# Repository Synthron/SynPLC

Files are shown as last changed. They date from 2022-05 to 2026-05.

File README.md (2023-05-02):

# SynPLC

Open Source modular PLC with Microcontrollers

**WORK IN PROGRESS**

# To-Dos

## Repo

- [x] Rewrite documentation in english
- [x] add reviewed PCBs
- [ ] fill out tech specs of modules once programmed
- [ ] Cleanup Repo
  - [ ] better folder structure
  - [X] delete obsolete files

## Hardware

- [x] Order new PCBs with STM32s
- [x] Assemble new PCBs
- [ ] Test new hardware
  - [X] DO
  - [X] DI
  - [ ] AO
  - [ ] AI
  - [ ] XT
- [ ] New Modules
  - [ ] CPU V2
    - [X] Layout
    - [X] Review
    - [ ] Ordered
  - [ ] Relais Module
  - [ ] PWM Module

## Software

- [ ] Write Software for new PCBs
  - [ ] CPU
  - [ ] DO
  - [ ] DI
  - [ ] AO
  - [ ] AI
  - [ ] XT
- [ ] Porting of SR485 protocol to new hardware
  - [ ] Make it use Interrupts
  - [ ] Make it more efficient (processing)
  - [ ] implement failsafes when no answer
- [ ] Define and program CAN protocol
- [ ] Write generalized Code for CPU
- [ ] ~~define structured Text~~ (postponed)
- [ ] ~~import structured text and parse into running code~~ (postponed)

## Possible Fixes

- [x] ~~MAX485 with 5V supply voltage on all IO modules ?~~
  - changed to 3V3 on the CPU
- [x] DIs and DO (alt. switches) re-soldering (dead channels)
- [x] better connector for CPU
- [ ] parametrize RS485 lib a bit more (tbd)

## issues

- [x] weird additional bytes sent by slave after ACK and CS???
  - resolved

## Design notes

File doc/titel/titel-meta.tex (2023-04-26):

\makeatletter                       
\def\printauthor{         
    {\large \@author}}              
\makeatother
\author{
    Marco Müller \\ 
    \vspace*{12pt}
    gitlab.synthron.de \\
    \texttt{synthron@synthron.de}
    }

\renewcommand\epigraphflush{flushright}
\renewcommand\epigraphsize{\normalsize}
\setlength\epigraphwidth{0.7\textwidth}

\definecolor{Green}{gray}{0.55}

\newcommand\anglei{-45}
\newcommand\angleii{-45}
\newcommand\angleiii{-225}
\newcommand\angleiv{135}

\newcommand\titlepagedecoration{%
\begin{tikzpicture}[remember picture,overlay,shorten >= -10pt]

\coordinate (aux1) at ([yshift=-15pt]current page.north east);
\coordinate (aux2) at ([yshift=-410pt]current page.north east);
\coordinate (aux3) at ([xshift=-4.5cm]current page.north east);
\coordinate (aux4) at ([yshift=-150pt]current page.north east);

\begin{scope}[titlepagecolor!40,line width=12pt,rounded corners=12pt]
\draw
  (aux1) -- coordinate (a)
  ++(225:5) --
  ++(-45:5.1) coordinate (b);
\draw[shorten <= -10pt]
  (aux3) --
  (a) --
  (aux1);
\draw[opacity=0.6,titlepagecolor,shorten <= -10pt]
  (b) --
  ++(225:2.2) --
  ++(-45:2.2);
\end{scope}
\draw[titlepagecolor,line width=8pt,rounded corners=8pt,shorten <= -10pt]
  (aux4) --
  ++(225:0.8) --
  ++(-45:0.8);
\begin{scope}[titlepagecolor!70,line width=6pt,rounded corners=8pt]
\draw[shorten <= -10pt]
  (aux2) --
  ++(225:3) coordinate[pos=0.45] (c) --
  ++(-45:3.1);
\draw
  (aux2) --
  (c) --
  ++(135:2.5) --
  ++(45:2.5) --
  ++(-45:2.5) coordinate[pos=0.3] (d);   
\draw 
  (d) -- +(45:1);
\end{scope}
\end{tikzpicture}%
}
\newcommand\chapterdecoration{%
\begin{tikzpicture}[remember picture,overlay,shorten >= -10pt]
\coordinate (aux1) at ([yshift=-15pt]current page.north west);
\coordinate (aux2) at ([yshift=-310pt]current page.north west);
\coordinate (aux3) at ([xshift=4.5cm]current page.north west);
\coordinate (aux4) at ([yshift=-150pt]current page.north west);
\coordinate (aux5) at ([yshift=-535pt]current page.north west);
\coordinate (aux6) at ([yshift=-660pt]current page.north west);
\coordinate (aux7) at ([yshift=-630pt]current page.north west);
\coordinate (aux8) at ([xshift=-16.5cm]current page.south east);
\renewcommand\anglei{-135}
\renewcommand\angleii{135}
\renewcommand\angleiii{-45}
\renewcommand\angleiv{45}

\begin{scope}[titlepagecolor1!70,line width=6pt,rounded corners=8pt]
\draw[shorten <= -10pt]
  (aux2) --
  ++(\angleiii:3) coordinate[pos=0.4] (d) --
  ++(\anglei:3.1);

\draw
  (d) --
  ++(\angleiii:.1) --
 ++(\angleiii:1.7) --
  ++(\anglei:1.5) --
++(\angleiii:2.5) --
++(\anglei:2.5) --
++(\angleii:2) --
++(\angleiii:1.3) --
++(\anglei:1.3) 
 
coordinate[pos=0.3] (c); 
\begin{scope}[titlepagecolor1!40,line width=12pt,rounded corners=12pt]
\draw
  (aux7) -- coordinate (a)
  ++(\angleiii:5) --
  ++(\anglei:5.1) coordinate (b);
\draw[shorten <= -10pt]
  
  (b) -- 
++(\angleiv:2.5) --
++(\angleiii:5) 
  (aux8);
\draw[opacity=0.6,titlepagecolor1,shorten <= -10pt]
  (aux5) --
  ++(\angleiii:2.2) --
  ++(\anglei:2.2);
\draw[titlepagecolor1,line width=8pt,rounded corners=8pt,shorten <= -10pt]
  (aux6) --
  ++(\angleiii:0.8) --
  ++(\anglei:0.8);
\end{scope}
  
\end{scope}
\end{tikzpicture}%
}

% Old Code for reference
%
%
%
%\newcommand\titlepagedecoration{
%\begin{tikzpicture}[remember picture,overlay,shorten >= -10pt]
%
%\coordinate (aux1) at ([yshift=-15pt]current page.north east);
%\coordinate (aux2) at ([yshift=-410pt]current page.north east);
%\coordinate (aux3) at ([xshift=-4.5cm]current page.north east);
%\coordinate (aux4) at ([yshift=-150pt]current page.north east);
%
%\begin{scope}[titlepagecolor!40,line width=12pt,rounded corners=12pt]
%\draw
%  (aux1) -- coordinate (a)
%  ++(225:5) --
%  ++(-45:5.1) coordinate (b);
%\draw[shorten <= -10pt]
%  (aux3) --
%  (a) --
%  (aux1);
%\draw[opacity=0.6,titlepagecolor,shorten <= -10pt]
%  (b) --
%  ++(225:2.2) --
%  ++(-45:2.2);
%\end{scope}
%\draw[titlepagecolor,line width=8pt,rounded corners=8pt,shorten <= -10pt]
%  (aux4) --
%  ++(225:0.8) --
%  ++(-45:0.8);
%\begin{scope}[titlepagecolor!70,line width=6pt,rounded corners=8pt]
%\draw[shorten <= -10pt]
%  (aux2) --
%  ++(225:3) coordinate[pos=0.45] (c) --
%  ++(-45:3.1);
%\draw
%  (aux2) --
%  (c) --
%  ++(135:2.5) --
%  ++(45:2.5) --
%  ++(-45:2.5) coordinate[pos=0.3] (d);   
%\draw 
%  (d) -- +(45:1);
%\end{scope}
%\end{tikzpicture}
%}

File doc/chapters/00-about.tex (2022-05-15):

\chapter{About}

This document will describe the workings of the SynPLC.

The SynPLC is meant to be an OpenSource PLC system for home automation purposes. It can supply digital and analog IO as well as different modules for a variety of different applications, e.g. Phase-Fired Control of AC voltages. 

\section{The Origins}

This project was created of the idea that in theory one could build a LOGO!-type PLC system from Arduinos. After some research and a few failed attempts it evolved into the current state, using STM32 Microcontrollers. 

\section{License}
All resources and documents for the SynPLC project are distributed under the Creative Commons CC-BY-SA 4.0 license.

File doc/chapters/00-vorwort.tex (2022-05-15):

\chapter{Vorwort}
Die SynPLC entstand durch die Idee, einen 24V-kompatiblen Arduino zu entwickeln. Als festgestellt wurde, dass man damit eine LOGO nachbilden könnte, hat mich die Idee gefasst, eine eigene SPS zu entwickeln. 
Also wurden auf Gutdünken einige Konzepte gemacht und folgendes kam dabei raus.

Module V1.0: 
\begin{itemize}
    \item CPU-Modul
    \item DO-Modul
    \item DI-Modul
    \item AO-Modul
\end{itemize}

Folgende Module befinden sich noch in Planung:
\begin{itemize}
    \item AI-Modul
    \item Interface/PWM-Modul
    \item Phasenanschnittmodul
\end{itemize}

Für den Anfang werden die Programme dafür noch in C auf die CPU geflasht, später soll per Strukturiertem Text ein Programm per SD-Karte ladbar sein.

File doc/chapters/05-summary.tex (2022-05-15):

\chapter{Summary}

The SynPLC project is a PLC system using STM32 microcontrollers and off-the-shelf hardware. For the current version the following modules are available:

\begin{itemize}
    \item CPU module
    \item Digital Output module
    \item Digital Input module
    \item Analog Output module
    \item Analog Input module
    \item Triac PFC module
\end{itemize}

The following modules are planned, but not yet under development:

\begin{itemize}
    \item PWM module
    \item Relais module
    \item Thermocouple module
\end{itemize}

For further information and technical specs, please look into the section  "Modules".

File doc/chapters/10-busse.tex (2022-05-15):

\chapter{Bus-Systeme}
Die CPU unterstützt nativ zwei Bus-Physiken:
\begin{itemize}
    \item RS485
    \item CAN
\end{itemize}

Für die IO-Module V1 wird nur RS485 unterstützt. Dazu wird auf der CPU die Steckbrücke für den Backplane entsprechend gesetzt.

%\section{RS485}
%Der RS485-Bus ist für die IO-Module der V1 vorgesehen. Dieser ist einfach auch auf kleineren und günstigeren Controllern zu nutzen und bietet genug Sicherheit über längere Strecken durch seinen differentiellen Aufbau.

%Ursprünglich war angedacht, hier das ModBus RTU Protokoll zu nutzen, allerdings wurde dagegen entschieden und ein eigenes Protokoll entwickelt, was direkter ist und einige Funktionen mehr unterstützt. Auch sind die Funktionen auf die IO-Module zurechtgeschnitten.

%\subsection{Adressen}
%Es wird ein 8-bit Adressverfahren genutzt. Dies passt in die seriellen Buffer der Controller. Außerdem ist nicht vorgesehen, mehr als 32 Geräte eines Typs gleichzeitig zu benutzen. Damit die CPU von sich aus weiß, welches Modul auf welcher Adresse ist, sind die Adressen kodiert. 

%\begin{table}[h]
%    \centering
%\begin{tabular}{|c|c|}
%    \hline
%    Modul       &   Adressbereich   \\ \hline \hline
%    CPU         &   111X XXXX       \\ \hline
%    Inferface   &   001X XXXX       \\ \hline
%    Digital Out &   010X XXXX       \\ \hline
%%    Digital In  &   011X XXXX       \\ \hline
%    Analog Out  &   100X XXXX       \\ \hline
%    Analog In   &   101X XXXX       \\ \hline
%    PWM         &   110X XXXX       \\ \hline
%\end{tabular}
%\caption{Adressen RS485}
%\label{tab:Adressen RS485}
%\end{table}

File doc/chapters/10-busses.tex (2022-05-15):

\chapter{Busses}

Every module has at least one common bus connector connecting via ribbon cable to the other modules. Alongside the 5V and GND voltage supply there also is the communication bus lines. On the modules there are two different busses possible: RS485 and CAN. 

In order to maintain a stable communication, consider the use of twisted-pair ribbon cables.

Both are working on a custom protocol, which is easy to implement on other controllers too. 

\section{RS485}

\subsection{Baudrate and Transmission speed}
The RS485 bus is transceiving at 250kBaud. At a maximum of 10 Bytes per frame, this results in a minimum rate of around 3000 frames per second.

\subsection{Frame Structure}
The frame structure of the protocol is as follows:
\vspace{0.5cm}

\begin{tabular}{cl}
    \textbf{Byte Number}     & \textbf{Data}                      \\
    1               & Startbyte (0x5A)          \\
    2               & Slave Adress              \\
    3               & Instruction and Register  \\
    4               & Data (Not used when Instruction == Scan or Read) \\
    5               & Data (only used at 12- or 16bit data blocks) \\
    6               & Checksum \\
    \\
    7               & Answer from Slave (ACK or NACK with Error code) \\
    8               & Answer from Slave (data, LSB at 12- or 16bit data blocks) \\
    9               & Answer from Slave (data, MSB at 12- or 16bit data blocks) \\
    10              & Answer from Slave (Checksum)
\end{tabular}
\vspace{0.5cm}

As you can see, most of the frame consists of the CPU talking to the slaves. Startbyte and Checksums are in place to make sure that an error free communication is possible. 

The Checksum itself is easily calculated. This is done by XOR-ing all sent bytes with the constant value 0xC5. In summary, the equation is as follows:

\begin{equation}
    Checksum = 0xC5 \oplus Byte\_1 \oplus Byte\_2 \oplus Byte\_3 (\oplus Byte\_4 \oplus Byte\_5)
\end{equation}

Equally, the slaves are calculating their checksum with the same method, XOR-ing all their bytes with 0xC5. 

If all the bytes are XOR-ed with each other and with the checksum itself and 0xC5 is still left, then the communication was error free and the data is uncompromized.

\subsection{Slave Addresses}
The slave addresses are an 8bit number which consist of a 3-bit module identifier and a 5-bit address settable via dip-switches on the respective module.

The module identifiers are definied as follows:

\begin{table}[H]
    \centering
        \begin{tabular}{|c|c|}
            \hline
            Identifier & Modul \\ \hline \hline
            000 & Digital Input \\ \hline
            001 & Digital Output \\ \hline
            010 & Analog Input \\ \hline
            011 & Analog Output \\ \hline
            100 & PWM Modul \\ \hline
            101 & Thyristor Modul \\ \hline
            110 & Relais Modul \\ \hline
            111 & \textit{reserved}    \\ \hline
        \end{tabular}
\end{table}

\subsection{Instructions}

In Byte 3 of the communication protocol are the instruction and the corresponding register specified. For more information on the registers, please refer to the corresponing module section in this document.

The instructions are at the 4 MSBs of the byte. They are as follows:

\begin{table}[H]
    \centering
        \begin{tabular}{|c|c|}
            \hline
            Instruction-Code & Instruction \\ \hline \hline
            0000 xxxx   & Bus Scanning (is slave available?) - no data byte \\ \hline
            0001 (reg)  & Read 8bit-Register\\ \hline
            0010 (reg)  & Write 8bit-Register \\ \hline
            0101 (reg)  & Read 16bit-Register \\ \hline
            0110 (reg)  & Write 16bit-Register \\ \hline
        \end{tabular}
\end{table}

\subsection{ACK, NACK and Error Codes}
In order to know weather the communication was successful, there is a byte used specifically for ACK/NACK and Error codes. This byte is divided into 2 nibbles, where the first nibble is the ACK/NACK and the second nibble is the error code. If everything is fine, the ACK nibble will be 0xC0 (1100). If there is an error present, it will display the NACK status with 0x03 (0011).

The following nibble will show which exactly went wrong:

\begin{table}[H]
    \centering
        \begin{tabular}{|c|c|}
            \hline
            Error Code & Meaning \\ \hline \hline
            0000 & No Error \\ \hline
            0001 & Target Register invalid \\ \hline
            0010 & Instruction invalid \\ \hline
            1100 & Processing Error - read Error Register \\ \hline
            1101 & Checksum Error - Send again \\ \hline
            1111 & System Error - read Error Register \\ \hline
        \end{tabular}
\end{table}

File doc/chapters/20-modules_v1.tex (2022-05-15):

\chapter{Modules V1}
All V1 modules are now discontinued. The successors are the V2 modules.

\vspace{2cm}

\textbf{Further information:}

V1 was meant to be a Proof of Concept system using easy-to-program ATmega328P with Arduino framework. 

The Hardware was not as refined as wanted and a lot of compromises were made resulting in high production costs and hard-to-source parts. 

\chapter{Modules V2}
These are the current module revisions. If not stated otherwise, every module is powered by a STM32F103 microcontroller. 

Every module is capable of both CAN and RS485, but not simultaneously. To select one of the two bus systems, set the Jumpers on the boards accodingly.

\vspace{1cm}

V2 was designed with the mindset of more generic circuitry without losing accuracy or stability. Even tho not every module was improved (talking about you, DO8...) major steps were made on the analog modules. In addition, the triac module (XP) is in testing now.

Also all V1 modules got discontinued and decommissioned.\pagebreak

\section{CPU}
The CPU is the heart of the PLC system and necessary for normal operation. It connects to all IO-modules and processes all the data.

The CPU has the following interfaces:

\begin{itemize}
    \item RS485 and CAN Businterface
    \item USB-Interface for serial monitor
    \item ESP01-Modul as Webinterface (read-only as of now)
    \item SD-card for structured text (WIP) and log files
    \item DC/DC-Converter as power supply for the whole system
\end{itemize}

The DC/DC-Converter uses an ESD-safe 24V DC-input to generate 5V DC at 10W output power. This voltage is available at the bus connector and providing power to all modules in the system.

It has no seperate ID since it is a one-of-a-kind module. In later revisions, there will be measures for redundancy available, but not for now.

\section{DO8}
The DO8 (Digital Output 8-channel) is providing 8 channels of 24V compatible outputs with a current rating of 0.5A each. The channels are galvanically isolated from the system voltage via optoisolators. 

The 24V Output voltage has to be supplied on the connector. 

To prevent major faults caused by short circuits, the output channels are measured back and compared to their set value. If a channel differs from its value, the module sets an error bit and shuts off the faulty channel.

On the front are 8 LEDs, indicating the status of the output channels. 

%hier noch die Register beschreiben

\section{DI}
The DI8 (Digital Input 8-channel) is providing 8 channels of 24V compatiple inputs, divided into two sets of 4 Inputs where both sets are galvanically isolated from each other. The maximum input current is limited to 2mA. The channels are galvanically isolated from the system voltage via optoisolators.

For normal operation, the system ground fromt the inputs need to be connected. 

The channels are ESD safe and can tolerate up to 33V DC. Reverse-Polarity and overcurrent protections are in place. 

A digital Low-Level is defined as 0..5 VDC.

A digital HIGH-Level is defined as 10..33 VDC.

% Hier die Register beschreiben

\section{AO}
The AO4 (Analog Output 4-channel) is providing 4 channels of analog output, each capable of supplying either 0..10V CV or 0..20mA CC at a resolution of 12bits. The switch between CV and CC is managed by a relay.

The output resolution is set at 16bits, giving a 0.15mV or 0.30$\mu$A resolution. 

The channels are electrically isolated from the system, so at least 15V with common analog grond have to be provided.

On the front are 4 LEDs indicating if the channel is actively being used. 

% Hier die Register beschreiben

\section{AI}
The AI4 (Analog Input 4-channel) is providing 4 channels of analog inputs, capable of meauring 0..10V or 0..20mA each. 

The input resolution is set at 12bits. At a maximum input volatage of 10V or input current of 20mA, this is giving a resolution of 2.4mV or 4.8mA.

The channels are electrically isolated from the system.

\section{XT}
The XT4 (Interface Triac 4-channel) is providing 4 triacs on two seperate voltage domains. The channels can be used to either switch AC voltage to a supply or even using them in a PFC (phase-fired controller) mode. 

For PFC mode each voltage domain has a Zero-Crossing-Detection (ZCD) and can control the triacs with PWM. The ZCD also calculates the frequency of the AC voltage automatically and compensates for frequency drift. 

Each channel is rated for up to 230V and 1A. Keep in mind that the triacs can become quite hot. 

All channels are electrically isolated from the system. The two voltage domains are also isolated from each other.

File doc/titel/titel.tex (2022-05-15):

\begin{titlepage}

\vspace*{2cm}
\noindent
\titlefont \Titel\par
\epigraph{\Caption}
{\SignateAuthor\\ \Stand}
\vspace*{2cm}
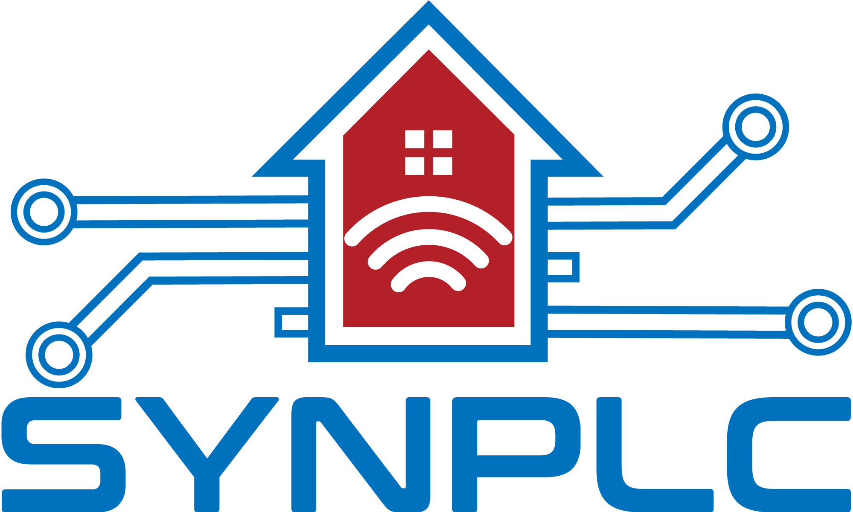
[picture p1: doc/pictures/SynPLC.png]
\centering{}
\null\vfill
\vspace*{1cm}
\noindent
\hfill
\begin{minipage}{0.4\linewidth}
    \begin{flushright}
        \printauthor
    \end{flushright}
\end{minipage}
%
\begin{minipage}{0.02\linewidth}
    \rule{1pt}{80pt}
\end{minipage}
\titlepagedecoration
\chapterdecoration
\end{titlepage}

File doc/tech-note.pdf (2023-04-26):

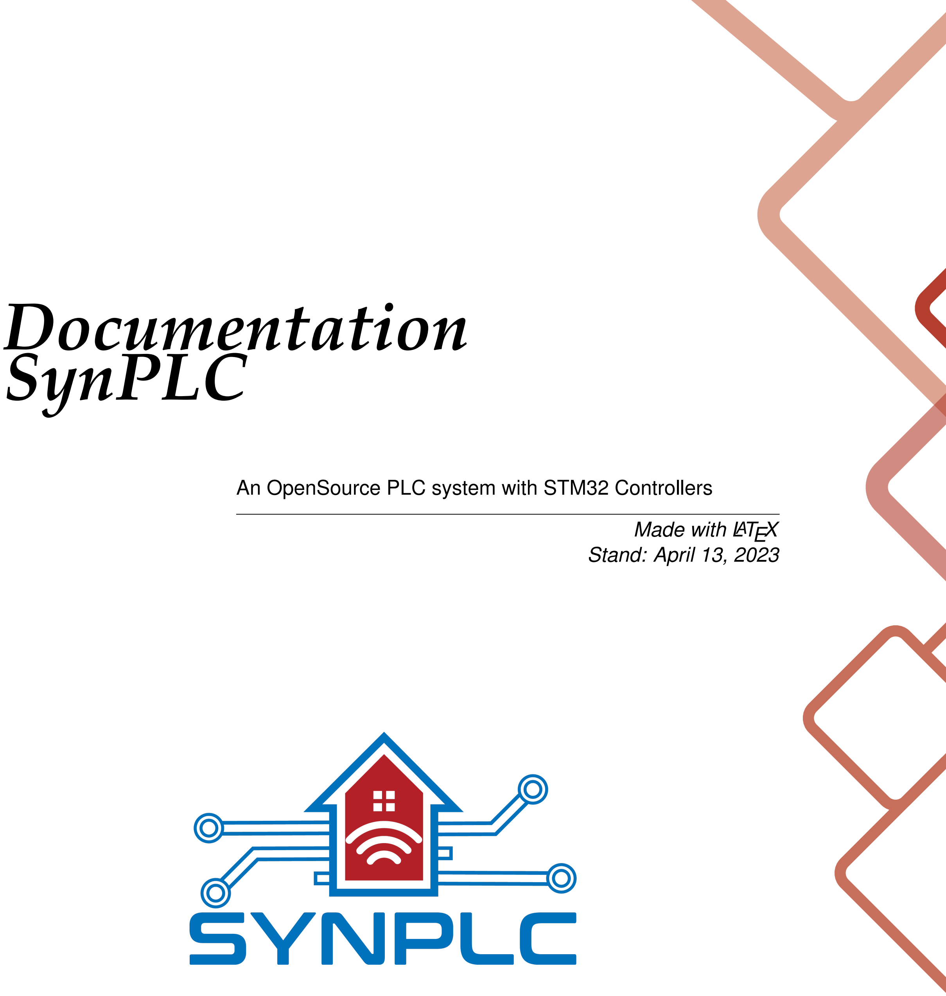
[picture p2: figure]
Documentation SynPLC; Made with LATEX Stand: April 13, 2023

An OpenSource PLC system with STM32 Controllers

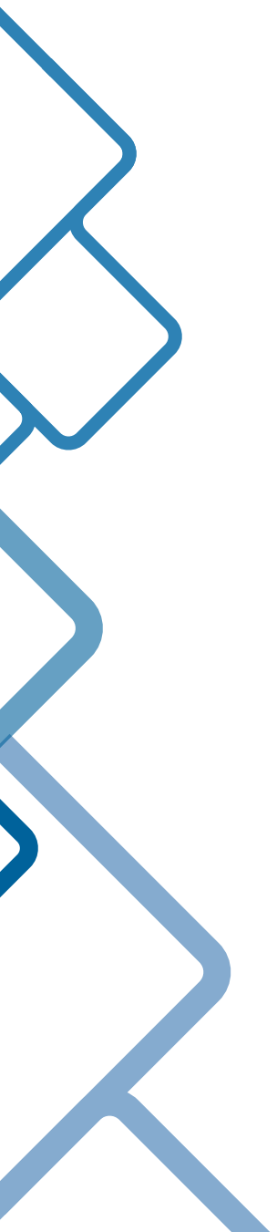
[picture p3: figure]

Marco Muller ¨

gitlab.synthron.de
synthron@synthron.de

I. Table of Contents

# Contents

I. List of Figures | II
II. List of Tables | III
1. About | 1
2. Summary | 2
3. Busses | 3
4. Modules V1 | 6
5. Modules V2 | 7

I

II. List of Tables

# I. List of Figures

II

III. List of Figures

# II. List of Tables

III

April 13, 2023 | SynPLC V2.0 | Marco Muller ¨

# 1. About

This document will describe the workings of the SynPLC.

The SynPLC is meant to be an OpenSource PLC system for home automation purposes. It can supply digital and analog IO as well as different modules for a variety of different applications, e.g. Phase-Fired Control of AC voltages.

## 1.1. The Origins

This project was created of the idea that in theory one could build a LOGO!-type PLC system from Arduinos. After some research and a few failed attempts it evolved into the current state, using STM32 Microcontrollers.

## 1.2. License

All resources and documents for the SynPLC project are distributed under the Creative Commons CC-BY-SA 4.0 license.

# 2. Summary

The SynPLC project is a PLC system using STM32 microcontrollers and off-the-shelf hardware. For the current version the following modules are available:

- CPU module
- Digital Output module
- Digital Input module
- Analog Output module
- Analog Input module
- Triac PFC module

The following modules are planned, but not yet under development:

- PWM module
- Relais module
- Thermocouple module

For further information and technical specs, please look into the section ”Modules”.

# 3. Busses

Every module has at least one common bus connector connecting via ribbon cable to the other modules. Alongside the 5V and GND voltage supply there also is the communication bus lines. On the modules there are two different busses possible: RS485 and CAN.

In order to maintain a stable communication, consider the use of twisted-pair ribbon cables.

Both are working on a custom protocol, which is easy to implement on other controllers too.

## 3.1. RS485

### 3.1.1. Baudrate and Transmission speed

The RS485 bus is transceiving at 250kBaud. At a maximum of 10 Bytes per frame, this results in a minimum rate of around 3000 frames per second.

### 3.1.2. Frame Structure

The frame structure of the protocol is as follows:

Byte Number Data
1 | Startbyte (0x5A)
2 | Slave Adress
3 | Instruction and Register
4 | Data (Not used when Instruction == Scan or Read)
5 | Data (only used at 12- or 16bit data blocks)
6 | Checksum
7 | Answer from Slave (ACK or NACK with Error code)
8 | Answer from Slave (data, LSB at 12- or 16bit data blocks)
9 | Answer from Slave (data, MSB at 12- or 16bit data blocks)
10 | Answer from Slave (Checksum)

As you can see, most of the frame consists of the CPU talking to the slaves. Startbyte and Checksums are in place to make sure that an error free communication is possible.

The Checksum itself is easily calculated. This is done by XOR-ing all sent bytes with the constant value 0xC5. In summary, the equation is as follows:

Checksum = 0xC5 ⊕ Byte 1 ⊕ Byte 2 ⊕ Byte 3(⊕Byte 4 ⊕ Byte 5) (3.1)

Equally, the slaves are calculating their checksum with the same method, XOR-ing all their bytes with 0xC5.

If all the bytes are XOR-ed with each other and with the checksum itself and 0xC5 is still left, then the communication was error free and the data is uncompromized.

### 3.1.3. Slave Addresses

The slave addresses are an 8bit number which consist of a 3-bit module identifier and a 5-bit address settable via dip-switches on the respective module.

The module identifiers are definied as follows:

Identifier | Modul
000 | Digital Input
001 | Digital Output
010 | Analog Input
011 | Analog Output
100 | PWM Modul
101 | Thyristor Modul
110 | Relais Modul
111 | reserved

### 3.1.4. Instructions

In Byte 3 of the communication protocol are the instruction and the corresponding register specified. For more information on the registers, please refer to the corresponing module section in this document.

The instructions are at the 4 MSBs of the byte. They are as follows:

Instruction-Code | Instruction
0000 xxxx | Bus Scanning (is slave available?) - no data byte
0001 (reg) | Read 8bit-Register
0010 (reg) | Write 8bit-Register
0101 (reg) | Read 16bit-Register
0110 (reg) | Write 16bit-Register

### 3.1.5. ACK, NACK and Error Codes

In order to know weather the communication was successful, there is a byte used specifically for ACK/NACK and Error codes. This byte is divided into 2 nibbles, where the first nibble is the ACK/NACK and the second nibble is the error code. If everything is fine, the ACK nibble will be 0xC0 (1100). If there is an error present, it will display the NACK status with 0x03 (0011).

The following nibble will show which exactly went wrong:

Error Code | Meaning
0000 | No Error
0001 | Target Register invalid
0010 | Instruction invalid
1100 | Processing Error - read Error Register
1101 | Checksum Error - Send again
1111 | System Error - read Error Register

# 4. Modules V1

All V1 modules are now discontinued. The successors are the V2 modules.

Further information:

V1 was meant to be a Proof of Concept system using easy-to-program ATmega328P with Arduino framework.

The Hardware was not as refined as wanted and a lot of compromises were made resulting in high production costs and hard-to-source parts.

# 5. Modules V2

These are the current module revisions. If not stated otherwise, every module is powered by a STM32F103 microcontroller.

Every module is capable of both CAN and RS485, but not simultaneously. To select one of the two bus systems, set the Jumpers on the boards accodingly.

V2 was designed with the mindset of more generic circuitry without losing accuracy or stability. Even tho not every module was improved (talking about you, DO8...) major steps were made on the analog modules. In addition, the triac module (XP) is in testing now.

Also all V1 modules got discontinued and decommissioned.

## 5.1. CPU

The CPU is the heart of the PLC system and necessary for normal operation. It connects to all IO-modules and processes all the data.

The CPU has the following interfaces:

- RS485 and CAN Businterface
- USB-Interface for serial monitor
- ESP01-Modul as Webinterface (read-only as of now)
- SD-card for structured text (WIP) and log files
- DC/DC-Converter as power supply for the whole system

The DC/DC-Converter uses an ESD-safe 24V DC-input to generate 5V DC at 10W output power. This voltage is available at the bus connector and providing power to all modules in the system.

It has no seperate ID since it is a one-of-a-kind module. In later revisions, there will be measures for redundancy available, but not for now.

## 5.2. DO8

The DO8 (Digital Output 8-channel) is providing 8 channels of 24V compatible outputs with a current rating of 0.5A each. The channels are galvanically isolated from the system voltage via optoisolators.

The 24V Output voltage has to be supplied on the connector.

To prevent major faults caused by short circuits, the output channels are measured back and compared to their set value. If a channel differs from its value, the module sets an error bit and shuts off the faulty channel.

On the front are 8 LEDs, indicating the status of the output channels.

## 5.3. DI

The DI8 (Digital Input 8-channel) is providing 8 channels of 24V compatiple inputs, divided into two sets of 4 Inputs where both sets are galvanically isolated from each other. The maximum input current is limited to 2mA. The channels are galvanically isolated from the system voltage via optoisolators.

For normal operation, the system ground fromt the inputs need to be connected.

The channels are ESD safe and can tolerate up to 33V DC. Reverse-Polarity and overcurrent protections are in place.

A digital Low-Level is defined as 0..5 VDC.

A digital HIGH-Level is defined as 10..33 VDC.

## 5.4. AO

The AO4 (Analog Output 4-channel) is providing 4 channels of analog output, each capable of supplying either 0..10V CV or 0..20mA CC at a resolution of 12bits. The switch between CV and CC is managed by a relay.

The output resolution is set at 16bits, giving a 0.15mV or 0.30μA resolution.

The channels are electrically isolated from the system, so at least 15V with common analog grond have to be provided.

On the front are 4 LEDs indicating if the channel is actively being used.

## 5.5. AI

The AI4 (Analog Input 4-channel) is providing 4 channels of analog inputs, capable of meauring 0..10V or 0..20mA each.

The input resolution is set at 12bits. At a maximum input volatage of 10V or input current of 20mA, this is giving a resolution of 2.4mV or 4.8mA.

The channels are electrically isolated from the system.

## 5.6. XT

The XT4 (Interface Triac 4-channel) is providing 4 triacs on two seperate voltage domains. The channels can be used to either switch AC voltage to a supply or even using them in a PFC (phase-fired controller) mode.

For PFC mode each voltage domain has a Zero-Crossing-Detection (ZCD) and can control the triacs with PWM. The ZCD also calculates the frequency of the AC voltage automatically and compensates for frequency drift.

Each channel is rated for up to 230V and 1A. Keep in mind that the triacs can become quite hot.

All channels are electrically isolated from the system. The two voltage domains are also isolated from each other.

# Appendix

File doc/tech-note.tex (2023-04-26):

\documentclass[11pt, a4paper, listof=numbered, captions=tableheading, headinclude, table, xcdraw]{scrreprt}

\usepackage[utf8]{inputenc}
\usepackage{tikz}
\usepackage{epigraph}
\usepackage{amsmath}
\usepackage{textgreek}
\usepackage[LGRgreek]{mathastext}
\usepackage{array}
\usepackage{color}
\usepackage{graphicx}
\usepackage{float}
\usepackage{helvet}
\usepackage{scrhack}
%\usepackage{circuitikz}
\renewcommand{\familydefault}{\sfdefault}

\setlength{\emergencystretch}{\hsize}
%\tolerance=9999
 
\newcounter{divide}

% für referenziertes Inhaltsverzeichnis
\usepackage[hidelinks, hypertexnames=false]{hyperref}

\usepackage{chngcntr}
\counterwithin*{chapter}{divide}

\renewcommand\epigraphflush{flushright}
\renewcommand\epigraphsize{\normalsize}
\setlength\epigraphwidth{0.7\textwidth}

\definecolor{titlepagecolor1}{cmyk}{1,.39,.0,.27}
\definecolor{titlepagecolor}{cmyk}{0,.82,.78,.30}

\DeclareFixedFont{\titlefont}{T1}{ppl}{b}{it}{0.5in}

\setlength{\parindent}{0pt}
\setlength{\parskip}{\baselineskip}

% Seitenränder festlegen
\usepackage[top=1.5cm,bottom=1.5cm, includeheadfoot]{geometry}

% ---------------------------------------
% Titeldefinition
\newcommand{\Titel}{Documentation\\SynPLC}
\newcommand{\Caption}{An OpenSource PLC system with STM32 Controllers}
\newcommand{\SignateAuthor}{\textit{Made with \LaTeX}}
\newcommand{\Stand}{\textit{Stand: \today}}
% Sonstiges in titel.ltx und titel-meta.ltx
% ---------------------------------------

% Kopf- und Fußzeile
\usepackage[automark]{scrlayer-scrpage}

% --------------------------------------------------------------------
% Titelblatt
% --------------------------------------------------------------------

\input{titel/titel-meta.tex}
\begin{document}
\input{titel/titel.tex}

% --------------------------------------------------------------------
% Verzeichnisse
% --------------------------------------------------------------------

\pagenumbering{Roman}
\renewcommand{\thechapter}{\Roman{chapter}}

\setcounter{tocdepth}{2} %Ausblenden von Subsections etc..
\cohead[I. Table of Contents]{I. Table of Contents}
\pagestyle{scrheadings}
\tableofcontents 	\newpage
\cohead[II. List of Tables]{II. List of Tables}
\pagestyle{scrheadings}
\listoffigures 		\newpage
\cohead[III. List of Figures]{III. List of Figures}
\pagestyle{scrheadings}
\listoftables 		\newpage
\pagenumbering{arabic}

\stepcounter{divide}

\renewcommand{\thechapter}{\arabic{chapter}}

% Kopfzeilen erst nach den Verzeichnissen

\lohead[\today]{\today}
\cohead[SynPLC V2.0]{SynPLC V2.0}
\rohead[Marco Müller]{Marco Müller}
\pagestyle{scrheadings}
 
% --------------------------------------------------------------------
% Ab hier der Inhalt
% --------------------------------------------------------------------

\input{chapters/00-about.tex} 				\newpage 	% Vorwort
\input{chapters/05-summary.tex}				\newpage
\input{chapters/10-busses.tex}				\newpage	% Bus Erklärung
\input{chapters/20-modules_v1.tex} 			\newpage	% Module V1

% --------------------------------------------------------------------
% abschließende Verzeichnisse
% --------------------------------------------------------------------

\pagestyle{empty}
\vspace*{\fill}
\begin{center}
\hrulefill\\
\vspace{4mm}
	\begin{HUGE}
		\textbf{Appendix}
	\end{HUGE}\\
\hrulefill
\end{center}
\vspace*{\fill}
\newpage
\pagestyle{plain}

\appendix

% --------------------------------------------------------------------
\end{document}

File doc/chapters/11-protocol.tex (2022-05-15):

\chapter{Protokoll RS485}

\begin{tabular}{lll}
Frame & & \\
&	byte 1:& 	Startbyte (0x5A) \\
&	byte 2:&	Slave adress \\
&	byte 3:& 	Instruction and register \\
&	byte 4:& 	data (not send when instruction == Scan or read) \\
&	byte 5:& 	data (only send when writing 16bit (MSB) register) \\
&	byte 6:& 	Checksum \\
&&	\\
&	byte 7:& 	Answer from slave (ACK or (NACK $\vert$ Errorcode)) \\
&	byte 8:& 	Answer from slave (data, 8bit read or LSB when 16bit read) \\
&	byte 9:& 	Answer from slave (data, MSB when 16bit read) \\
&	byte 10:& 	Answer from slave (Checksum) \\
\end{tabular}

Hier wird das Protokoll der RS485-Schnittstelle beschrieben.

\section{Genereller Aufbau}

\subsection{Baudrate}

Der RS485-Bus wird mit einer Baudrate von 250.000 Baud betrieben.

\section{Protokoll}
\subsection{Ablauf}
Je gesamtem Frame (eine erfolgreiche Datenübertragung) werden 3-5 Byte übertragen. Dieses Frame setzt sich wie folgt zusammen:
\begin{itemize}
    \item von CPU:
    \begin{enumerate}
        \item Slave-Adresse (1 Byte)
        \item Befehl und Register (1 Byte)
        \item Daten (1 oder 2 Byte)
    \end{enumerate}
    \item von Slave
    \begin{enumerate}
        \item ACK und Fehlercode (1 Byte)
    \end{enumerate}
\end{itemize}

Je nach Slave können mehrere Frames für die vollständige Datenübertragung vonnöten sein. 

\subsection{Slave-Adresse}
Die Slave-Adresse besteht aus 2 Teilen:
\begin{itemize}
    \item Modul-Identifier (3 bit)
    \item Adresse ( 5 bit)
\end{itemize}

Der Modul-Identifier ist in Software festgelegt und bezeichnet die Art des Moduls:

\begin{table}[H]
    \centering
        \begin{tabular}{|c|c|}
            \hline
            Identifier & Modul \\ \hline \hline
            000 & Digital Input \\ \hline
            001 & Digital Output \\ \hline
            010 & Analog Input \\ \hline
            011 & Analog Output \\ \hline
            100 & PWM Modul \\ \hline
            101 & Thyristor Modul \\ \hline
            110 & Relais Modul \\ \hline
            111 & \textit{reserviert}    \\ \hline
        \end{tabular}
\end{table}

Die 5bit-Adresse wird über die Codierschalter am Slave vorgenommen.

\subsection{Befehl und Register}

Die Befehle und Register werden in einem Byte zusammengeführt. Beide Teile sind je 4 bit lang. Die Befehle setzen sich dabei wie folgt zusammen:

\begin{table}[H]
    \centering
        \begin{tabular}{|c|c|}
            \hline
            Befehl-Code & Befehl \\ \hline \hline
            0000 xxxx   & Bus Scanning (ist der Slave anwesend?) - kein Datenbyte \\ \hline
            0001 (reg)  & Lese 8bit-Register\\ \hline
            0010 (reg)  & Schreibe 8bit-Register \\ \hline
            0101 (reg)  & Lese 16bit-Register \\ \hline
            0110 (reg)  & schreibe 16bit-Register \\ \hline
        \end{tabular}
\end{table}

Die Register sind dabei modulabhängig. Folgend sind die Register aufgelistet:

\subsubsection{Digital Output}
\begin{table}[H]
    \centering
        \begin{tabular}{|c|c|}
            \hline
            Registeradresse & Funktion \\ \hline \hline
            0001 & Output-Register \\ \hline
            0010 & Input-Register \\ \hline
            1111 & Fehlerregister \\ \hline
        \end{tabular}
\end{table}

\subsubsection{Digital Input}
\begin{table}[H]
    \centering
        \begin{tabular}{|c|c|}
            \hline
            Registeradresse & Funktion \\ \hline \hline
            0010 & Input-Register \\ \hline
            1111 & Fehlerregister \\ \hline
        \end{tabular}
\end{table}

\subsubsection{Analog Output}
\begin{table}[H]
    \centering
        \begin{tabular}{|c|c|}
            \hline
            Registeradresse & Funktion \\ \hline \hline
            0001 & Channel-Enable-Register \\ \hline
            0010 & Spannung Channel 1 (16 bit) \\ \hline
            0011 & Strom Channel 1 (16 bit)\\ \hline
            0100 & Spannung Channel 2 (16 bit)\\ \hline
            0101 & Strom Channel 2 (16 bit)\\ \hline
            0110 & Spannung Channel 3 (16 bit)\\ \hline
            0111 & Strom Channel 3 (16 bit)\\ \hline
            1001 & Spannung Channel 4 (16 bit)\\ \hline
            1010 & Strom Channel 4 (16 bit)\\ \hline
            1100 & Channel-Status-Register \\ \hline
            1101 & Channel-Fehler-Register \\ \hline
            1111 & Fehlerregister \\ \hline
        \end{tabular}
\end{table}

\subsection{ACK und Fehlercode}
Damit sichergestellt werden kann, dass die Daten alle richtig empfangen wurden, werden ACK (Acknowledge) und Fehlercodes gesendet. Diese werden in einem Byte zusammen geschickt und bestehen aus je 4bit.

Ein positives Acknowledge wird mit dem Hex-Code 5 (0101) codiert, ein negatives Acknowledge (NACK) wird mit A (1010) codiert. die Fehlercodes setzen sich dabei wie folgt zusammen:

\begin{table}[H]
    \centering
        \begin{tabular}{|c|c|}
            \hline
            Fehlercode & Bedeutung \\ \hline \hline
            0000 & Kein Fehler \\ \hline
            0001 & Ziel-Register nicht bekannt \\ \hline
            0010 & Befehl nicht bekannt \\ \hline
            1100 & Prozessfehler - Fehlerspeicher auslesen \\ \hline
            1101 & Prüfsummenfehler - Sende erneut \\ \hline
            1111 & Systemfehler - Fehlerspeicher auslesen \\ \hline
        \end{tabular}
\end{table}

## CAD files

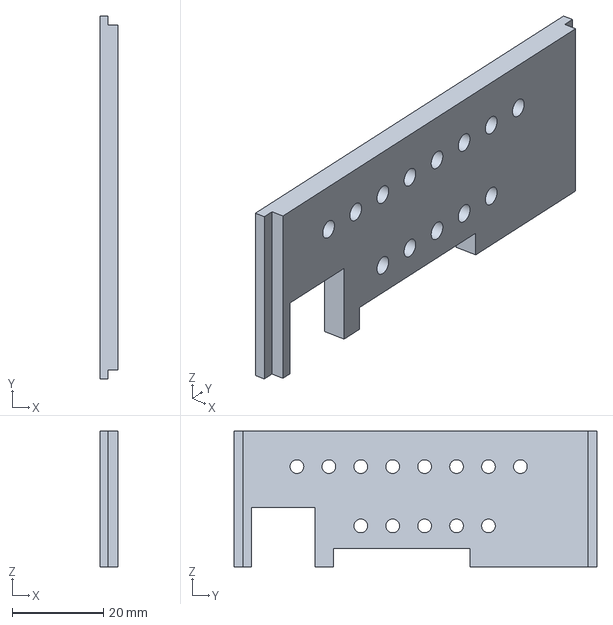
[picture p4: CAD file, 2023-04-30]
hardware/case/CPU_Case_PiggyBack-FrontCover.3mf
4.00 x 79.6 x 29.8 mm

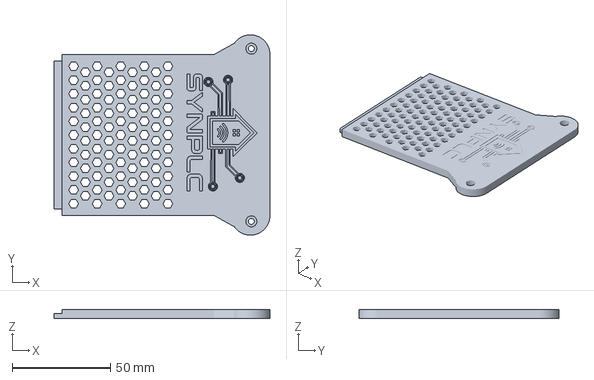
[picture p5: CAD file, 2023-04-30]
hardware/case/CPU_Case_PiggyBack-cover_logo.3mf
110.0 x 102.0 x 4.75 mm

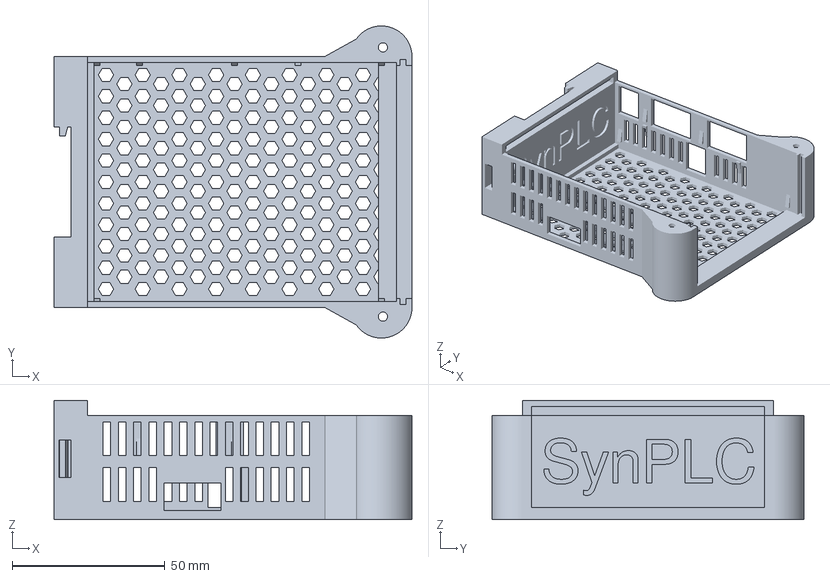
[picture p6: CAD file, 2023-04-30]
hardware/case/CPU_Case_PiggyBack-Case_CPU_PiggyBack.3mf
117.0 x 102.0 x 39.0 mm

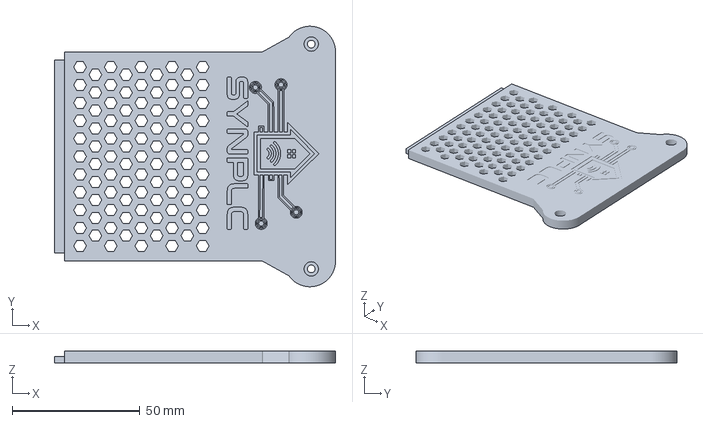
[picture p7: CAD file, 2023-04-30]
hardware/case/CPU_Case_PiggyBack-cover_logo_nfc.3mf
110.0 x 102.0 x 4.75 mm

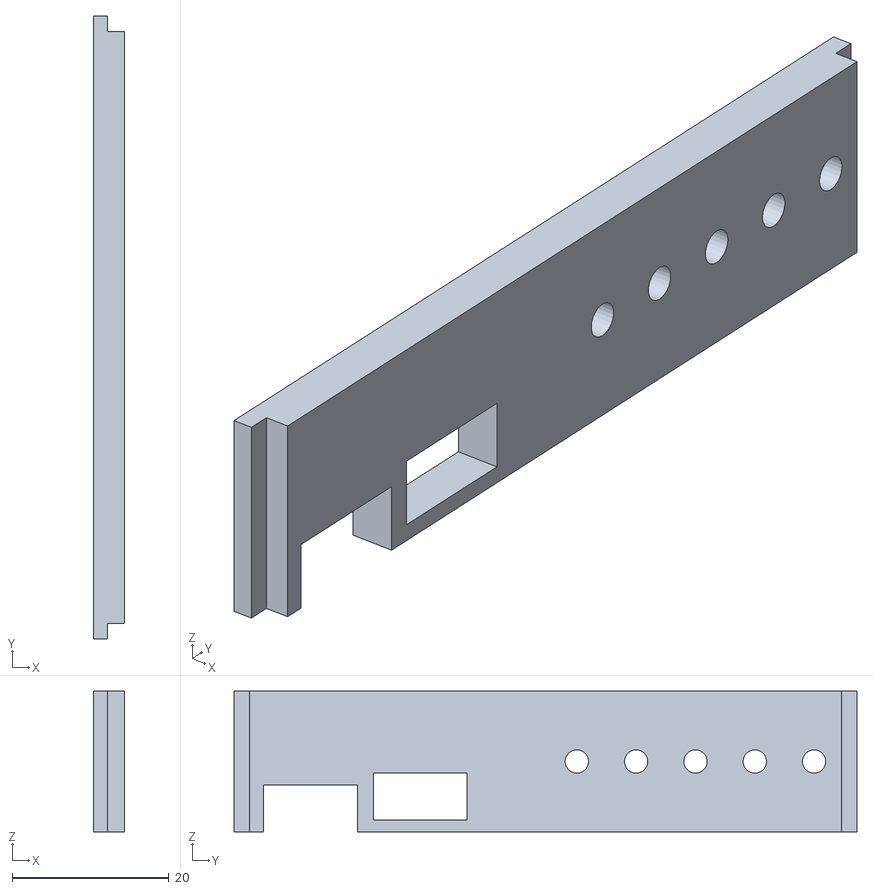
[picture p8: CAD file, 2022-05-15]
hardware/case/Gehaeuse-front_cpu.stl
4.00 x 79.6 x 18.0

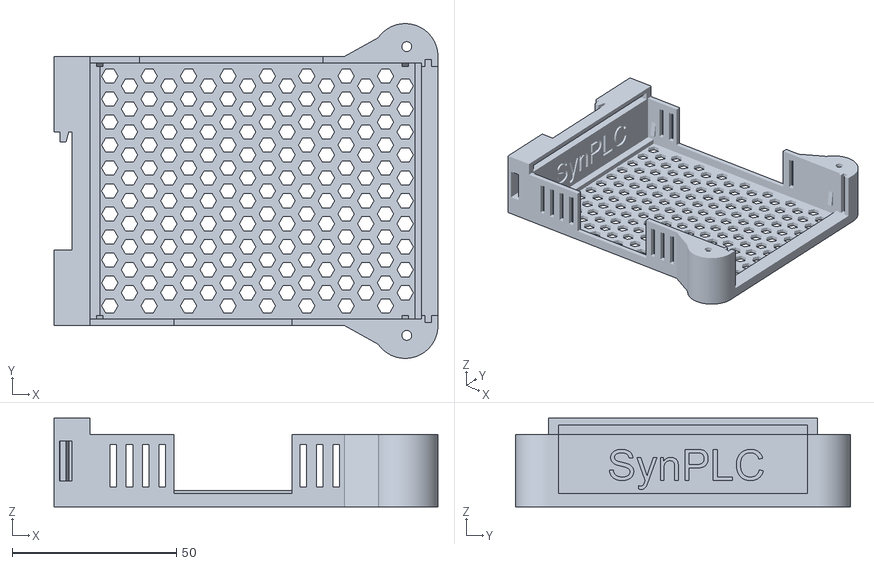
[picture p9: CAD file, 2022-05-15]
hardware/case/Gehaeuse-new_base_5_slits_digital.stl
117.0 x 102.0 x 27.0

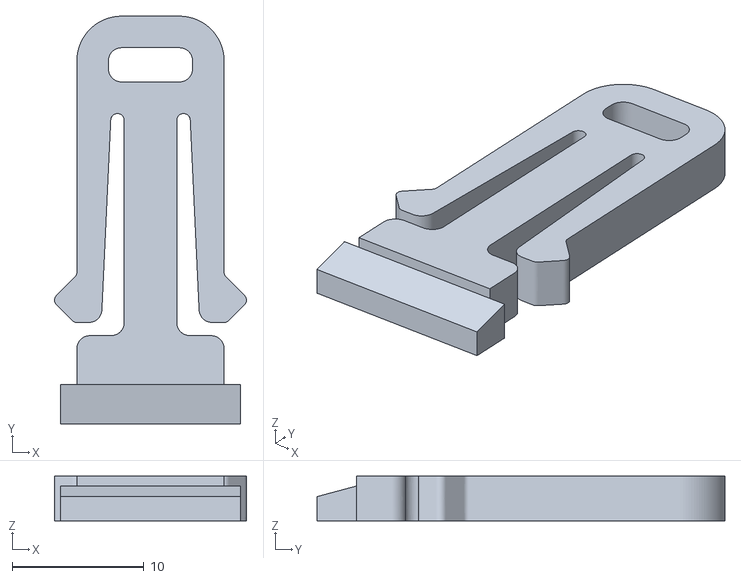
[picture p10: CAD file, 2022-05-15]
hardware/case/clip.stl
14.6 x 31.0 x 3.40

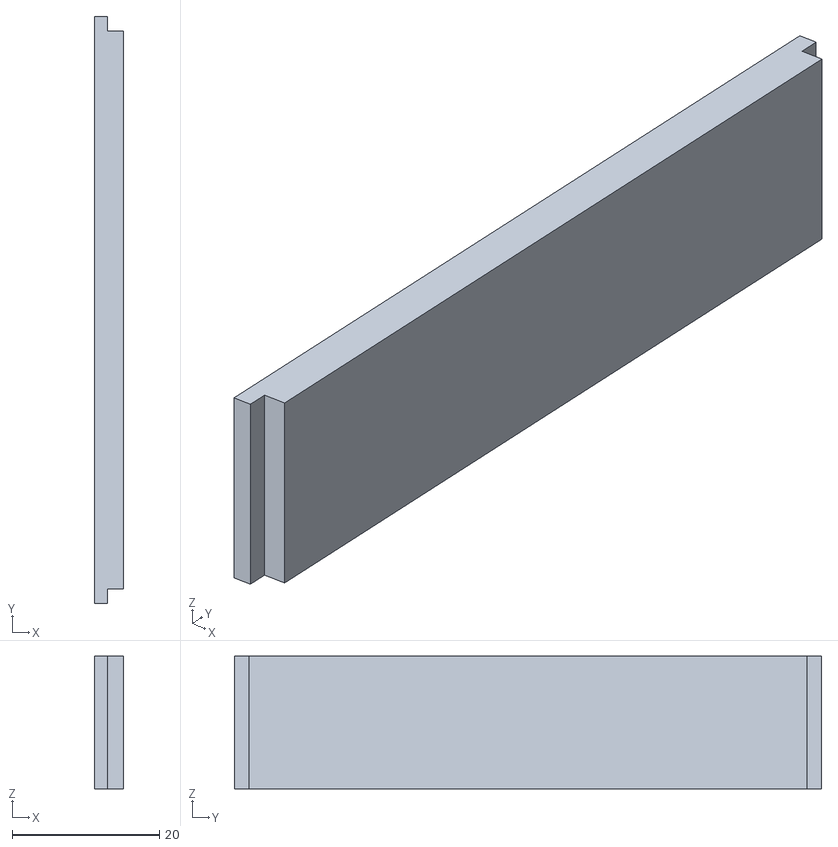
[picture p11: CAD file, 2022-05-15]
hardware/case/Gehaeuse-front.stl
4.00 x 79.6 x 18.0

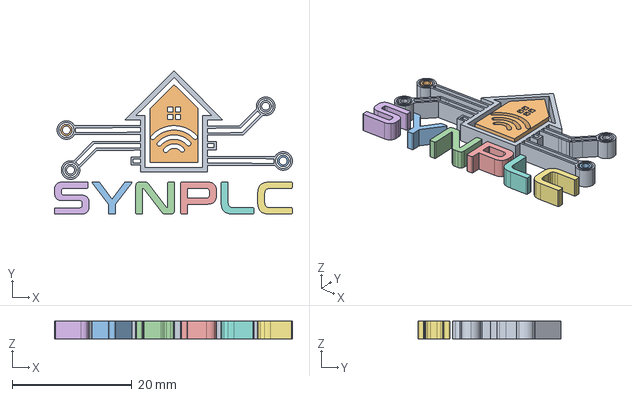
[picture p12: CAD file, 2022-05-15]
hardware/case/logo.step
39.7 x 23.9 x 3.00 mm

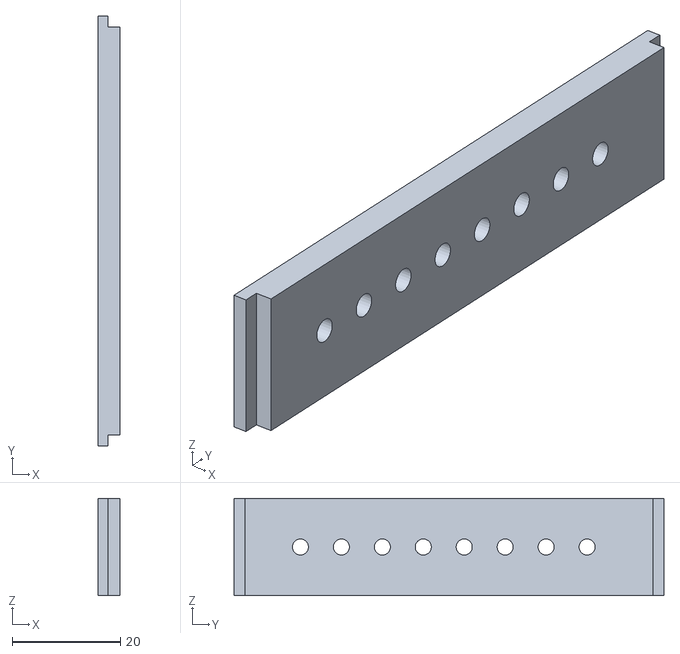
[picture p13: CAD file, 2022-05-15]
hardware/case/Gehaeuse-front_led_8.stl
4.00 x 79.6 x 18.0

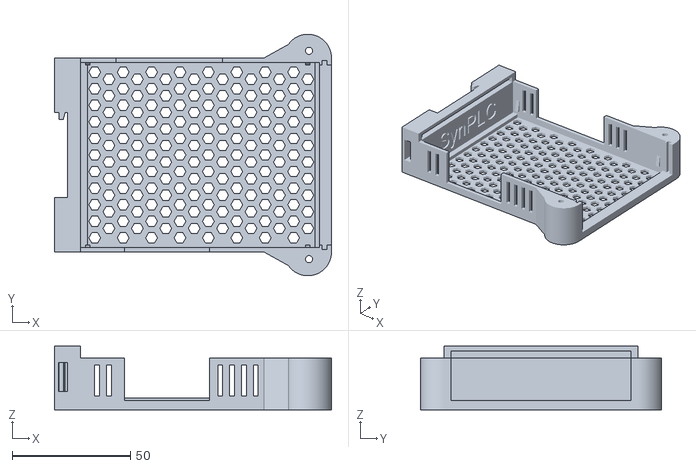
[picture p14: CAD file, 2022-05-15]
hardware/case/Gehaeuse-new_base_4_slits.stl
117.0 x 102.0 x 27.0

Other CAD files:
hardware/case/Gehaeuse-front_led_4.stl
hardware/case/Gehaeuse-cover_logo.stl
hardware/case/Gehaeuse-new_base_5_slits_alternative.stl
hardware/case/logo.stl

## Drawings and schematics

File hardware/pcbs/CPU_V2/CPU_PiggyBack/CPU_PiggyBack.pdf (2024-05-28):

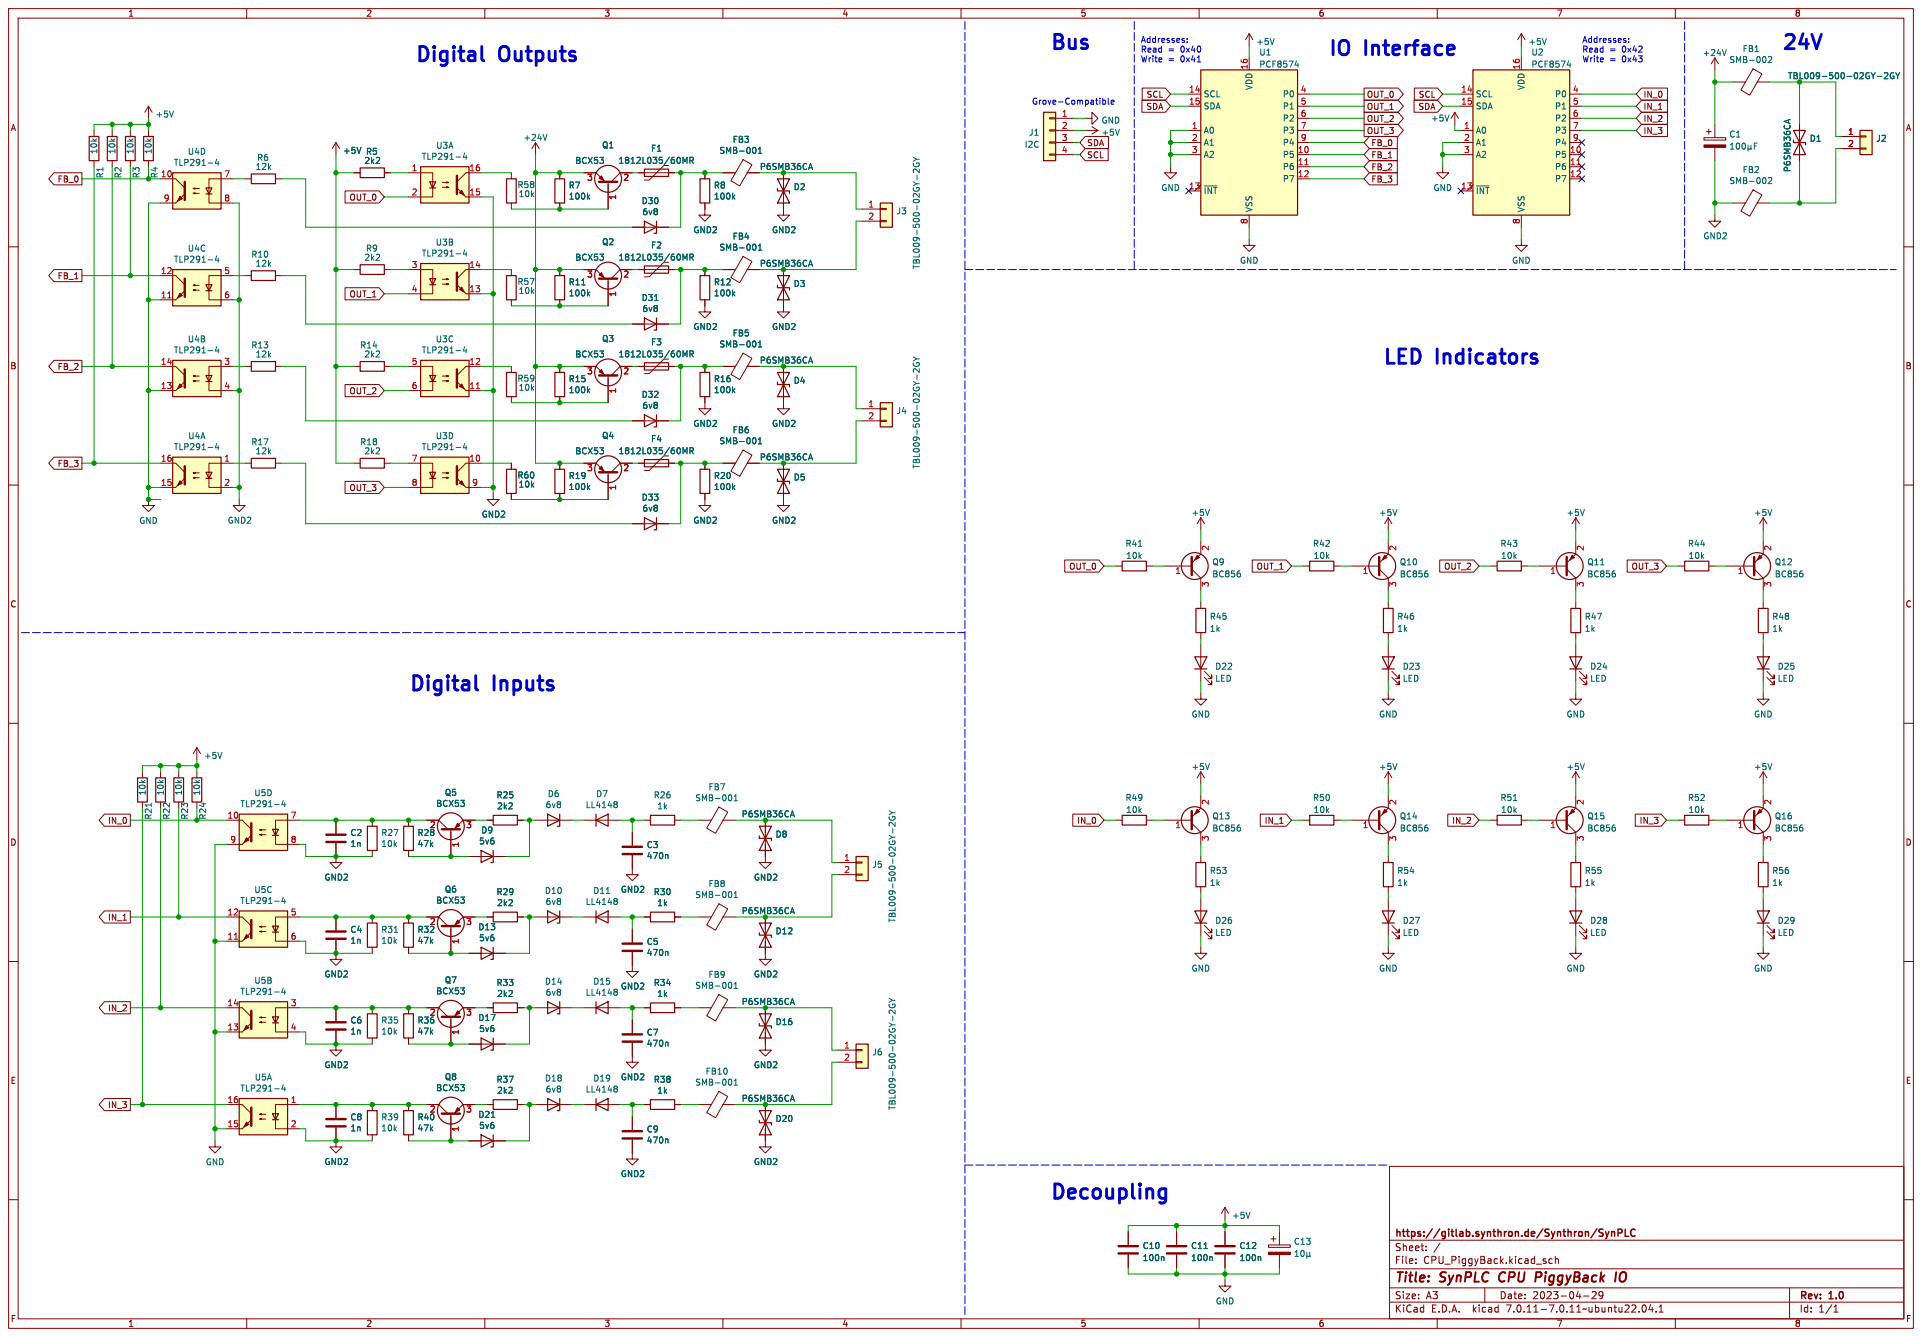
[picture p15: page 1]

File: CPU_PiggyBack.kicad_sch Sheet: / https://gitlab.synthron.de/Synthron/SynPLC

Id: 1/1 Title: SynPLC CPU PiggyBack IO

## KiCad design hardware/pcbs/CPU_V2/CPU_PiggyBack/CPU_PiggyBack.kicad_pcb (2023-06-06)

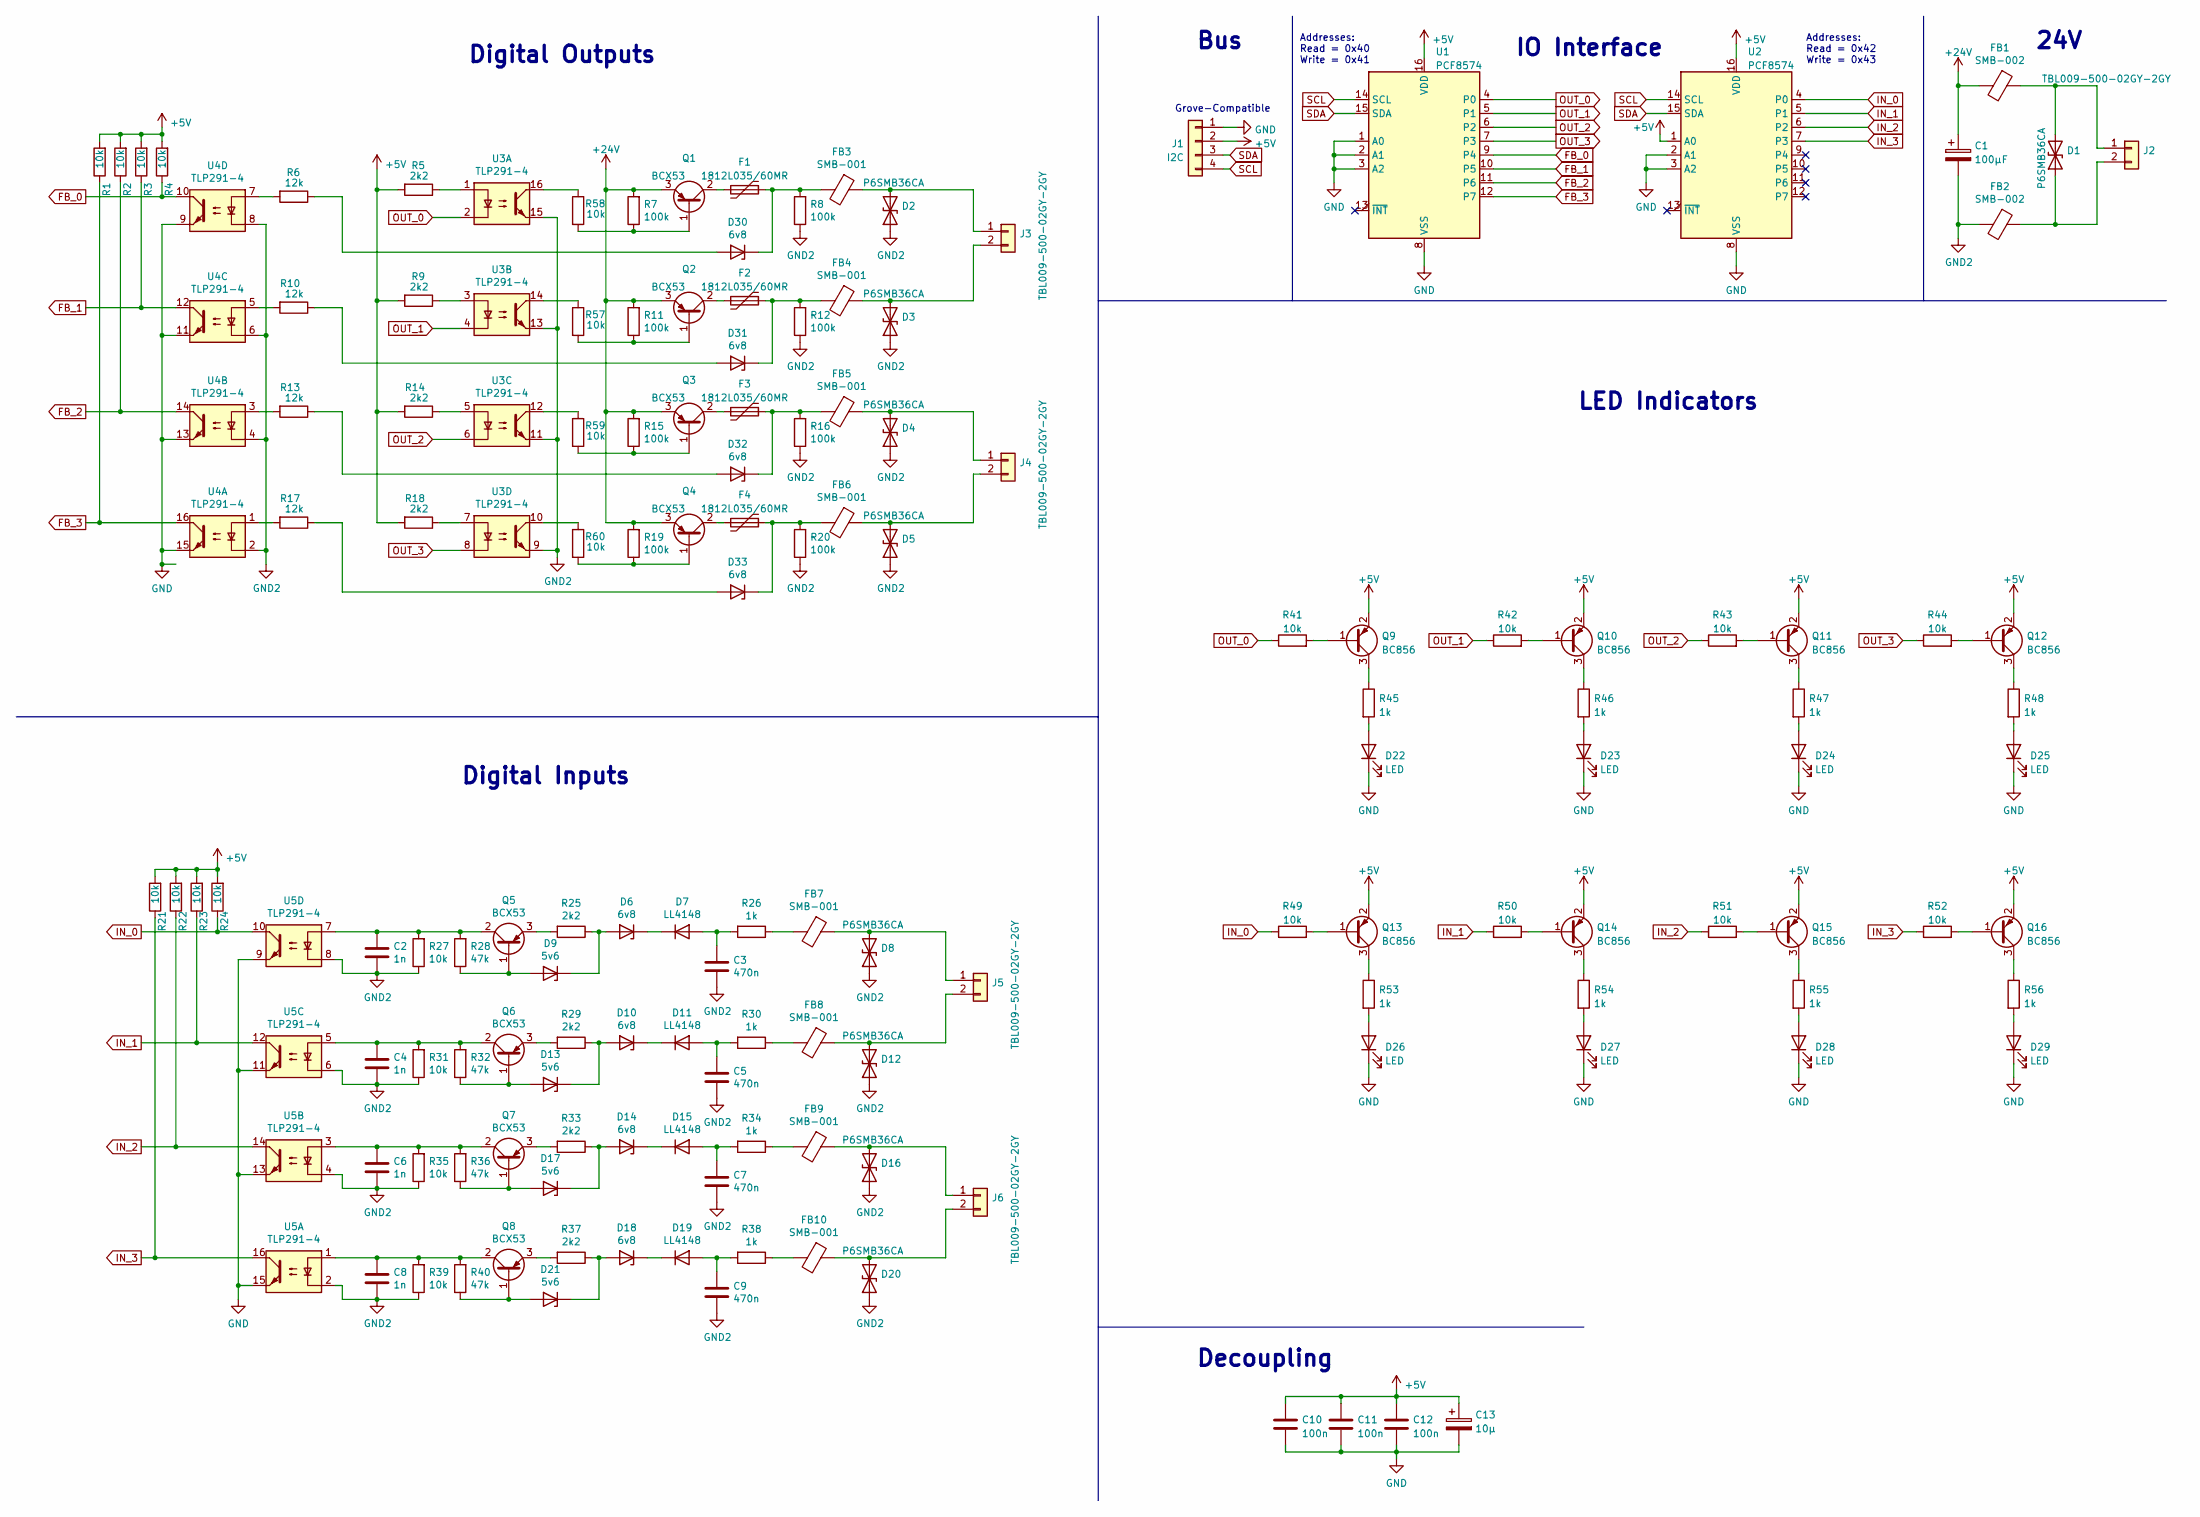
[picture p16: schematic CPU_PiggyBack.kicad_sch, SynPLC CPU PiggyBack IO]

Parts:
C1: 100µF; CP_Elec_5x5.8
C2, C4, C6, C8: 1n; C_0805_2012Metric
C3, C5, C7, C9: 470n; C_0805_2012Metric
C10, C11, C12: 100n; C_0805_2012Metric
C13: 10µ; CP_Elec_5x5.8
D1, D2, D3, D4, D5, D8, D12, D16, D20: P6SMB36CA; D_SMA
D6, D10, D14, D18, D30, D31, D32, D33: 6v8; D_MiniMELF
D7, D11, D15, D19: LL4148; D_MiniMELF
D9, D13, D17, D21: 5v6; D_MiniMELF
D22, D23, D24, D25, D26, D27, D28, D29: LED; LED_D3.0mm
F1, F2, F3, F4: 1812L035/60MR; R_1812_4532Metric
FB1, FB2: SMB-002
FB3, FB4, FB5, FB6, FB7, FB8, FB9, FB10: SMB-001
J1: I2C; PinSocket_1x04_P2.54mm_Vertical
J2, J3, J4, J5, J6: TBL009-500-02GY-2GY; TBL00950002GY2GY
Q1, Q2, Q3, Q4, Q5, Q6, Q7, Q8: BCX53; SOT-89-3
Q9, Q10, Q11, Q12, Q13, Q14, Q15, Q16: BC856; SOT-23
R1, R2, R3, R4, R21, R22, R23, R24, R27, R31, R35, R39, R41, R42, R43, R44, R49, R50, R51, R52, R57, R58, R59, R60: 10k; R_0805_2012Metric
R5, R9, R14, R18, R25, R29, R33, R37: 2k2; R_0805_2012Metric
R6, R10, R13, R17: 12k; R_0805_2012Metric
R7, R8, R11, R12, R15, R16, R19, R20: 100k; R_0805_2012Metric
R26, R30, R34, R38, R45, R46, R47, R48, R53, R54, R55, R56: 1k; R_0805_2012Metric
R28, R32, R36, R40: 47k; R_0805_2012Metric
U1, U2: PCF8574; SOIC-16W_7.5x10.3mm_P1.27mm
U3, U4, U5: TLP291-4; SOIC-16_4.55x10.3mm_P1.27mm

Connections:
+5V: C10.1, C11.1, C12.1, C13.1, J1.2, Q9.2 (E), Q10.2 (E), Q11.2 (E), Q12.2 (E), Q13.2 (E), Q14.2 (E), Q15.2 (E), Q16.2 (E), R1.2, R2.2, R3.2, R4.2, R5.2, R9.2, R14.2, R18.2, R21.2, R22.2, R23.2, R24.2, U1.16 (VDD), U2.1 (A0), U2.16 (VDD)
+24V: C1.1, FB1.2, Q1.3 (E), Q2.3 (E), Q3.3 (E), Q4.3 (E), R7.2, R11.2, R15.2, R19.2
FB_0: R4.1, U1.9 (P4), U4.10
FB_1: R3.1, U1.10 (P5), U4.12
FB_2: R2.1, U1.11 (P6), U4.14
FB_3: R1.1, U1.12 (P7), U4.16
GND: C10.2, C11.2, C12.2, C13.2, D22.1 (K), D23.1 (K), D24.1 (K), D25.1 (K), D26.1 (K), D27.1 (K), D28.1 (K), D29.1 (K), J1.1, U1.1 (A0), U1.2 (A1), U1.3 (A2), U1.8 (VSS), U2.2 (A1), U2.3 (A2), U2.8 (VSS), U4.9, U4.11, U4.13, U4.15, U5.9, U5.11, U5.13, U5.15
GND2: C1.2, C2.1, C3.1, C4.1, C5.1, C6.1, C7.1, C8.1, C9.1, D2.1 (A1), D3.1 (A1), D4.1 (A1), D5.1 (A1), D8.1 (A1), D12.1 (A1), D16.1 (A1), D20.1 (A1), FB2.2, R8.1, R12.1, R16.1, R20.1, R27.1, R31.1, R35.1, R39.1, U3.9, U3.11, U3.13, U3.15, U4.2, U4.4, U4.6, U4.8, U5.2, U5.4, U5.6, U5.8
IN_0: R24.1, R49.1, U2.4 (P0), U5.10
IN_1: R23.1, R50.1, U2.5 (P1), U5.12
IN_2: R22.1, R51.1, U2.6 (P2), U5.14
IN_3: R21.1, R52.1, U2.7 (P3), U5.16
unnamed: C2.2, Q5.2 (C), R27.2, R28.2, U5.7
unnamed: C3.2, D7.2 (A), R26.2
unnamed: C4.2, Q6.2 (C), R31.2, R32.2, U5.5
unnamed: C5.2, D11.2 (A), R30.2
unnamed: C6.2, Q7.2 (C), R35.2, R36.2, U5.3
unnamed: C7.2, D15.2 (A), R34.2
unnamed: C8.2, Q8.2 (C), R39.2, R40.2, U5.1
unnamed: C9.2, D19.2 (A), R38.2
unnamed: D1.1 (A1), FB2.1, J2.2
unnamed: D1.2 (A2), FB1.1, J2.1
unnamed: D2.2 (A2), FB3.1, J3.1
unnamed: D3.2 (A2), FB4.1, J3.2
unnamed: D4.2 (A2), FB5.1, J4.1
unnamed: D5.2 (A2), FB6.1, J4.2
unnamed: D6.1 (K), D7.1 (K)
unnamed: D6.2 (A), D9.1 (K), R25.1
unnamed: D8.2 (A2), FB7.1, J5.1
unnamed: D9.2 (A), Q5.1 (B), R28.1
unnamed: D10.1 (K), D11.1 (K)
unnamed: D10.2 (A), D13.1 (K), R29.1
unnamed: D12.2 (A2), FB8.1, J5.2
unnamed: D13.2 (A), Q6.1 (B), R32.1
unnamed: D14.1 (K), D15.1 (K)
unnamed: D14.2 (A), D17.1 (K), R33.1
unnamed: D16.2 (A2), FB9.1, J6.1
unnamed: D17.2 (A), Q7.1 (B), R36.1
unnamed: D18.1 (K), D19.1 (K)
unnamed: D18.2 (A), D21.1 (K), R37.1
unnamed: D20.2 (A2), FB10.1, J6.2
unnamed: D21.2 (A), Q8.1 (B), R40.1
unnamed: D22.2 (A), R45.2
unnamed: D23.2 (A), R46.2
unnamed: D24.2 (A), R47.2
unnamed: D25.2 (A), R48.2
unnamed: D26.2 (A), R53.2
unnamed: D27.2 (A), R54.2
unnamed: D28.2 (A), R55.2
unnamed: D29.2 (A), R56.2
unnamed: D30.1 (K), F1.1, FB3.2, R8.2
unnamed: D30.2 (A), R6.1
unnamed: D31.1 (K), F2.1, FB4.2, R12.2
unnamed: D31.2 (A), R10.1
unnamed: D32.1 (K), F3.1, FB5.2, R16.2
unnamed: D32.2 (A), R13.1
unnamed: D33.1 (K), F4.1, FB6.2, R20.2
unnamed: D33.2 (A), R17.1
unnamed: F1.2, Q1.2 (C)
unnamed: F2.2, Q2.2 (C)
unnamed: F3.2, Q3.2 (C)
unnamed: F4.2, Q4.2 (C)
unnamed: FB7.2, R26.1
unnamed: FB8.2, R30.1
unnamed: FB9.2, R34.1
unnamed: FB10.2, R38.1
unnamed: Q1.1 (B), R7.1, R58.2
unnamed: Q2.1 (B), R11.1, R57.2
unnamed: Q3.1 (B), R15.1, R59.2
unnamed: Q4.1 (B), R19.1, R60.2
unnamed: Q5.3 (E), R25.2
unnamed: Q6.3 (E), R29.2
unnamed: Q7.3 (E), R33.2
unnamed: Q8.3 (E), R37.2
unnamed: Q9.1 (B), R41.2
unnamed: Q9.3 (C), R45.1
unnamed: Q10.1 (B), R42.2
unnamed: Q10.3 (C), R46.1
unnamed: Q11.1 (B), R43.2
unnamed: Q11.3 (C), R47.1
unnamed: Q12.1 (B), R44.2
unnamed: Q12.3 (C), R48.1
unnamed: Q13.1 (B), R49.2
unnamed: Q13.3 (C), R53.1
unnamed: Q14.1 (B), R50.2
unnamed: Q14.3 (C), R54.1
unnamed: Q15.1 (B), R51.2
unnamed: Q15.3 (C), R55.1
unnamed: Q16.1 (B), R52.2
unnamed: Q16.3 (C), R56.1
unnamed: R5.1, U3.1
unnamed: R6.2, U4.7
unnamed: R9.1, U3.3
unnamed: R10.2, U4.5
unnamed: R13.2, U4.3
unnamed: R14.1, U3.5
unnamed: R17.2, U4.1
unnamed: R18.1, U3.7
unnamed: R57.1, U3.14
unnamed: R58.1, U3.16
unnamed: R59.1, U3.12
unnamed: R60.1, U3.10
OUT_0: R41.1, U1.4 (P0), U3.2
OUT_1: R42.1, U1.5 (P1), U3.4
OUT_2: R43.1, U1.6 (P2), U3.6
OUT_3: R44.1, U1.7 (P3), U3.8
SCL: J1.4, U1.14 (SCL), U2.14 (SCL)
SDA: J1.3, U1.15 (SDA), U2.15 (SDA)

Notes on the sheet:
IO Interface
Decoupling
Digital Outputs
Addresses: Read = 0x42 Write = 0x43
Grove-Compatible
24V
Addresses: Read = 0x40 Write = 0x41
Bus
LED Indicators
Digital Inputs

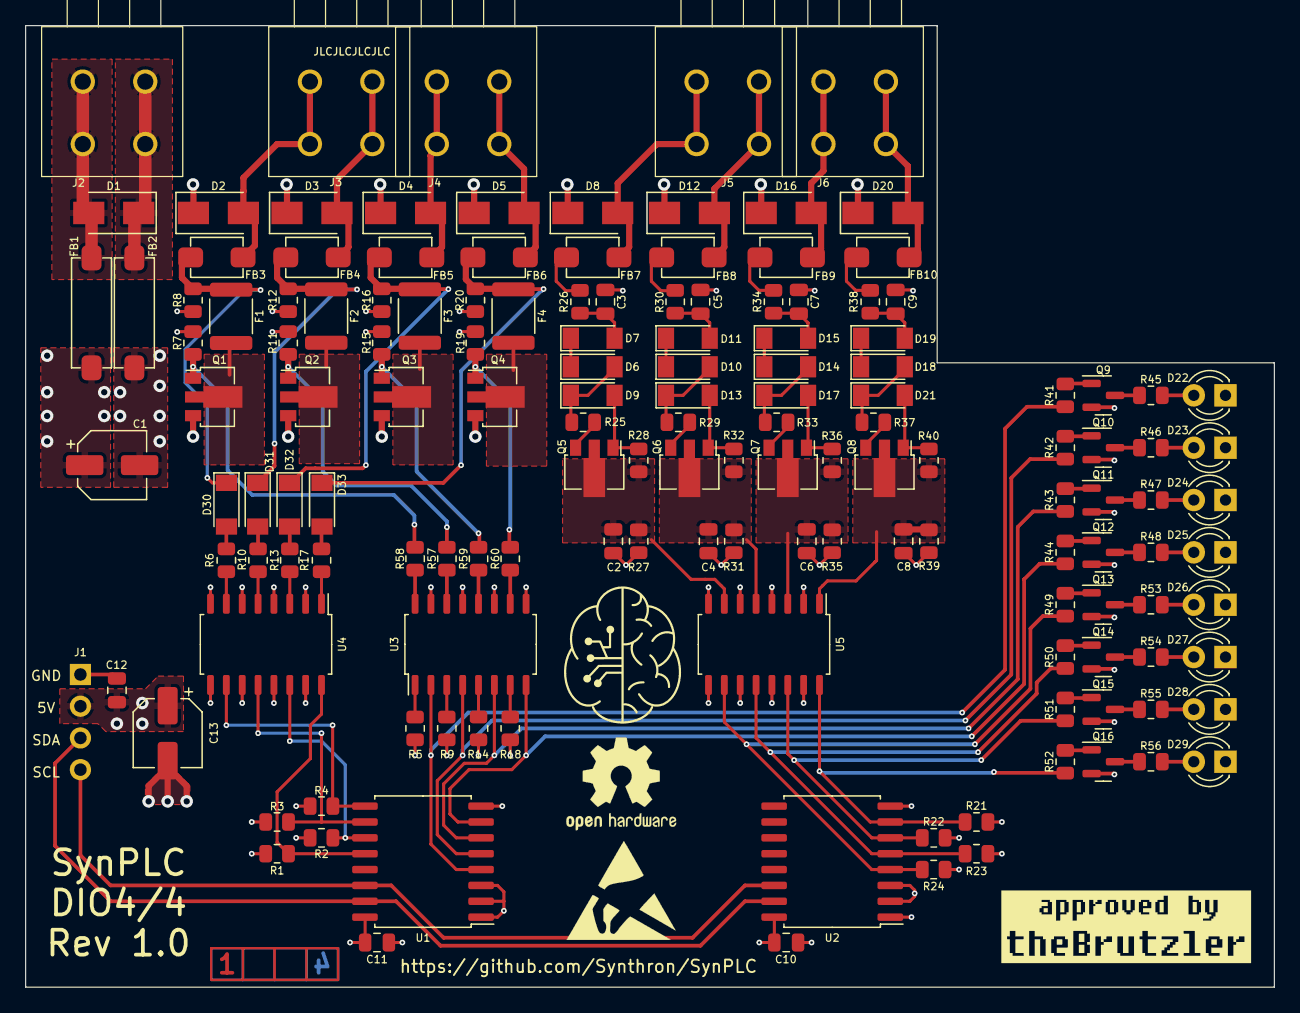
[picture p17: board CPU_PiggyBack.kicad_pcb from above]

Board: 4 copper layers, 100.0 x 77.0 mm, 147 parts (1 on the bottom side), 108 nets.

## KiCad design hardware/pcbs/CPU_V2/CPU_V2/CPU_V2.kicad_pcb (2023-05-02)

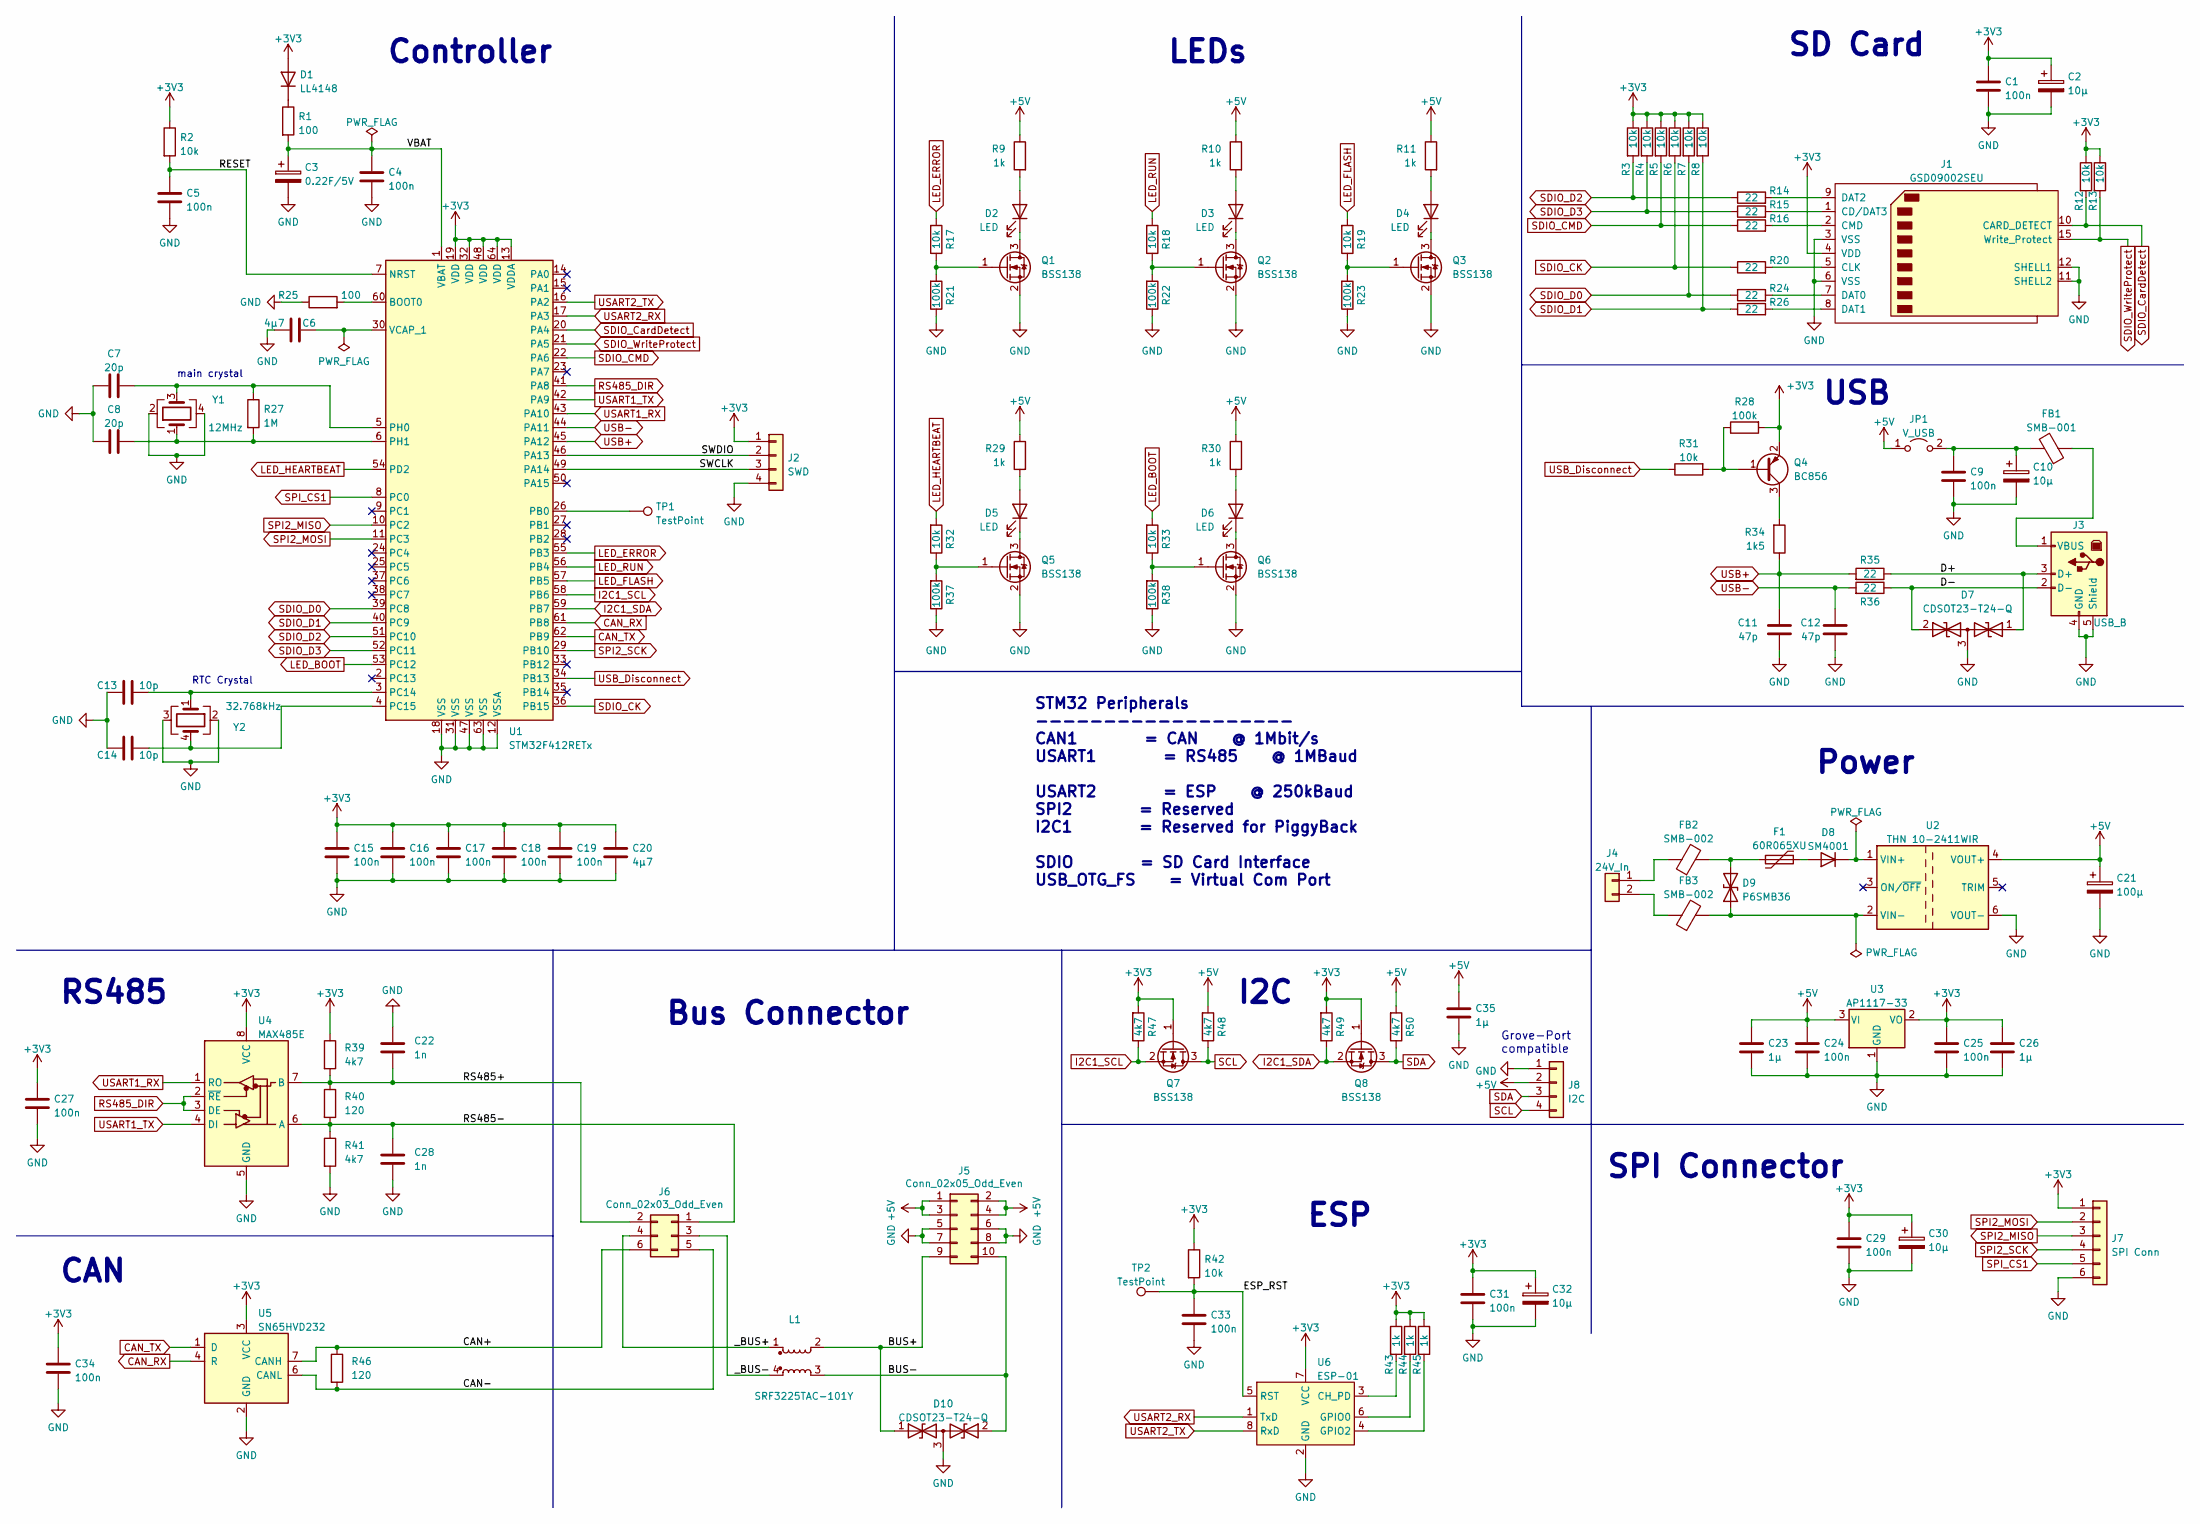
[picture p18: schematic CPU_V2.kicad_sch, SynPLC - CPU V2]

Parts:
C1, C4, C5, C9, C15, C16, C17, C18, C19, C24, C25, C27, C29, C31, C33, C34: 100n; C_0805_2012Metric
C2, C10, C30, C32: 10µ; CP_Elec_5x5.8
C3: 0.22F/5V; CP_Elec_10x10.5
C6, C20: 4µ7; C_0805_2012Metric
C7, C8: 20p; C_0805_2012Metric
C11, C12: 47p; C_0805_2012Metric
C13, C14: 10p; C_0805_2012Metric
C21: 100µ; CP_Elec_5x5.8
C22, C28: 1n; C_0805_2012Metric
C23, C26, C35: 1µ; C_0805_2012Metric
D1: LL4148; D_MiniMELF
D2, D3, D4, D5, D6: LED; LED_D3.0mm
D7, D10: CDSOT23-T24-Q; SOT-23
D8: SM4001; D_MELF
D9: P6SMB36; D_SMA
F1: 60R065XU; Fuse_Littelfuse_395Series
FB1: SMB-001
FB2, FB3: SMB-002
J1: GSD09002SEU
J2: SWD; JST_XH_B4B-XH-A_1x04_P2.50mm_Vertical
J3: USB_B; USB_B_Lumberg_2411_02_Horizontal
J4: 24V_In; TBL00950002GY2GY
J5: Conn_02x05_Odd_Even; PinHeader_2x05_P2.54mm_Horizontal
J6: Conn_02x03_Odd_Even; PinHeader_2x03_P2.54mm_Vertical
J7: SPI Conn; PinHeader_1x06_P2.54mm_Vertical
J8: I2C; PinHeader_1x04_P2.54mm_Vertical
JP1: V_USB; SolderJumper-2_P1.3mm_Open_RoundedPad1.0x1.5mm
L1: SRF3225TAC-101Y; SRF3225TAC
Q1, Q2, Q3, Q5, Q6, Q7, Q8: BSS138; SOT-23
Q4: BC856; SOT-23
R1, R25: 100; R_0805_2012Metric
R2, R3, R4, R5, R6, R7, R8, R12, R13, R17, R18, R19, R31, R32, R33, R42: 10k; R_0805_2012Metric
R9, R10, R11, R29, R30, R43, R44, R45: 1k; R_0805_2012Metric
R14, R15, R16, R20, R24, R26, R35, R36: 22; R_0805_2012Metric
R21, R22, R23, R28, R37, R38: 100k; R_0805_2012Metric
R27: 1M; R_0805_2012Metric
R34: 1k5; R_0805_2012Metric
R39, R41, R47, R48, R49, R50: 4k7; R_0805_2012Metric
R40, R46: 120; R_0805_2012Metric
TP1, TP2: TestPoint; TestPoint_Pad_1.5x1.5mm
U1: STM32F412RETx; LQFP-64_10x10mm_P0.5mm
U2: THN 10-2411WIR; THN 10WIR
U3: AP1117-33; SOT-223-3_TabPin2
U4: MAX485E; SOIC-8_3.9x4.9mm_P1.27mm
U5: SN65HVD232; SOIC-8_3.9x4.9mm_P1.27mm
U6: ESP-01
Y1: 12MHz; Crystal_SMD_5032-4Pin_5.0x3.2mm
Y2: 32.768kHz; Crystal_SMD_SeikoEpson_MC306-4Pin_8.0x3.2mm

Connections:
+3V3: C1.1, C2.1, C15.1, C16.1, C17.1, C18.1, C19.1, C20.1, C25.1, C26.1, C27.1, C29.1, C30.1, C31.1, C32.1, C34.1, D1.2 (A), J1.4 (VDD), J2.1, J7.1, Q4.2 (E), Q7.1 (G), Q8.1 (G), R2.1, R3.1, R4.1, R5.1, R6.1, R7.1, R8.1, R12.1, R13.1, R28.2, R39.1, R42.1, R43.1, R44.1, R45.1, R47.2, R49.2, U1.13 (VDDA), U1.19 (VDD), U1.32 (VDD), U1.48 (VDD), U1.64 (VDD), U3.2 (VO), U4.8 (VCC), U5.3 (VCC), U6.7 (VCC)
+5V: C21.1, C23.1, C24.1, C35.1, J5.1, J5.2, J5.3, J5.4, J8.2, JP1.1 (A), R9.1, R10.1, R11.1, R29.1, R30.1, R48.2, R50.2, U2.4 (VOUT+), U3.3 (VI)
/BUS+: D10.1 (A1), J5.9, L1.2
/BUS-: D10.2 (A2), J5.10, L1.3
/CAN+: J6.6, R46.1, U5.7 (CANH)
/CAN-: J6.5, R46.2, U5.6 (CANL)
/D+: D7.1 (A1), J3.3 (D+), R35.1
/D-: D7.2 (A2), J3.2 (D-), R36.1
/ESP_RST: C33.1, R42.2, TP2.1, U6.5 (RST)
/RESET: C5.1, R2.2, U1.7 (NRST)
/RS485+: C22.2, J6.2, R39.2, R40.1, U4.7 (B)
/RS485-: C28.1, J6.1, R40.2, R41.1, U4.6 (A)
/SWCLK: J2.3, U1.49 (PA14)
/SWDIO: J2.2, U1.46 (PA13)
/VBAT: C3.1, C4.1, R1.2, U1.1 (VBAT)
/_BUS+: J6.4, L1.1
/_BUS-: J6.3, L1.4
CAN_RX: U1.61 (PB8), U5.4 (R)
CAN_TX: U1.62 (PB9), U5.1 (D)
GND: C1.2, C2.2, C3.2, C4.2, C5.2, C6.2, C7.1, C8.1, C9.2, C10.2, C11.2, C12.2, C13.1, C14.1, C15.2, C16.2, C17.2, C18.2, C19.2, C20.2, C21.2, C22.1, C23.2, C24.2, C25.2, C26.2, C27.2, C28.2, C29.2, C30.2, C31.2, C32.2, C33.2, C34.2, C35.2, D7.3 (common), D10.3 (common), J1.3 (VSS), J1.6 (VSS), J1.11 (SHELL2), J1.12 (SHELL1), J2.4, J3.4 (GND), J3.5 (Shield), J5.5, J5.6, J5.7, J5.8, J7.6, J8.1, Q1.2 (S), Q2.2 (S), Q3.2 (S), Q5.2 (S), Q6.2 (S), R21.1, R22.1, R23.1, R25.1, R37.1, R38.1, R41.2, U1.12 (VSSA), U1.18 (VSS), U1.31 (VSS), U1.47 (VSS), U1.63 (VSS), U2.6 (VOUT-), U3.1 (GND), U4.5 (GND), U5.2 (GND), U6.2 (GND), Y1.2, Y1.4, Y2.2, Y2.3
I2C1_SCL: Q7.2 (S), R47.1, U1.58 (PB6)
I2C1_SDA: Q8.2 (S), R49.1, U1.59 (PB7)
LED_BOOT: R33.2, U1.53 (PC12)
LED_ERROR: R17.2, U1.55 (PB3)
LED_FLASH: R19.2, U1.57 (PB5)
LED_HEARTBEAT: R32.2, U1.54 (PD2)
LED_RUN: R18.2, U1.56 (PB4)
unnamed: C6.1, U1.30 (VCAP_1)
unnamed: C7.2, R27.1, U1.5 (PH0), Y1.3
unnamed: C8.2, R27.2, U1.6 (PH1), Y1.1
unnamed: C9.1, C10.1, FB1.2, JP1.2 (B)
unnamed: C13.2, U1.3 (PC14), Y2.1
unnamed: C14.2, U1.4 (PC15), Y2.4
unnamed: D1.1 (K), R1.1
unnamed: D2.1 (K), Q1.3 (D)
unnamed: D2.2 (A), R9.2
unnamed: D3.1 (K), Q2.3 (D)
unnamed: D3.2 (A), R10.2
unnamed: D4.1 (K), Q3.3 (D)
unnamed: D4.2 (A), R11.2
unnamed: D5.1 (K), Q5.3 (D)
unnamed: D5.2 (A), R29.2
unnamed: D6.1 (K), Q6.3 (D)
unnamed: D6.2 (A), R30.2
unnamed: D8.1 (K), U2.1 (VIN+)
unnamed: D8.2 (A), F1.1
unnamed: D9.1 (A1), FB3.2, U2.2 (VIN-)
unnamed: D9.2 (A2), F1.2, FB2.2
unnamed: FB1.1, J3.1 (VBUS)
unnamed: FB2.1, J4.1
unnamed: FB3.1, J4.2
unnamed: J1.1 (CD/DAT3), R15.2
unnamed: J1.2 (CMD), R16.2
unnamed: J1.5 (CLK), R20.2
unnamed: J1.7 (DAT0), R24.2
unnamed: J1.8 (DAT1), R26.2
unnamed: J1.9 (DAT2), R14.2
unnamed: Q1.1 (G), R17.1, R21.2
unnamed: Q2.1 (G), R18.1, R22.2
unnamed: Q3.1 (G), R19.1, R23.2
unnamed: Q4.1 (B), R28.1, R31.2
unnamed: Q4.3 (C), R34.2
unnamed: Q5.1 (G), R32.1, R37.2
unnamed: Q6.1 (G), R33.1, R38.2
unnamed: R25.2, U1.60 (BOOT0)
unnamed: R43.2, U6.3 (CH_PD)
unnamed: R44.2, U6.6 (GPIO0)
unnamed: R45.2, U6.4 (GPIO2)
unnamed: TP1.1, U1.26 (PB0)
RS485_DIR: U1.41 (PA8), U4.2 (~RE), U4.3 (DE)
SCL: J8.4, Q7.3 (D), R48.1
SDA: J8.3, Q8.3 (D), R50.1
SDIO_CK: R6.2, R20.1, U1.36 (PB15)
SDIO_CMD: R5.2, R16.1, U1.22 (PA6)
SDIO_CardDetect: J1.10 (CARD_DETECT), R12.2, U1.20 (PA4)
SDIO_D0: R7.2, R24.1, U1.39 (PC8)
SDIO_D1: R8.2, R26.1, U1.40 (PC9)
SDIO_D2: R3.2, R14.1, U1.51 (PC10)
SDIO_D3: R4.2, R15.1, U1.52 (PC11)
SDIO_WriteProtect: J1.15 (Write_Protect), R13.2, U1.21 (PA5)
SPI2_MISO: J7.3, U1.10 (PC2)
SPI2_MOSI: J7.2, U1.11 (PC3)
SPI2_SCK: J7.4, U1.29 (PB10)
SPI_CS1: J7.5, U1.8 (PC0)
USART1_RX: U1.43 (PA10), U4.1 (RO)
USART1_TX: U1.42 (PA9), U4.4 (DI)
USART2_RX: U1.17 (PA3), U6.1 (TxD)
USART2_TX: U1.16 (PA2), U6.8 (RxD)
USB+: C11.1, R34.1, R35.2, U1.45 (PA12)
USB-: C12.1, R36.2, U1.44 (PA11)
USB_Disconnect: R31.1, U1.34 (PB13)

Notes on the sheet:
I2C
CAN
USB
LEDs
SD Card
main crystal
Power
ESP
STM32 Peripherals ------------------- CAN1 = CAN @ 1Mbit/s USART1 = RS485 @ 1MBaud USART2 = ESP @ 250kBaud SPI2 = Reserved I2C1 = Reserved for PiggyBack SDIO = SD Card Interface USB_OTG_FS = Virtual Com Port
Controller
SPI Connector
Bus Connector
RTC Crystal
Grove-Port compatible
RS485

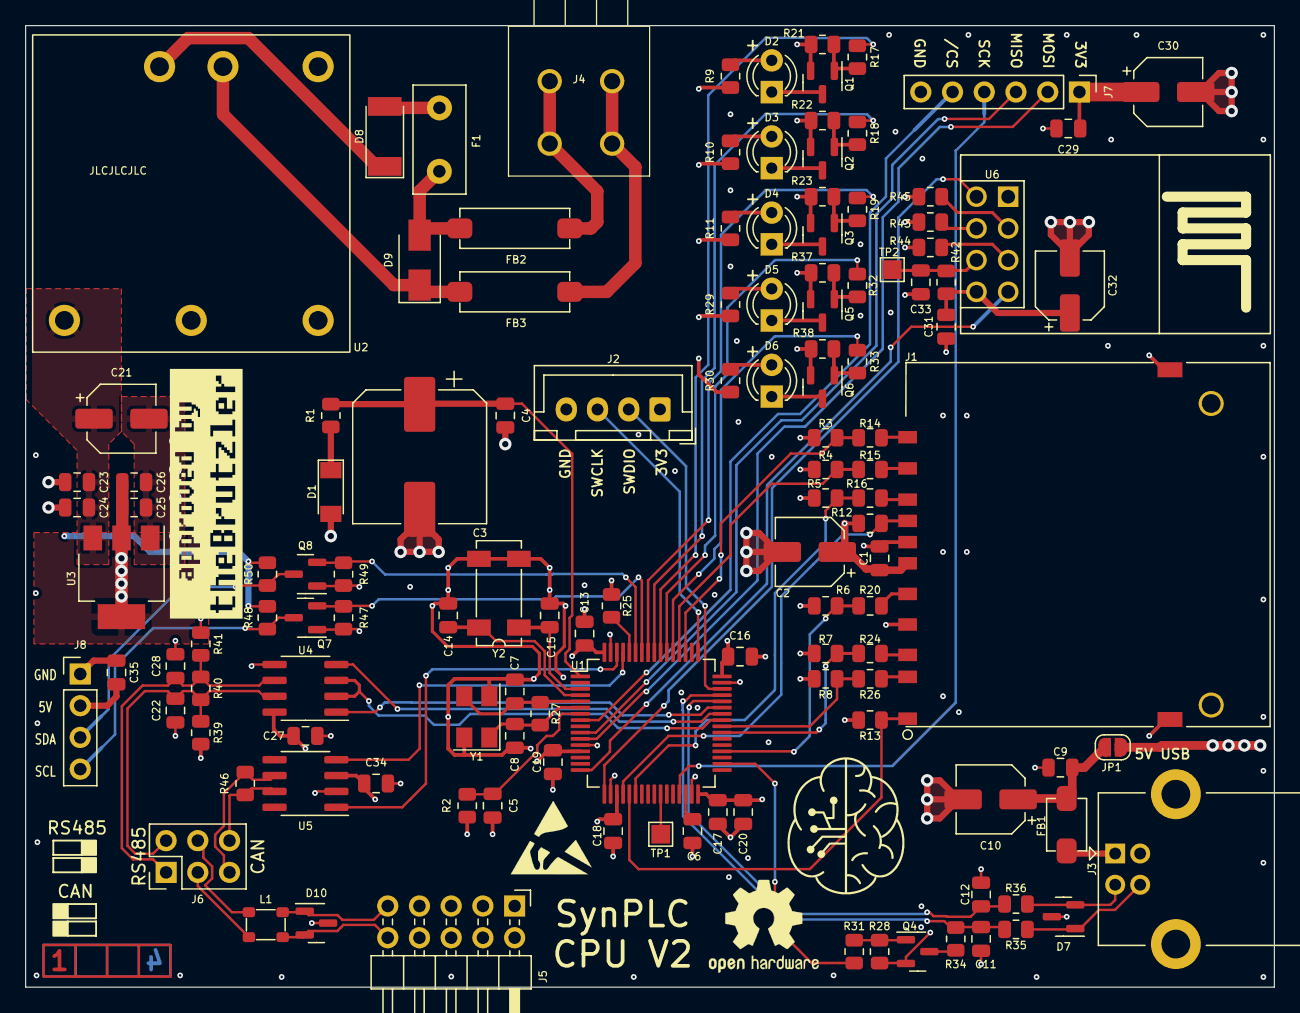
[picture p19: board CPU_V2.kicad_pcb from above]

Board: 4 copper layers, 100.0 x 77.0 mm, 127 parts (0 on the bottom side), 91 nets.

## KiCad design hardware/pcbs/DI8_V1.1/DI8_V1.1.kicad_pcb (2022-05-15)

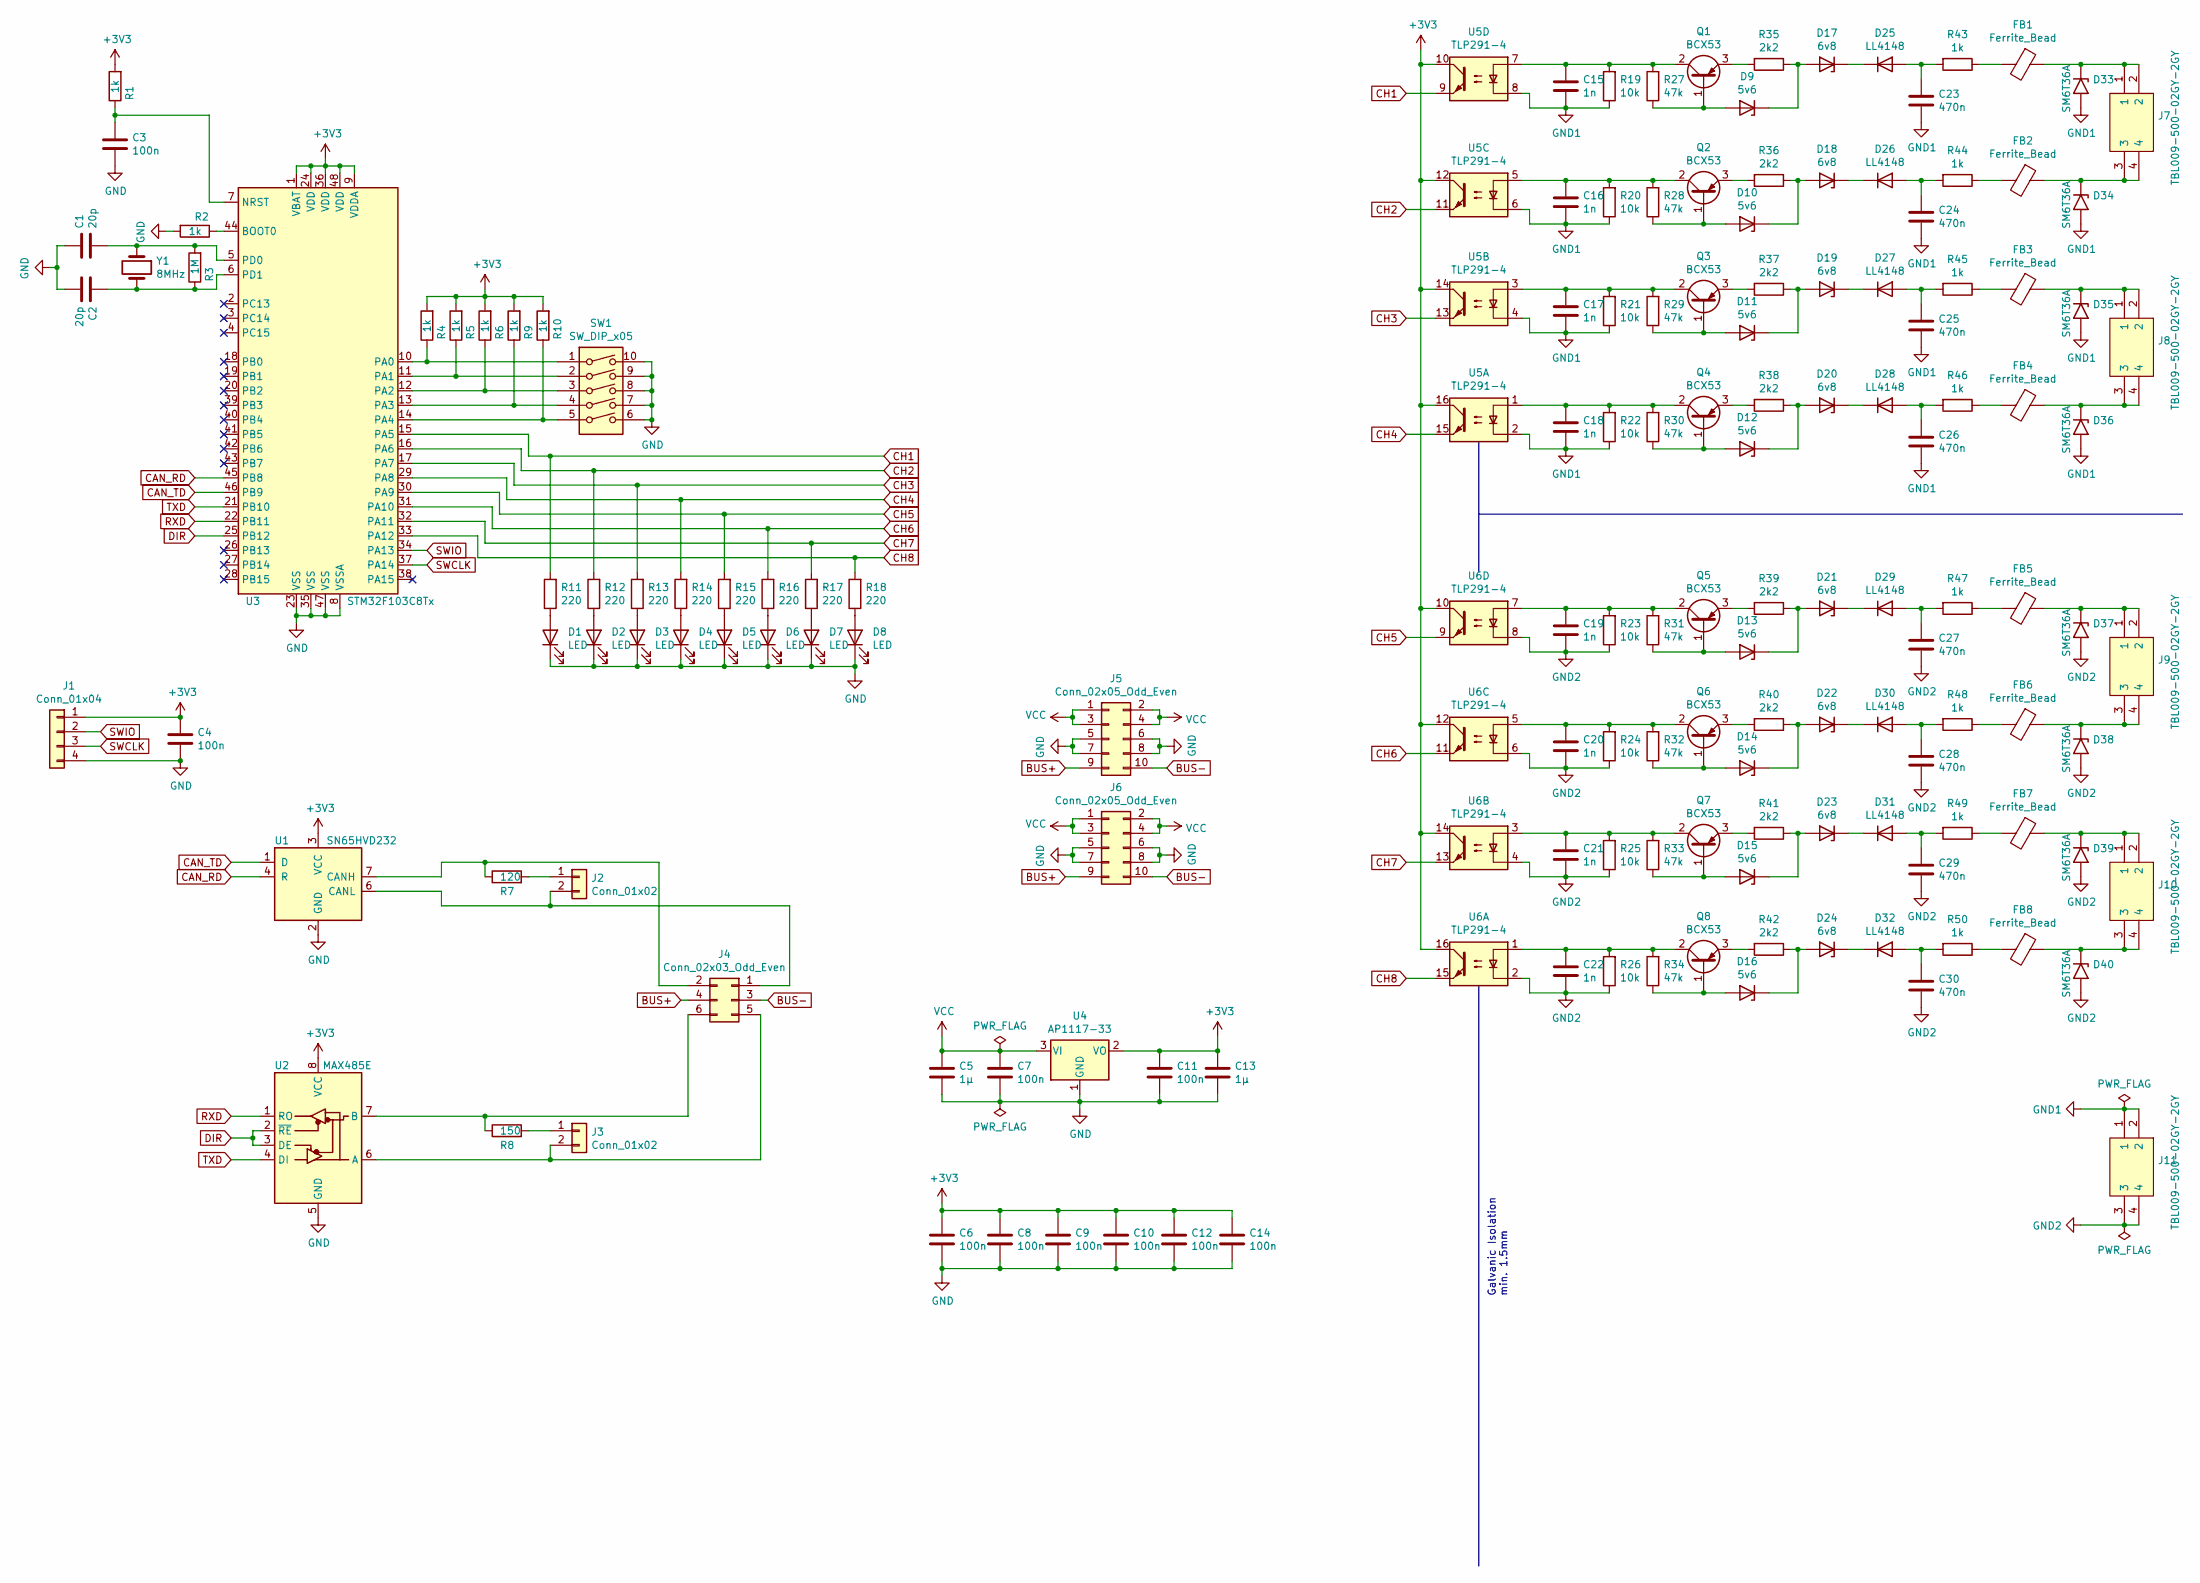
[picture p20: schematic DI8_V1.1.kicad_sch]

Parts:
C1, C2: 20p; C_0805_2012Metric_Pad1.18x1.45mm_HandSolder
C3, C4, C6, C7, C8, C9, C10, C11, C12, C14: 100n; C_0805_2012Metric_Pad1.18x1.45mm_HandSolder
C5, C13: 1µ; C_0805_2012Metric_Pad1.18x1.45mm_HandSolder
C15, C16, C17, C18, C19, C20, C21, C22: 1n; C_0805_2012Metric_Pad1.18x1.45mm_HandSolder
C23, C24, C25, C26, C27, C28, C29, C30: 470n; C_0805_2012Metric_Pad1.18x1.45mm_HandSolder
D1, D2, D3, D4, D5, D6, D7, D8: LED; LED_D3.0mm
D9, D10, D11, D12, D13, D14, D15, D16: 5v6; D_MiniMELF
D17, D18, D19, D20, D21, D22, D23, D24: 6v8; D_MiniMELF
D25, D26, D27, D28, D29, D30, D31, D32: LL4148; D_MiniMELF
D33, D34, D35, D36, D37, D38, D39, D40: SM6T36A; D_SMB
FB1, FB2, FB3, FB4, FB5, FB6, FB7, FB8: Ferrite_Bead; SMB-001
J1: Conn_01x04; PinHeader_1x04_P2.54mm_Vertical
J2, J3: Conn_01x02; PinHeader_1x02_P2.54mm_Vertical
J4: Conn_02x03_Odd_Even; PinHeader_2x03_P2.54mm_Vertical
J5, J6: Conn_02x05_Odd_Even; PinHeader_2x05_P2.54mm_Horizontal
J7, J8, J9, J10, J11: TBL009-500-02GY-2GY; TBL00950002GY2GY; Manufacturer_Part_Number TBL009-500-02GY-2GY; Mouser Part Number 490-TBL00950002GY2GY
Q1, Q2, Q3, Q4, Q5, Q6, Q7, Q8: BCX53; SOT-89-3
R1, R2, R4, R5, R6, R9, R10, R43, R44, R45, R46, R47, R48, R49, R50: 1k; R_0805_2012Metric_Pad1.20x1.40mm_HandSolder
R3: 1M; R_0805_2012Metric_Pad1.20x1.40mm_HandSolder
R7: 120; R_0805_2012Metric_Pad1.20x1.40mm_HandSolder
R8: 150; R_0805_2012Metric_Pad1.20x1.40mm_HandSolder
R11, R12, R13, R14, R15, R16, R17, R18: 220; R_0805_2012Metric_Pad1.20x1.40mm_HandSolder
R19, R20, R21, R22, R23, R24, R25, R26: 10k; R_0805_2012Metric_Pad1.20x1.40mm_HandSolder
R27, R28, R29, R30, R31, R32, R33, R34: 47k; R_0805_2012Metric_Pad1.20x1.40mm_HandSolder
R35, R36, R37, R38, R39, R40, R41, R42: 2k2; R_0805_2012Metric_Pad1.20x1.40mm_HandSolder
SW1: SW_DIP_x05; SW_DIP_SPSTx05_Slide_6.7x14.26mm_W7.62mm_P2.54mm_LowProfile
U1: SN65HVD232; SOIC-8_3.9x4.9mm_P1.27mm
U2: MAX485E; SOIC-8_3.9x4.9mm_P1.27mm
U3: STM32F103C8Tx; LQFP-48_7x7mm_P0.5mm
U4: AP1117-33; SOT-223-3_TabPin2
U5, U6: TLP291-4; SOIC-16_4.55x10.3mm_P1.27mm
Y1: 8MHz; Crystal_SMD_HC49-SD

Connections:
+3V3: C4.2, C6.2, C8.2, C9.2, C10.2, C11.2, C12.2, C13.2, C14.2, J1.1, R1.2, R4.2, R5.2, R6.2, R9.2, R10.2, U1.3 (VCC), U2.8 (VCC), U3.1 (VBAT), U3.9 (VDDA), U3.24 (VDD), U3.36 (VDD), U3.48 (VDD), U4.2 (VO), U5.10, U5.12, U5.14, U5.16, U6.10, U6.12, U6.14, U6.16
BUS+: J4.4, J5.9, J6.9
BUS-: J4.3, J5.10, J6.10
CAN_RD: U1.4 (R), U3.45 (PB8)
CAN_TD: U1.1 (D), U3.46 (PB9)
CH1: R11.2, U3.15 (PA5), U5.9
CH2: R12.2, U3.16 (PA6), U5.11
CH3: R13.2, U3.17 (PA7), U5.13
CH4: R14.2, U3.29 (PA8), U5.15
CH5: R15.2, U3.30 (PA9), U6.9
CH6: R16.2, U3.31 (PA10), U6.11
CH7: R17.2, U3.32 (PA11), U6.13
CH8: R18.2, U3.33 (PA12), U6.15
DIR: U2.2 (~RE), U2.3 (DE), U3.25 (PB12)
GND: C1.2, C2.1, C3.1, C4.1, C5.1, C6.1, C7.1, C8.1, C9.1, C10.1, C11.1, C12.1, C13.1, C14.1, D1.1 (K), D2.1 (K), D3.1 (K), D4.1 (K), D5.1 (K), D6.1 (K), D7.1 (K), D8.1 (K), J1.4, J5.5, J5.6, J5.7, J5.8, J6.5, J6.6, J6.7, J6.8, R2.2, SW1.6, SW1.7, SW1.8, SW1.9, SW1.10, U1.2 (GND), U2.5 (GND), U3.8 (VSSA), U3.23 (VSS), U3.35 (VSS), U3.47 (VSS), U4.1 (GND)
GND1: C15.1, C16.1, C17.1, C18.1, C23.1, C24.1, C25.1, C26.1, D33.2 (A2), D34.2 (A2), D35.2 (A2), D36.2 (A2), J11.1, J11.2, R19.1, R20.1, R21.1, R22.1, U5.2, U5.4, U5.6, U5.8
GND2: C19.1, C20.1, C21.1, C22.1, C27.1, C28.1, C29.1, C30.1, D37.2 (A2), D38.2 (A2), D39.2 (A2), D40.2 (A2), J11.3, J11.4, R23.1, R24.1, R25.1, R26.1, U6.2, U6.4, U6.6, U6.8
unnamed: C1.1, R3.2, U3.5 (PD0), Y1.1
unnamed: C2.2, R3.1, U3.6 (PD1), Y1.2
unnamed: C3.2, R1.1, U3.7 (NRST)
unnamed: C15.2, Q1.2 (C), R19.2, R27.2, U5.7
unnamed: C16.2, Q2.2 (C), R20.2, R28.2, U5.5
unnamed: C17.2, Q3.2 (C), R21.2, R29.2, U5.3
unnamed: C18.2, Q4.2 (C), R22.2, R30.2, U5.1
unnamed: C19.2, Q5.2 (C), R23.2, R31.2, U6.7
unnamed: C20.2, Q6.2 (C), R24.2, R32.2, U6.5
unnamed: C21.2, Q7.2 (C), R25.2, R33.2, U6.3
unnamed: C22.2, Q8.2 (C), R26.2, R34.2, U6.1
unnamed: C23.2, D25.2 (A), R43.2
unnamed: C24.2, D26.2 (A), R44.2
unnamed: C25.2, D27.2 (A), R45.2
unnamed: C26.2, D28.2 (A), R46.2
unnamed: C27.2, D29.2 (A), R47.2
unnamed: C28.2, D30.2 (A), R48.2
unnamed: C29.2, D31.2 (A), R49.2
unnamed: C30.2, D32.2 (A), R50.2
unnamed: D1.2 (A), R11.1
unnamed: D2.2 (A), R12.1
unnamed: D3.2 (A), R13.1
unnamed: D4.2 (A), R14.1
unnamed: D5.2 (A), R15.1
unnamed: D6.2 (A), R16.1
unnamed: D7.2 (A), R17.1
unnamed: D8.2 (A), R18.1
unnamed: D9.2 (A), Q1.1 (B), R27.1
unnamed: D10.1 (K), D18.2 (A), R36.1
unnamed: D10.2 (A), Q2.1 (B), R28.1
unnamed: D11.1 (K), D19.2 (A), R37.1
unnamed: D11.2 (A), Q3.1 (B), R29.1
unnamed: D12.1 (K), D20.2 (A), R38.1
unnamed: D12.2 (A), Q4.1 (B), R30.1
unnamed: D13.1 (K), D21.2 (A), R39.1
unnamed: D13.2 (A), Q5.1 (B), R31.1
unnamed: D14.1 (K), D22.2 (A), R40.1
unnamed: D14.2 (A), Q6.1 (B), R32.1
unnamed: D15.1 (K), D23.2 (A), R41.1
unnamed: D15.2 (A), Q7.1 (B), R33.1
unnamed: D16.1 (K), D24.2 (A), R42.1
unnamed: D16.2 (A), Q8.1 (B), R34.1
unnamed: D17.1 (K), D25.1 (K)
unnamed: D9.1 (K), D17.2 (A), R35.1
unnamed: D18.1 (K), D26.1 (K)
unnamed: D19.1 (K), D27.1 (K)
unnamed: D20.1 (K), D28.1 (K)
unnamed: D21.1 (K), D29.1 (K)
unnamed: D22.1 (K), D30.1 (K)
unnamed: D23.1 (K), D31.1 (K)
unnamed: D24.1 (K), D32.1 (K)
unnamed: D33.1 (A1), FB1.1, J7.1, J7.2
unnamed: D34.1 (A1), FB2.1, J7.3, J7.4
unnamed: D35.1 (A1), FB3.1, J8.1, J8.2
unnamed: D36.1 (A1), FB4.1, J8.3, J8.4
unnamed: D37.1 (A1), FB5.1, J9.1, J9.2
unnamed: D38.1 (A1), FB6.1, J9.3, J9.4
unnamed: D39.1 (A1), FB7.1, J10.1, J10.2
unnamed: D40.1 (A1), FB8.1, J10.3, J10.4
unnamed: FB1.2, R43.1
unnamed: FB2.2, R44.1
unnamed: FB3.2, R45.1
unnamed: FB4.2, R46.1
unnamed: FB5.2, R47.1
unnamed: FB6.2, R48.1
unnamed: FB7.2, R49.1
unnamed: FB8.2, R50.1
unnamed: J2.1, R7.2
unnamed: J2.2, J4.1, U1.6 (CANL)
unnamed: J3.1, R8.2
unnamed: J3.2, J4.5, U2.6 (A)
unnamed: J4.2, R7.1, U1.7 (CANH)
unnamed: J4.6, R8.1, U2.7 (B)
unnamed: Q1.3 (E), R35.2
unnamed: Q2.3 (E), R36.2
unnamed: Q3.3 (E), R37.2
unnamed: Q4.3 (E), R38.2
unnamed: Q5.3 (E), R39.2
unnamed: Q6.3 (E), R40.2
unnamed: Q7.3 (E), R41.2
unnamed: Q8.3 (E), R42.2
unnamed: R2.1, U3.44 (BOOT0)
unnamed: R4.1, SW1.1, U3.10 (PA0)
unnamed: R5.1, SW1.2, U3.11 (PA1)
unnamed: R6.1, SW1.3, U3.12 (PA2)
unnamed: R9.1, SW1.4, U3.13 (PA3)
unnamed: R10.1, SW1.5, U3.14 (PA4)
RXD: U2.1 (RO), U3.22 (PB11)
SWCLK: J1.3, U3.37 (PA14)
SWIO: J1.2, U3.34 (PA13)
TXD: U2.4 (DI), U3.21 (PB10)
VCC: C5.2, C7.2, J5.1, J5.2, J5.3, J5.4, J6.1, J6.2, J6.3, J6.4, U4.3 (VI)

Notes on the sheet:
Galvanic Isolation min. 1.5mm

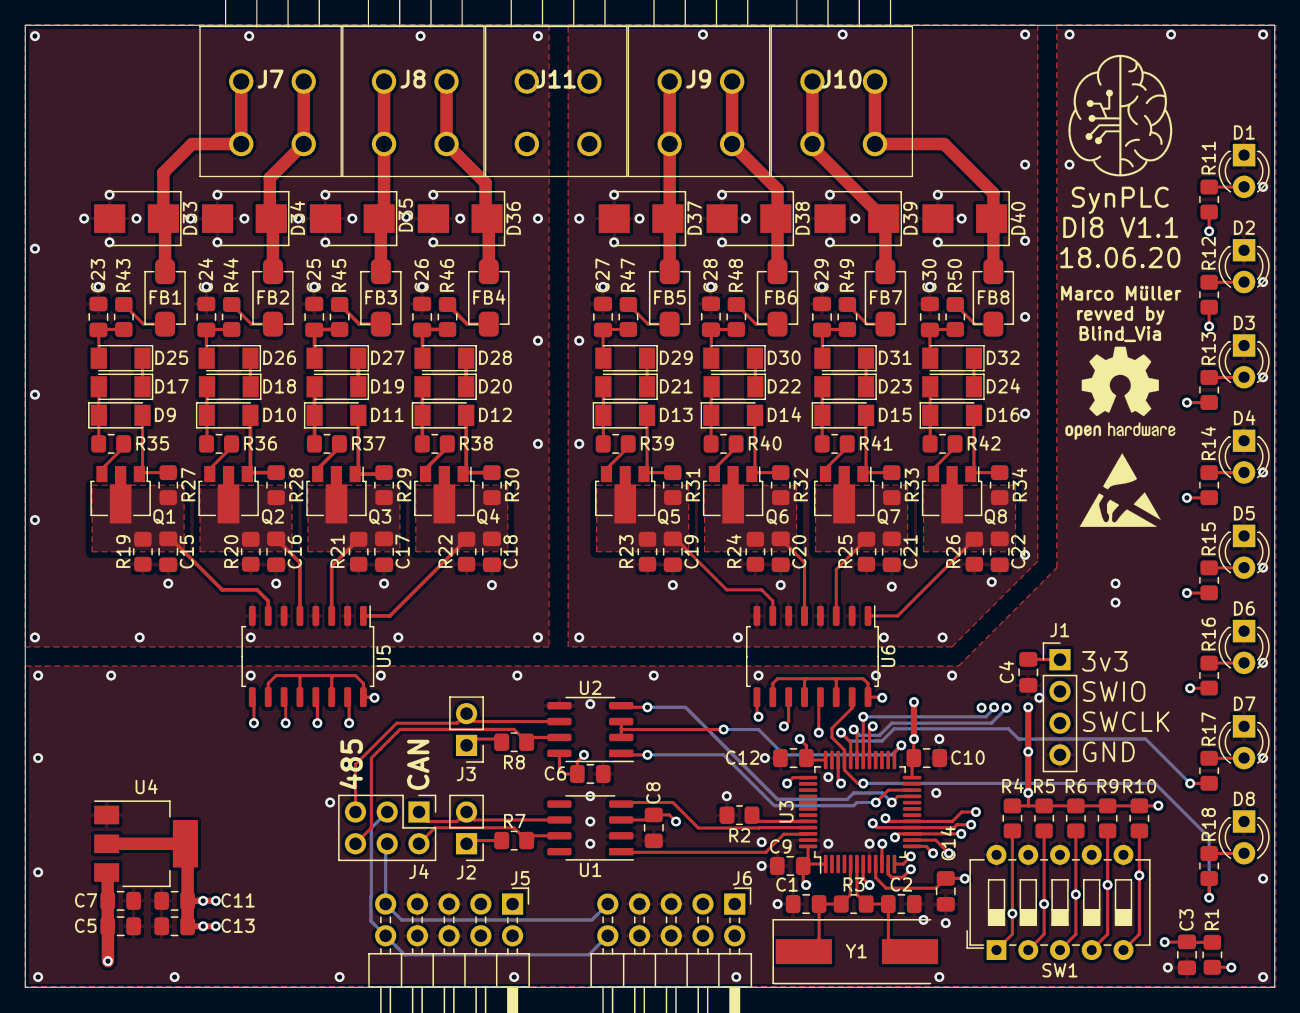
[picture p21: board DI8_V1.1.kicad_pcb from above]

Board: 4 copper layers, 100.0 x 77.0 mm, 155 parts (0 on the bottom side), 109 nets.

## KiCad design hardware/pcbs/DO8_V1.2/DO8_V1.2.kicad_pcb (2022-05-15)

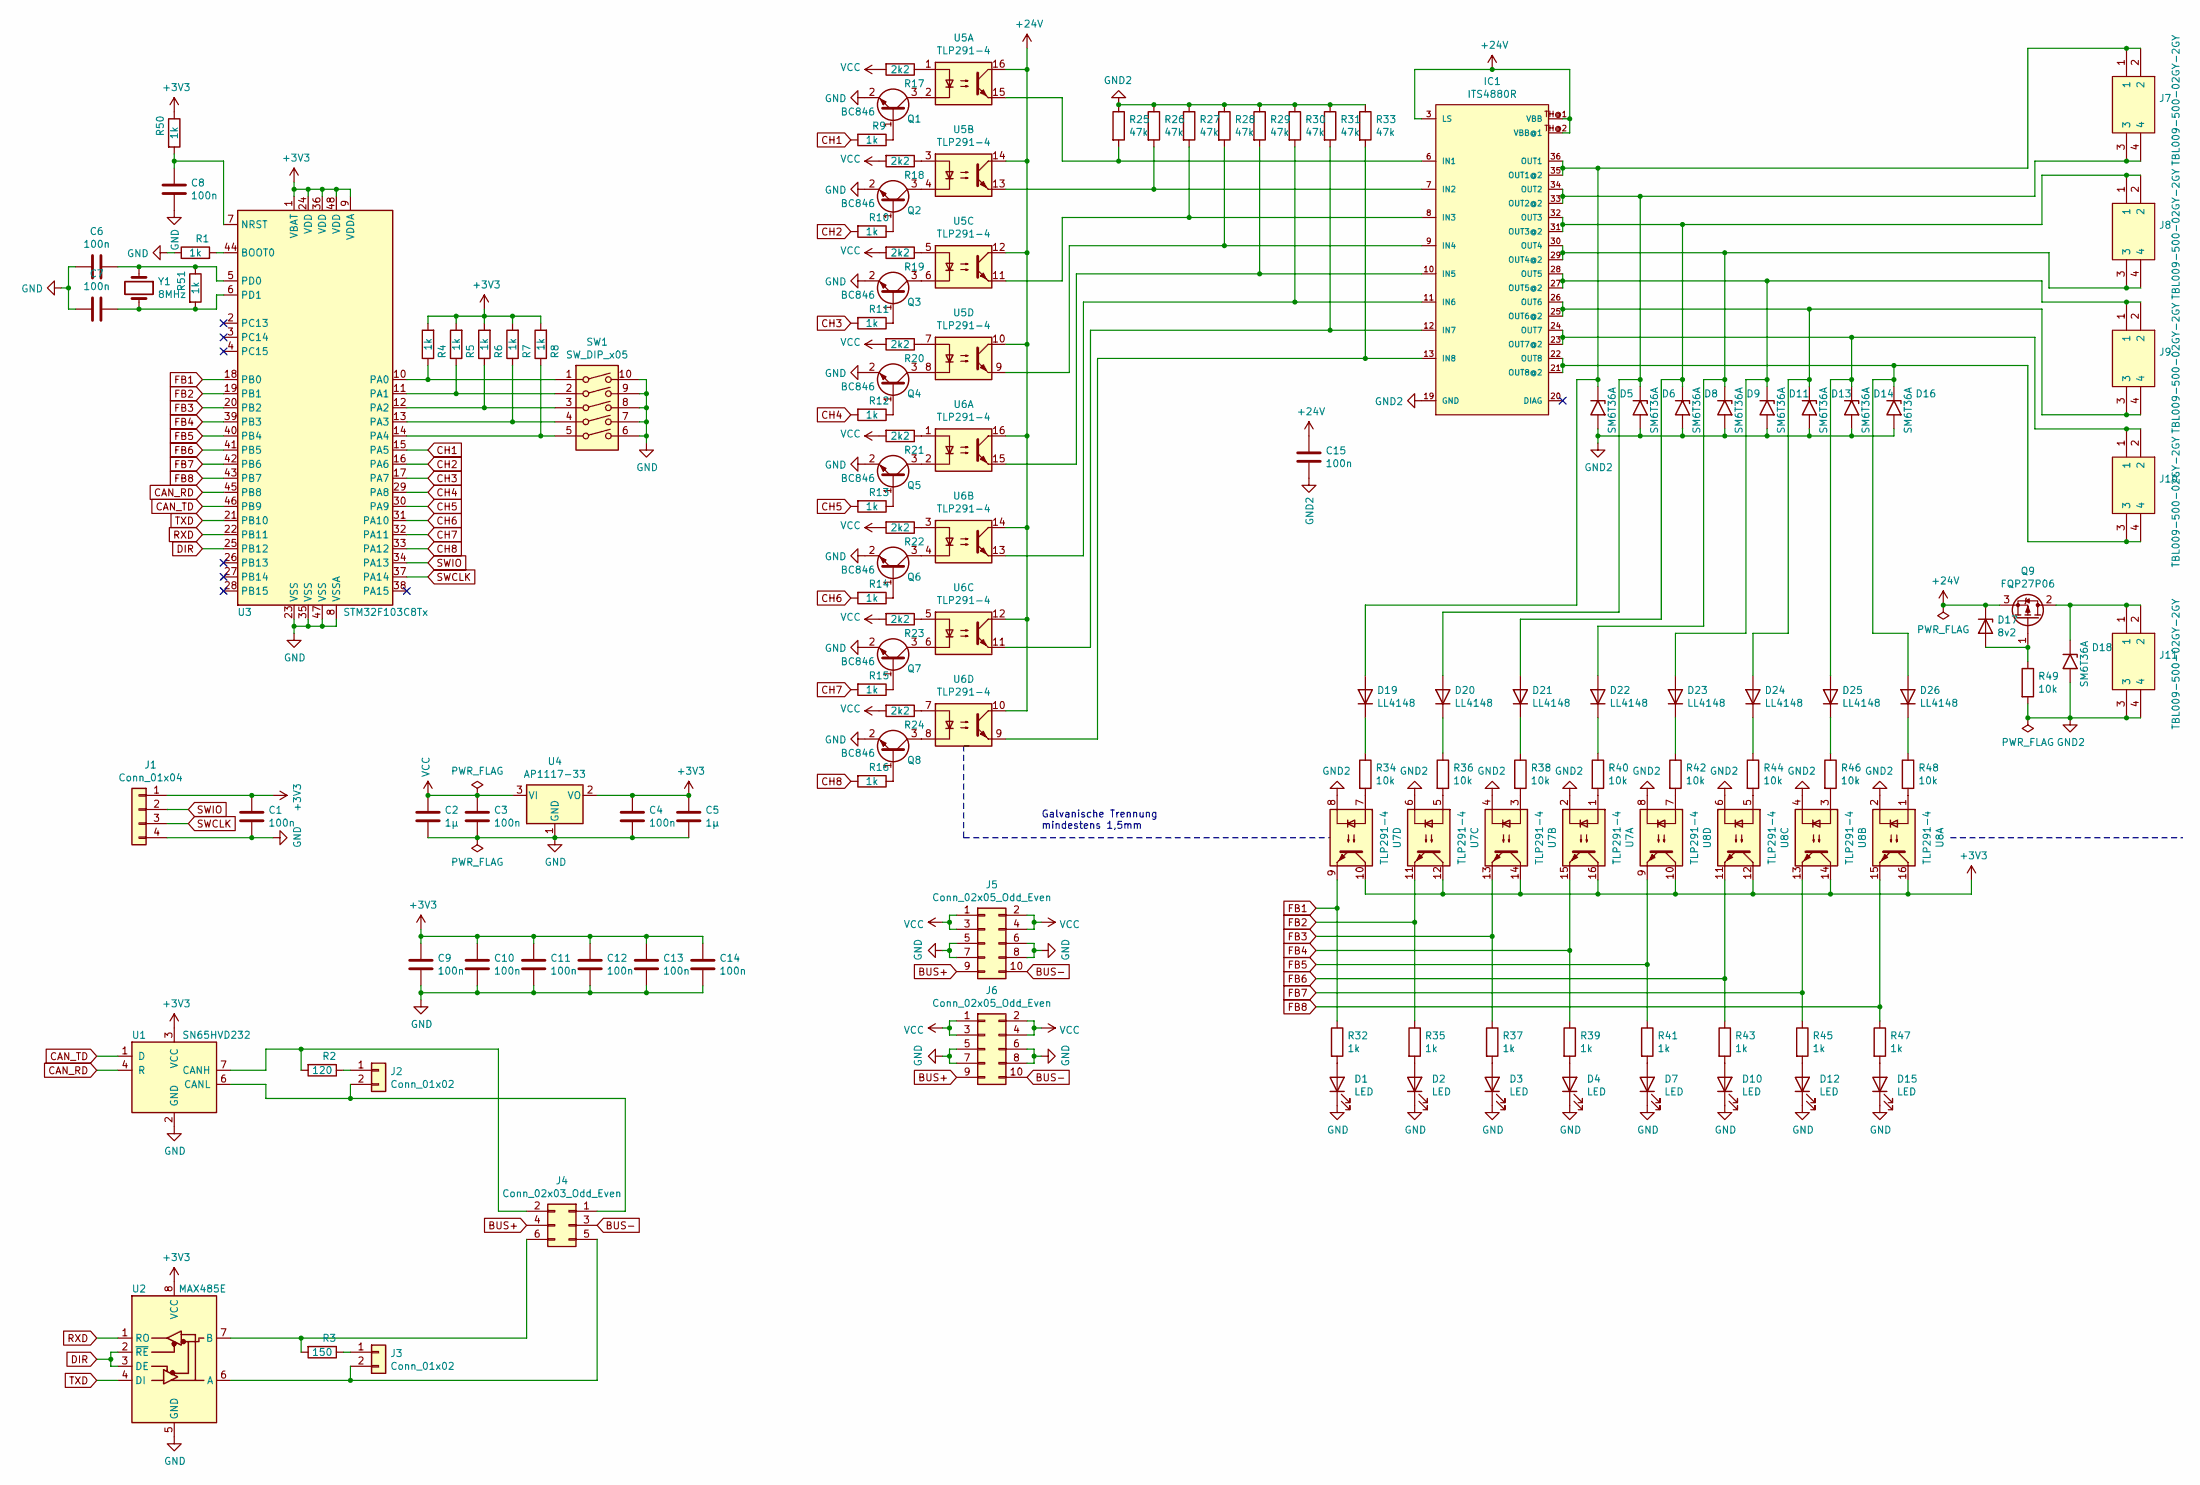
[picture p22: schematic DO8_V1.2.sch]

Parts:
C1, C3, C4, C6, C7, C8, C9, C10, C11, C12, C13, C14, C15: 100n; C_0805_2012Metric_Pad1.18x1.45mm_HandSolder
C2, C5: 1µ; C_0805_2012Metric_Pad1.18x1.45mm_HandSolder
D1, D2, D3, D4, D7, D10, D12, D15: LED; LED_D3.0mm
D5, D6, D8, D9, D11, D13, D14, D16, D18: SM6T36A; D_SMB
D17: 8v2; D_MiniMELF
D19, D20, D21, D22, D23, D24, D25, D26: LL4148; D_MiniMELF
IC1: ITS4880R; PG-DSO-36; MPN ITS4880R
J1: Conn_01x04; PinHeader_1x04_P2.54mm_Vertical
J2, J3: Conn_01x02; PinHeader_1x02_P2.54mm_Vertical
J4: Conn_02x03_Odd_Even; PinHeader_2x03_P2.54mm_Vertical
J5, J6: Conn_02x05_Odd_Even; PinHeader_2x05_P2.54mm_Horizontal
J7, J8, J9, J10, J11: TBL009-500-02GY-2GY; TBL00950002GY2GY; Manufacturer_Part_Number TBL009-500-02GY-2GY; Mouser Part Number 490-TBL00950002GY2GY
Q1, Q2, Q3, Q4, Q5, Q6, Q7, Q8: BC846; SOT-23
Q9: FQP27P06; TO-220-3_Vertical
R1, R4, R5, R6, R7, R8, R9, R10, R11, R12, R13, R14, R15, R16, R32, R35, R37, R39, R41, R43, R45, R47, R50, R51: 1k; R_0805_2012Metric_Pad1.20x1.40mm_HandSolder
R2: 120; R_0805_2012Metric_Pad1.20x1.40mm_HandSolder
R3: 150; R_0805_2012Metric_Pad1.20x1.40mm_HandSolder
R17, R18, R19, R20, R21, R22, R23, R24: 2k2; R_0805_2012Metric_Pad1.20x1.40mm_HandSolder
R25, R26, R27, R28, R29, R30, R31, R33: 47k; R_0805_2012Metric_Pad1.20x1.40mm_HandSolder
R34, R36, R38, R40, R42, R44, R46, R48, R49: 10k; R_0805_2012Metric_Pad1.20x1.40mm_HandSolder
SW1: SW_DIP_x05; SW_DIP_SPSTx05_Slide_9.78x14.88mm_W7.62mm_P2.54mm
U1: SN65HVD232; SOIC-8_3.9x4.9mm_P1.27mm
U2: MAX485E; SO-8_3.9x4.9mm_P1.27mm
U3: STM32F103C8Tx; LQFP-48_7x7mm_P0.5mm
U4: AP1117-33; SOT-223-3_TabPin2
U5, U6, U7, U8: TLP291-4; SOIC-16_4.55x10.3mm_P1.27mm
Y1: 8MHz; Crystal_SMD_HC49-SD

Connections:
+3V3: C1.1, C4.1, C5.1, C9.1, C10.1, C11.1, C12.1, C13.1, C14.1, J1.1, R4.2, R5.2, R6.2, R7.2, R8.2, R50.1, U1.3 (VCC), U2.8 (VCC), U3.1 (VBAT), U3.9 (VDDA), U3.24 (VDD), U3.36 (VDD), U3.48 (VDD), U4.2 (VO), U7.10, U7.12, U7.14, U7.16, U8.10, U8.12, U8.14, U8.16
+24V: C15.1, D17.1 (K), IC1.3 (LS), IC1.TH@1 (VBB), IC1.TH@2 (VBB@1), Q9.3 (S), U5.10, U5.12, U5.14, U5.16, U6.10, U6.12, U6.14, U6.16
BUS+: J4.4, J5.9, J6.9
BUS-: J4.3, J5.10, J6.10
CAN_RD: U1.4 (R), U3.45 (PB8)
CAN_TD: U1.1 (D), U3.46 (PB9)
CH1: R9.2, U3.15 (PA5)
CH2: R10.2, U3.16 (PA6)
CH3: R11.2, U3.17 (PA7)
CH4: R12.2, U3.29 (PA8)
CH5: R13.2, U3.30 (PA9)
CH6: R14.2, U3.31 (PA10)
CH7: R15.2, U3.32 (PA11)
CH8: R16.2, U3.33 (PA12)
DIR: U2.2 (~RE), U2.3 (DE), U3.25 (PB12)
FB1: R32.1, U3.18 (PB0), U7.9
FB2: R35.1, U3.19 (PB1), U7.11
FB3: R37.1, U3.20 (PB2), U7.13
FB4: R39.1, U3.39 (PB3), U7.15
FB5: R41.1, U3.40 (PB4), U8.9
FB6: R43.1, U3.41 (PB5), U8.11
FB7: R45.1, U3.42 (PB6), U8.13
FB8: R47.1, U3.43 (PB7), U8.15
GND: C1.2, C2.2, C3.2, C4.2, C5.2, C6.2, C7.1, C8.2, C9.2, C10.2, C11.2, C12.2, C13.2, C14.2, D1.1 (K), D2.1 (K), D3.1 (K), D4.1 (K), D7.1 (K), D10.1 (K), D12.1 (K), D15.1 (K), J1.4, J5.5, J5.6, J5.7, J5.8, J6.5, J6.6, J6.7, J6.8, Q1.2 (E), Q2.2 (E), Q3.2 (E), Q4.2 (E), Q5.2 (E), Q6.2 (E), Q7.2 (E), Q8.2 (E), R1.1, SW1.6, SW1.7, SW1.8, SW1.9, SW1.10, U1.2 (GND), U2.5 (GND), U3.8 (VSSA), U3.23 (VSS), U3.35 (VSS), U3.47 (VSS), U4.1 (GND)
GND2: C15.2, D5.2 (A2), D6.2 (A2), D8.2 (A2), D9.2 (A2), D11.2 (A2), D13.2 (A2), D14.2 (A2), D16.2 (A2), D18.2 (A2), IC1.19 (GND), J11.3, J11.4, R25.1, R26.1, R27.1, R28.1, R29.1, R30.1, R31.1, R33.1, R49.2, U7.2, U7.4, U7.6, U7.8, U8.2, U8.4, U8.6, U8.8
unnamed: C6.1, R51.1, U3.5 (PD0), Y1.1
unnamed: C7.2, R51.2, U3.6 (PD1), Y1.2
unnamed: C8.1, R50.2, U3.7 (NRST)
unnamed: D1.2 (A), R32.2
unnamed: D2.2 (A), R35.2
unnamed: D3.2 (A), R37.2
unnamed: D4.2 (A), R39.2
unnamed: D7.2 (A), R41.2
unnamed: D10.2 (A), R43.2
unnamed: D11.1 (A1), D23.2 (A), IC1.27 (OUT5@2), IC1.28 (OUT5), J9.1, J9.2
unnamed: D12.2 (A), R45.2
unnamed: D13.1 (A1), D24.2 (A), IC1.25 (OUT6@2), IC1.26 (OUT6), J9.3, J9.4
unnamed: D14.1 (A1), D25.2 (A), IC1.23 (OUT7@2), IC1.24 (OUT7), J10.1, J10.2
unnamed: D15.2 (A), R47.2
unnamed: D16.1 (A1), D26.2 (A), IC1.21 (OUT8@2), IC1.22 (OUT8), J10.3, J10.4
unnamed: D17.2 (A), Q9.1 (G), R49.1
unnamed: D18.1 (A1), J11.1, J11.2, Q9.2 (D)
unnamed: D19.1 (K), R34.1
unnamed: D5.1 (A1), D19.2 (A), IC1.35 (OUT1@2), IC1.36 (OUT1), J7.1, J7.2
unnamed: D20.1 (K), R36.1
unnamed: D6.1 (A1), D20.2 (A), IC1.33 (OUT2@2), IC1.34 (OUT2), J7.3, J7.4
unnamed: D21.1 (K), R38.1
unnamed: D8.1 (A1), D21.2 (A), IC1.31 (OUT3@2), IC1.32 (OUT3), J8.1, J8.2
unnamed: D22.1 (K), R40.1
unnamed: D9.1 (A1), D22.2 (A), IC1.29 (OUT4@2), IC1.30 (OUT4), J8.3, J8.4
unnamed: D23.1 (K), R42.1
unnamed: D24.1 (K), R44.1
unnamed: D25.1 (K), R46.1
unnamed: D26.1 (K), R48.1
unnamed: IC1.6 (IN1), R25.2, U5.15
unnamed: IC1.7 (IN2), R26.2, U5.13
unnamed: IC1.8 (IN3), R27.2, U5.11
unnamed: IC1.9 (IN4), R28.2, U5.9
unnamed: IC1.10 (IN5), R29.2, U6.15
unnamed: IC1.11 (IN6), R30.2, U6.13
unnamed: IC1.12 (IN7), R31.2, U6.11
unnamed: IC1.13 (IN8), R33.2, U6.9
unnamed: J2.1, R2.1
unnamed: J2.2, J4.1, U1.6 (CANL)
unnamed: J3.1, R3.1
unnamed: J3.2, J4.5, U2.6 (A)
unnamed: J4.2, R2.2, U1.7 (CANH)
unnamed: J4.6, R3.2, U2.7 (B)
unnamed: Q1.1 (B), R9.1
unnamed: Q1.3 (C), U5.2
unnamed: Q2.1 (B), R10.1
unnamed: Q2.3 (C), U5.4
unnamed: Q3.1 (B), R11.1
unnamed: Q3.3 (C), U5.6
unnamed: Q4.1 (B), R12.1
unnamed: Q4.3 (C), U5.8
unnamed: Q5.1 (B), R13.1
unnamed: Q5.3 (C), U6.2
unnamed: Q6.1 (B), R14.1
unnamed: Q6.3 (C), U6.4
unnamed: Q7.1 (B), R15.1
unnamed: Q7.3 (C), U6.6
unnamed: Q8.1 (B), R16.1
unnamed: Q8.3 (C), U6.8
unnamed: R1.2, U3.44 (BOOT0)
unnamed: R4.1, SW1.1, U3.10 (PA0)
unnamed: R5.1, SW1.2, U3.11 (PA1)
unnamed: R6.1, SW1.3, U3.12 (PA2)
unnamed: R7.1, SW1.4, U3.13 (PA3)
unnamed: R8.1, SW1.5, U3.14 (PA4)
unnamed: R17.1, U5.1
unnamed: R18.1, U5.3
unnamed: R19.1, U5.5
unnamed: R20.1, U5.7
unnamed: R21.1, U6.1
unnamed: R22.1, U6.3
unnamed: R23.1, U6.5
unnamed: R24.1, U6.7
unnamed: R34.2, U7.7
unnamed: R36.2, U7.5
unnamed: R38.2, U7.3
unnamed: R40.2, U7.1
unnamed: R42.2, U8.7
unnamed: R44.2, U8.5
unnamed: R46.2, U8.3
unnamed: R48.2, U8.1
RXD: U2.1 (RO), U3.22 (PB11)
SWCLK: J1.3, U3.37 (PA14)
SWIO: J1.2, U3.34 (PA13)
TXD: U2.4 (DI), U3.21 (PB10)
VCC: C2.1, C3.1, J5.1, J5.2, J5.3, J5.4, J6.1, J6.2, J6.3, J6.4, R17.2, R18.2, R19.2, R20.2, R21.2, R22.2, R23.2, R24.2, U4.3 (VI)

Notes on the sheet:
Galvanische Trennung mindestens 1,5mm

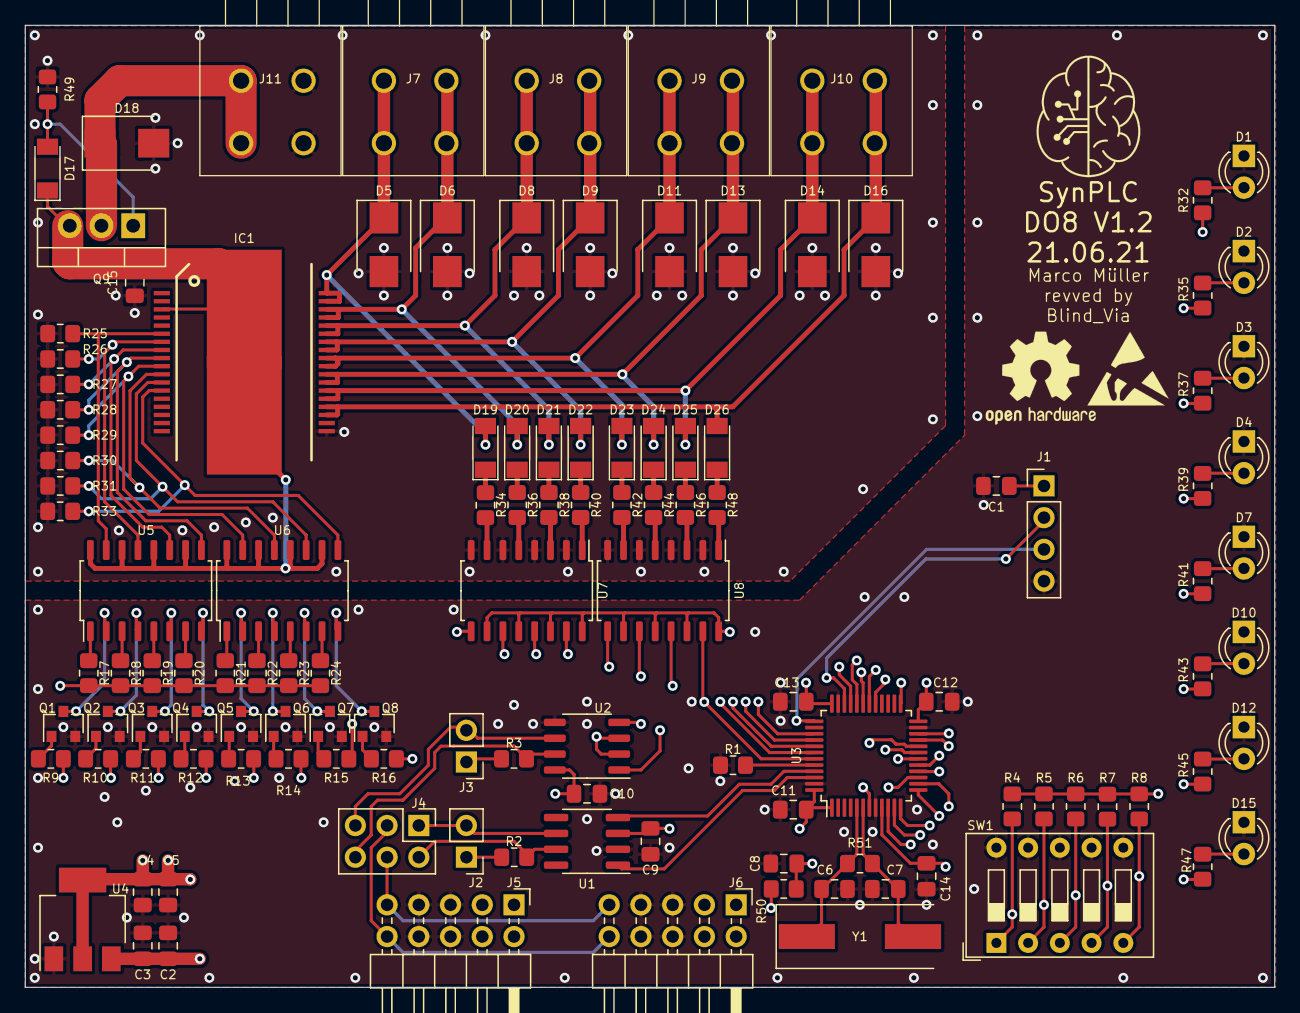
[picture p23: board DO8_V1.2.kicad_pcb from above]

Board: 4 copper layers, 100.0 x 77.0 mm, 123 parts (0 on the bottom side), 111 nets.

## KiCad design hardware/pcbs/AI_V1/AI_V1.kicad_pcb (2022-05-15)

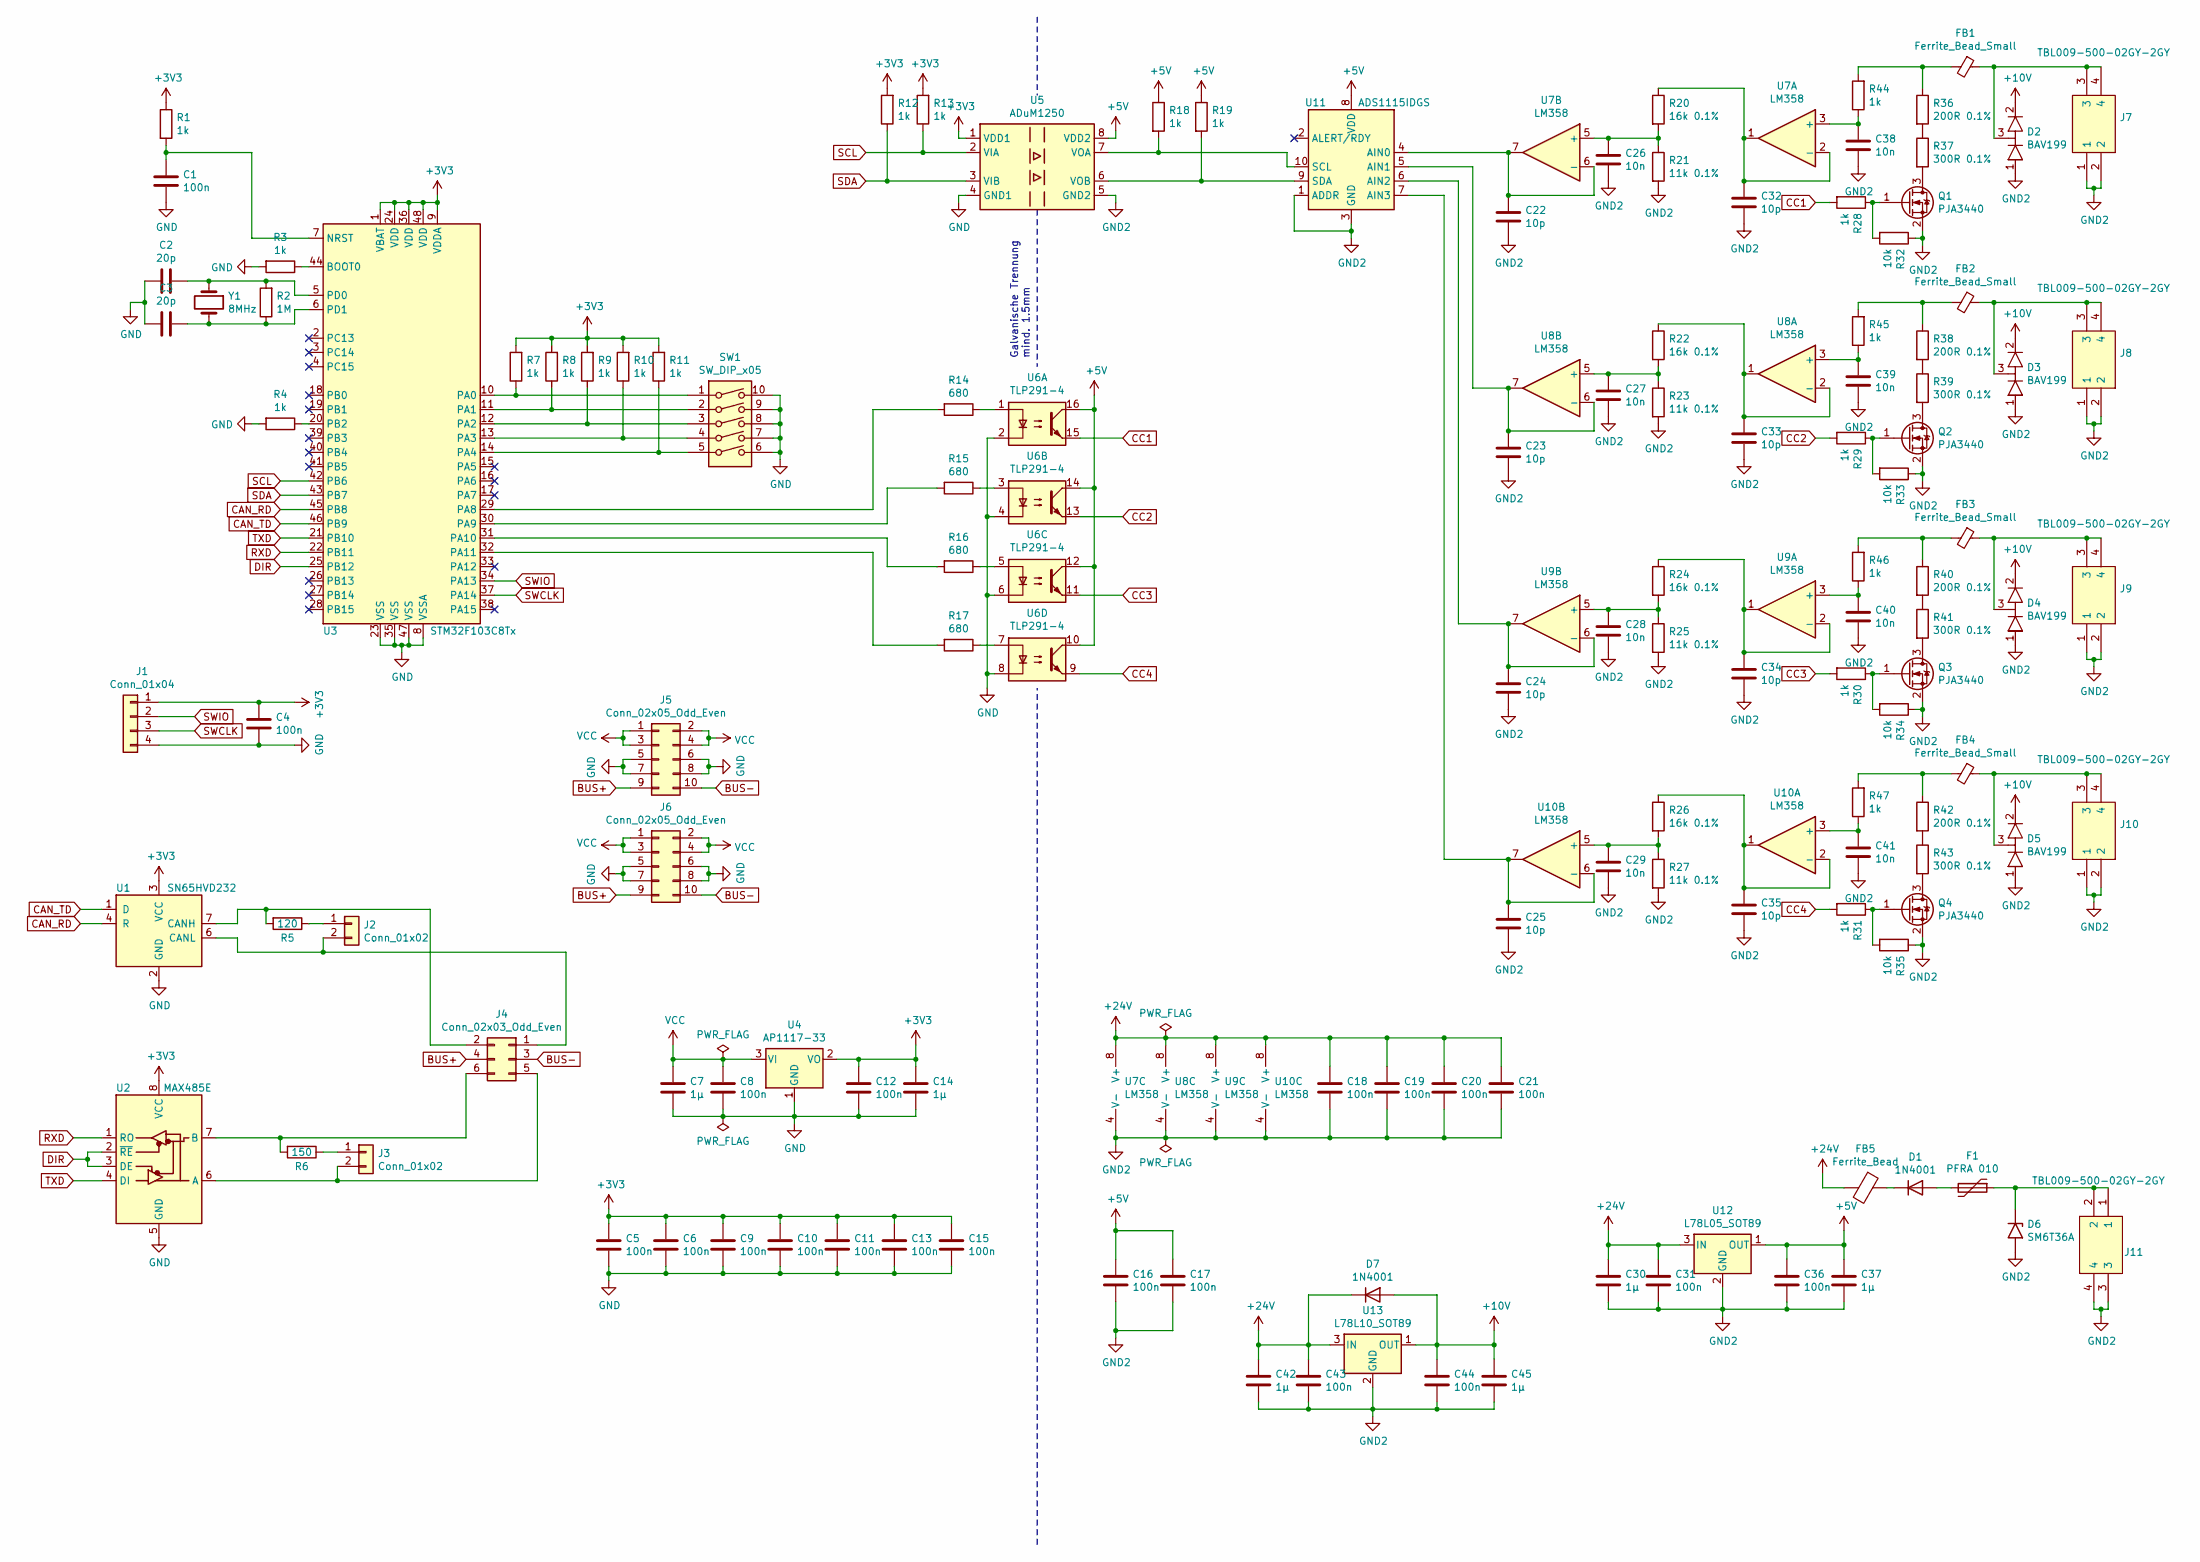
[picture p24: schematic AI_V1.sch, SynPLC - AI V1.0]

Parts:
C1, C4, C5, C6, C8, C9, C10, C11, C12, C13, C15, C16, C17, C18, C19, C20, C21, C31, C36, C43, C44: 100n; C_0805_2012Metric_Pad1.18x1.45mm_HandSolder
C2, C3: 20p; C_0805_2012Metric_Pad1.18x1.45mm_HandSolder
C7, C14, C30, C37, C42, C45: 1µ; C_0805_2012Metric_Pad1.18x1.45mm_HandSolder
C22, C23, C24, C25, C32, C33, C34, C35: 10p; C_0805_2012Metric_Pad1.18x1.45mm_HandSolder
C26, C27, C28, C29, C38, C39, C40, C41: 10n; C_0805_2012Metric_Pad1.18x1.45mm_HandSolder
D1, D7: 1N4001; D_MELF
D2, D3, D4, D5: BAV199; SOT-23
D6: SM6T36A; D_SMB
F1: PFRA 010; R_Axial_DIN0204_L3.6mm_D1.6mm_P5.08mm_Horizontal
FB1, FB2, FB3, FB4: Ferrite_Bead_Small; SMB-001
FB5: Ferrite_Bead; SMB-002
J1: Conn_01x04; PinHeader_1x04_P2.54mm_Horizontal
J2, J3: Conn_01x02; PinHeader_1x02_P2.54mm_Vertical
J4: Conn_02x03_Odd_Even; PinHeader_2x03_P2.54mm_Vertical
J5, J6: Conn_02x05_Odd_Even; PinHeader_2x05_P2.54mm_Horizontal
J7, J8, J9, J10, J11: TBL009-500-02GY-2GY; TBL00950002GY2GY; Manufacturer_Part_Number TBL009-500-02GY-2GY; Mouser Part Number 490-TBL00950002GY2GY
Q1, Q2, Q3, Q4: PJA3440; SOT-23
R1, R3, R4, R7, R8, R9, R10, R11, R12, R13, R18, R19, R28, R29, R30, R31, R44, R45, R46, R47: 1k; R_0805_2012Metric_Pad1.20x1.40mm_HandSolder
R2: 1M; R_0805_2012Metric_Pad1.20x1.40mm_HandSolder
R5: 120; R_0805_2012Metric_Pad1.20x1.40mm_HandSolder
R6: 150; R_0805_2012Metric_Pad1.20x1.40mm_HandSolder
R14, R15, R16, R17: 680; R_0805_2012Metric_Pad1.20x1.40mm_HandSolder
R20, R22, R24, R26: 16k 0.1%; R_0805_2012Metric_Pad1.20x1.40mm_HandSolder
R21, R23, R25, R27: 11k 0.1%; R_0805_2012Metric_Pad1.20x1.40mm_HandSolder
R32, R33, R34, R35: 10k; R_0805_2012Metric_Pad1.20x1.40mm_HandSolder
R36, R38, R40, R42: 200R 0.1%; R_0805_2012Metric_Pad1.20x1.40mm_HandSolder
R37, R39, R41, R43: 300R 0.1%; R_0805_2012Metric_Pad1.20x1.40mm_HandSolder
SW1: SW_DIP_x05; DIP-10_W7.62mm_Socket
U1: SN65HVD232; SOIC-8_3.9x4.9mm_P1.27mm
U2: MAX485E; SOIC-8_3.9x4.9mm_P1.27mm
U3: STM32F103C8Tx; LQFP-48_7x7mm_P0.5mm
U4: AP1117-33; SOT-223-3_TabPin2
U5: ADuM1250; SOIC-8_3.9x4.9mm_P1.27mm
U6: TLP291-4; SOIC-16_4.55x10.3mm_P1.27mm
U7, U8, U9, U10: LM358; SOIC-8_3.9x4.9mm_P1.27mm
U11: ADS1115IDGS; TSSOP-10_3x3mm_P0.5mm
U12: L78L05_SOT89; SOT-89-3
U13: L78L10_SOT89; SOT-89-3
Y1: 8MHz; Crystal_SMD_HC49-SD

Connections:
+3V3: C4.1, C5.1, C6.1, C9.1, C10.1, C11.1, C12.1, C13.1, C14.1, C15.1, J1.1, R1.1, R7.2, R8.2, R9.2, R10.2, R11.2, R12.2, R13.2, U1.3 (VCC), U2.8 (VCC), U3.1 (VBAT), U3.9 (VDDA), U3.24 (VDD), U3.36 (VDD), U3.48 (VDD), U4.2 (VO), U5.1 (VDD1)
+5V: C16.2, C17.2, C36.2, C37.2, R18.1, R19.1, U5.8 (VDD2), U6.10, U6.12, U6.14, U6.16, U11.8 (VDD), U12.1 (OUT)
+10V: C44.2, C45.2, D2.2, D3.2, D4.2, D5.2, D7.2 (A), U13.1 (OUT)
+24V: C18.2, C19.2, C20.2, C21.2, C30.2, C31.2, C42.2, C43.2, D7.1 (K), FB5.2, U7.8 (V+), U8.8 (V+), U9.8 (V+), U10.8 (V+), U12.3 (IN), U13.3 (IN)
BUS+: J4.4, J5.9, J6.9
BUS-: J4.3, J5.10, J6.10
CAN_RD: U1.4 (R), U3.45 (PB8)
CAN_TD: U1.1 (D), U3.46 (PB9)
CC1: R28.2, U6.15
CC2: R29.2, U6.13
CC3: R30.2, U6.11
CC4: R31.2, U6.9
DIR: U2.2 (~RE), U2.3 (DE), U3.25 (PB12)
GND: C1.1, C2.1, C3.1, C4.2, C5.2, C6.2, C7.2, C8.2, C9.2, C10.2, C11.2, C12.2, C13.2, C14.2, C15.2, J1.4, J5.5, J5.6, J5.7, J5.8, J6.5, J6.6, J6.7, J6.8, R3.2, R4.2, SW1.6, SW1.7, SW1.8, SW1.9, SW1.10, U1.2 (GND), U2.5 (GND), U3.8 (VSSA), U3.23 (VSS), U3.35 (VSS), U3.47 (VSS), U4.1 (GND), U5.4 (GND1), U6.2, U6.4, U6.6, U6.8
GND2: C16.1, C17.1, C18.1, C19.1, C20.1, C21.1, C22.1, C23.1, C24.1, C25.1, C26.1, C27.1, C28.1, C29.1, C30.1, C31.1, C32.1, C33.1, C34.1, C35.1, C36.1, C37.1, C38.1, C39.1, C40.1, C41.1, C42.1, C43.1, C44.1, C45.1, D2.1, D3.1, D4.1, D5.1, D6.2 (A2), J7.1, J7.2, J8.1, J8.2, J9.1, J9.2, J10.1, J10.2, J11.3, J11.4, Q1.2 (S), Q2.2 (S), Q3.2 (S), Q4.2 (S), R21.2, R23.2, R25.2, R27.2, R32.1, R33.1, R34.1, R35.1, U5.5 (GND2), U7.4 (V-), U8.4 (V-), U9.4 (V-), U10.4 (V-), U11.1 (ADDR), U11.3 (GND), U12.2 (GND), U13.2 (GND)
unnamed: C1.2, R1.2, U3.7 (NRST)
unnamed: C2.2, R2.2, U3.5 (PD0), Y1.1
unnamed: C3.2, R2.1, U3.6 (PD1), Y1.2
unnamed: C22.2, U7.6 (-), U7.7, U11.4 (AIN0)
unnamed: C23.2, U8.6 (-), U8.7, U11.5 (AIN1)
unnamed: C24.2, U9.6 (-), U9.7, U11.6 (AIN2)
unnamed: C25.2, U10.6 (-), U10.7, U11.7 (AIN3)
unnamed: C26.2, R20.2, R21.1, U7.5 (+)
unnamed: C27.2, R22.2, R23.1, U8.5 (+)
unnamed: C28.2, R24.2, R25.1, U9.5 (+)
unnamed: C29.2, R26.2, R27.1, U10.5 (+)
unnamed: C32.2, R20.1, U7.1, U7.2 (-)
unnamed: C33.2, R22.1, U8.1, U8.2 (-)
unnamed: C34.2, R24.1, U9.1, U9.2 (-)
unnamed: C35.2, R26.1, U10.1, U10.2 (-)
unnamed: C38.2, R44.1, U7.3 (+)
unnamed: C39.2, R45.1, U8.3 (+)
unnamed: C40.2, R46.1, U9.3 (+)
unnamed: C41.2, R47.1, U10.3 (+)
unnamed: D1.1 (K), FB5.1
unnamed: D1.2 (A), F1.2
unnamed: D2.3, FB1.1, J7.3, J7.4
unnamed: D3.3, FB2.1, J8.3, J8.4
unnamed: D4.3, FB3.1, J9.3, J9.4
unnamed: D5.3, FB4.1, J10.3, J10.4
unnamed: D6.1 (A1), F1.1, J11.1, J11.2
unnamed: FB1.2, R36.1, R44.2
unnamed: FB2.2, R38.1, R45.2
unnamed: FB3.2, R40.1, R46.2
unnamed: FB4.2, R42.1, R47.2
unnamed: J2.1, R5.1
unnamed: J2.2, J4.1, U1.6 (CANL)
unnamed: J3.1, R6.1
unnamed: J3.2, J4.5, U2.6 (A)
unnamed: J4.2, R5.2, U1.7 (CANH)
unnamed: J4.6, R6.2, U2.7 (B)
unnamed: Q1.1 (G), R28.1, R32.2
unnamed: Q1.3 (D), R37.2
unnamed: Q2.1 (G), R29.1, R33.2
unnamed: Q2.3 (D), R39.2
unnamed: Q3.1 (G), R30.1, R34.2
unnamed: Q3.3 (D), R41.2
unnamed: Q4.1 (G), R31.1, R35.2
unnamed: Q4.3 (D), R43.2
unnamed: R3.1, U3.44 (BOOT0)
unnamed: R4.1, U3.20 (PB2)
unnamed: R7.1, SW1.1, U3.10 (PA0)
unnamed: R8.1, SW1.2, U3.11 (PA1)
unnamed: R9.1, SW1.3, U3.12 (PA2)
unnamed: R10.1, SW1.4, U3.13 (PA3)
unnamed: R11.1, SW1.5, U3.14 (PA4)
unnamed: R14.1, U6.1
unnamed: R14.2, U3.29 (PA8)
unnamed: R15.1, U6.3
unnamed: R15.2, U3.30 (PA9)
unnamed: R16.1, U6.5
unnamed: R16.2, U3.31 (PA10)
unnamed: R17.1, U6.7
unnamed: R17.2, U3.32 (PA11)
unnamed: R18.2, U5.7 (VOA), U11.10 (SCL)
unnamed: R19.2, U5.6 (VOB), U11.9 (SDA)
unnamed: R36.2, R37.1
unnamed: R38.2, R39.1
unnamed: R40.2, R41.1
unnamed: R42.2, R43.1
RXD: U2.1 (RO), U3.22 (PB11)
SCL: R13.1, U3.42 (PB6), U5.2 (VIA)
SDA: R12.1, U3.43 (PB7), U5.3 (VIB)
SWCLK: J1.3, U3.37 (PA14)
SWIO: J1.2, U3.34 (PA13)
TXD: U2.4 (DI), U3.21 (PB10)
VCC: C7.1, C8.1, J5.1, J5.2, J5.3, J5.4, J6.1, J6.2, J6.3, J6.4, U4.3 (VI)

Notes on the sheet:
Galvanische Trennung mind. 1.5mm

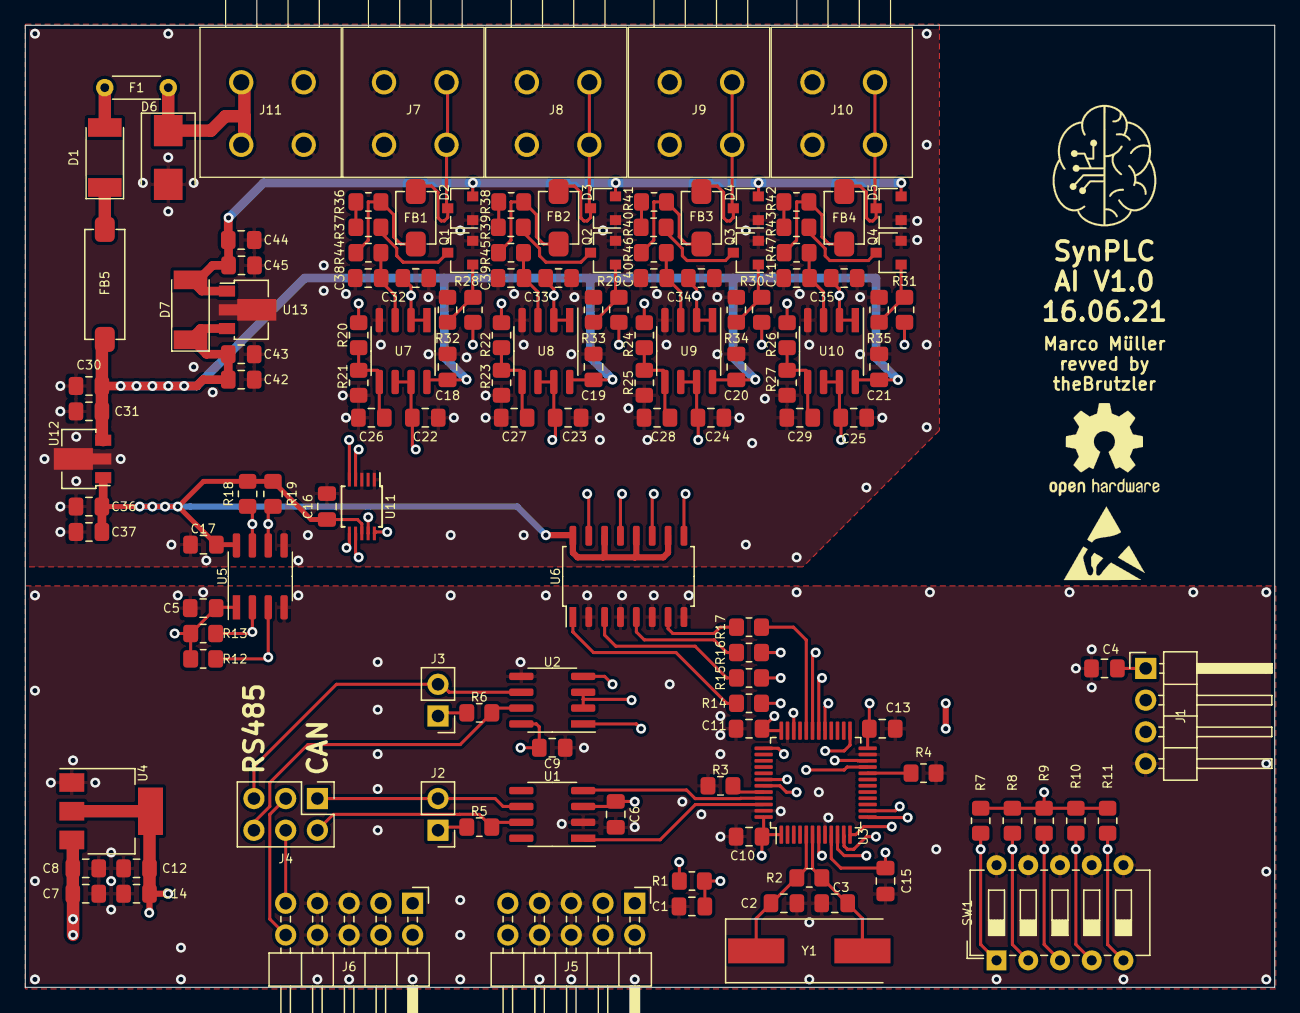
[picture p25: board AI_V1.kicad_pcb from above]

Board: 4 copper layers, 100.0 x 77.0 mm, 135 parts (0 on the bottom side), 87 nets.

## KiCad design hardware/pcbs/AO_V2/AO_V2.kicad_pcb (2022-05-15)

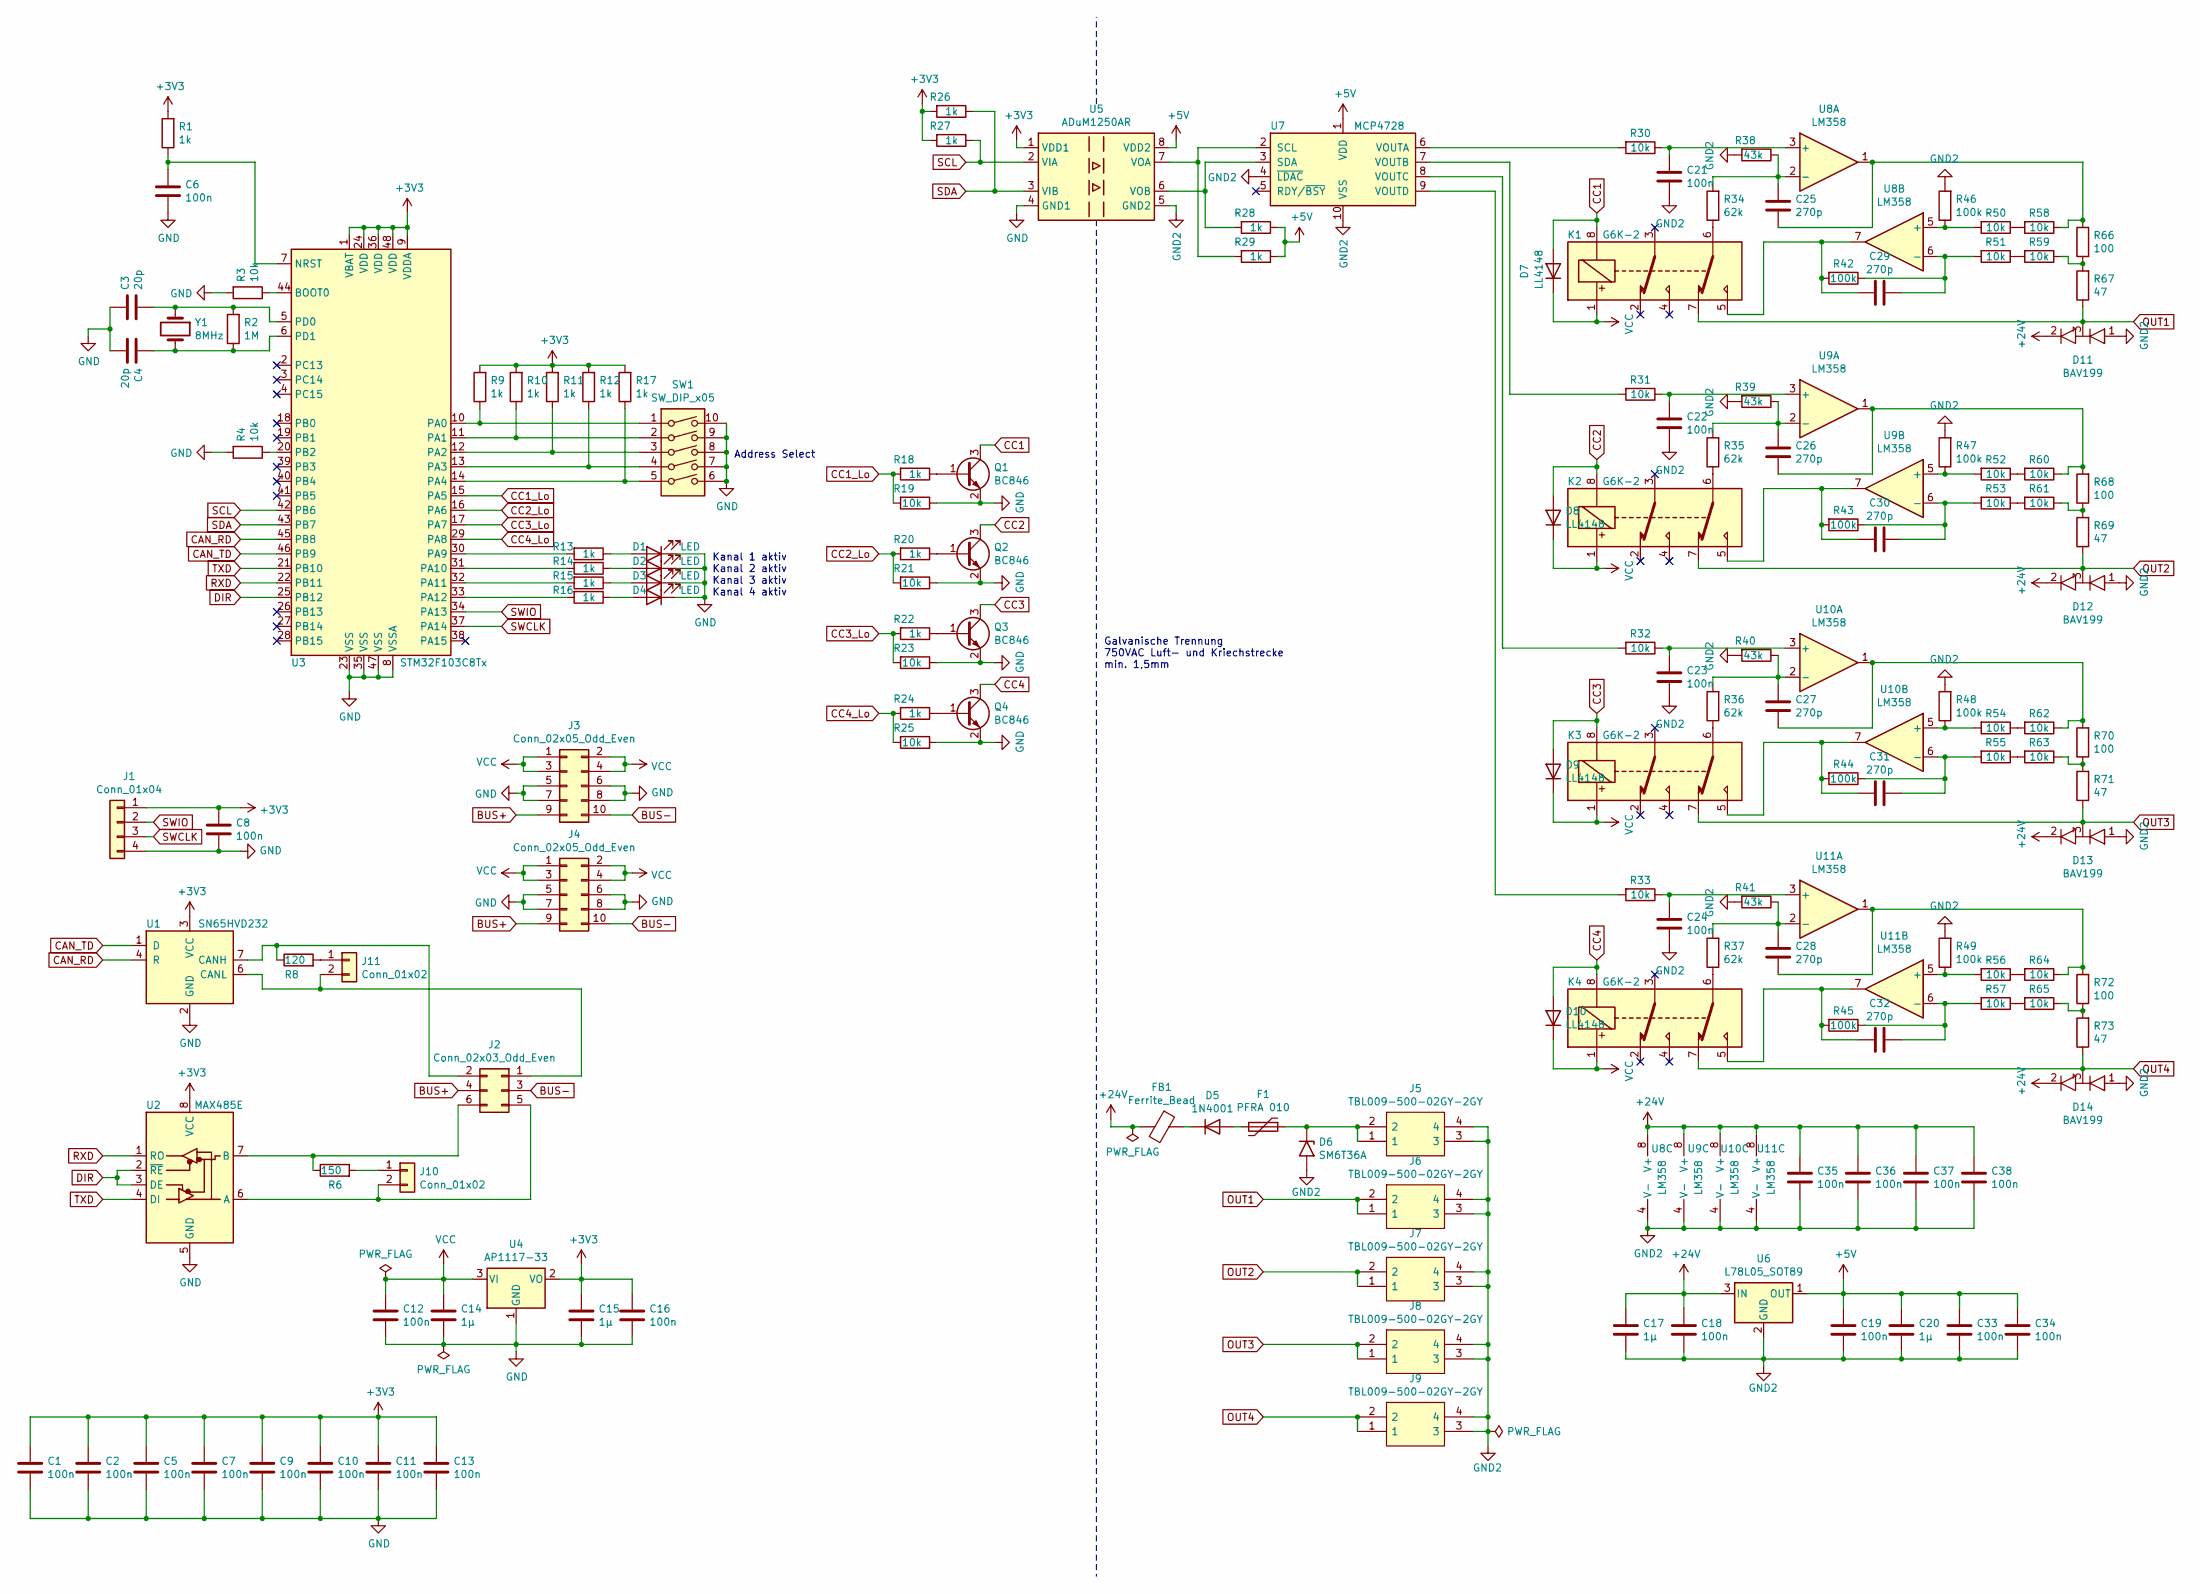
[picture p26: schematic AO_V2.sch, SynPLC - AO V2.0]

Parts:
C1, C2, C5, C6, C7, C8, C9, C10, C11, C12, C13, C16, C18, C19, C21, C22, C23, C24, C33, C34, C35, C36, C37, C38: 100n; C_0805_2012Metric_Pad1.18x1.45mm_HandSolder
C3, C4: 20p; C_0805_2012Metric_Pad1.18x1.45mm_HandSolder
C14, C15, C17, C20: 1µ; C_0805_2012Metric_Pad1.18x1.45mm_HandSolder
C25, C26, C27, C28, C29, C30, C31, C32: 270p; C_0805_2012Metric_Pad1.18x1.45mm_HandSolder
D1, D2, D3, D4: LED; LED_D3.0mm
D5: 1N4001; D_DO-41_SOD81_P10.16mm_Horizontal
D6: SM6T36A; D_SMB
D7, D8, D9, D10: LL4148; D_MiniMELF
D11, D12, D13, D14: BAV199; SOT-23
F1: PFRA 010; R_Axial_DIN0204_L3.6mm_D1.6mm_P5.08mm_Horizontal
FB1: Ferrite_Bead; SMB-002
J1: Conn_01x04; PinHeader_1x04_P2.54mm_Horizontal
J2: Conn_02x03_Odd_Even; PinHeader_2x03_P2.54mm_Vertical
J3, J4: Conn_02x05_Odd_Even; PinHeader_2x05_P2.54mm_Horizontal
J5, J6, J7, J8, J9: TBL009-500-02GY-2GY; TBL00950002GY2GY; Manufacturer_Part_Number TBL009-500-02GY-2GY; Mouser Part Number 490-TBL00950002GY2GY
J10, J11: Conn_01x02; PinHeader_1x02_P2.54mm_Vertical
K1, K2, K3, K4: G6K-2; Relay_DPDT_Omron_G6K-2G
Q1, Q2, Q3, Q4: BC846; SOT-23
R1, R9, R10, R11, R12, R13, R14, R15, R16, R17, R18, R20, R22, R24, R26, R27, R28, R29: 1k; R_0805_2012Metric
R2: 1M; R_0805_2012Metric
R3, R4, R19, R21, R23, R25, R30, R31, R32, R33, R50, R51, R52, R53, R54, R55, R56, R57, R58, R59, R60, R61, R62, R63, R64, R65: 10k; R_0805_2012Metric
R6: 150; R_0805_2012Metric
R8: 120; R_0805_2012Metric
R34, R35, R36, R37: 62k; R_0805_2012Metric
R38, R39, R40, R41: 43k; R_0805_2012Metric
R42, R43, R44, R45, R46, R47, R48, R49: 100k; R_0805_2012Metric
R66, R68, R70, R72: 100; R_0805_2012Metric
R67, R69, R71, R73: 47; R_0805_2012Metric
SW1: SW_DIP_x05; DIP-10_W7.62mm_Socket
U1: SN65HVD232; SOIC-8_3.9x4.9mm_P1.27mm
U2: MAX485E; SOP-8_3.9x4.9mm_P1.27mm
U3: STM32F103C8Tx; LQFP-48_7x7mm_P0.5mm
U4: AP1117-33; SOT-223-3_TabPin2
U5: ADuM1250AR; SOIC-8_3.9x4.9mm_P1.27mm
U6: L78L05_SOT89; SOT-89-3
U7: MCP4728; MSOP-10_3x3mm_P0.5mm
U8, U9, U10, U11: LM358; SO-8_3.9x4.9mm_P1.27mm
Y1: 8MHz; Crystal_SMD_HC49-SD

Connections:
+3V3: C1.1, C2.1, C5.1, C7.1, C8.1, C9.1, C10.1, C11.1, C13.1, C15.1, C16.1, J1.1, R1.2, R9.2, R10.2, R11.2, R12.2, R17.2, R26.2, R27.2, U1.3 (VCC), U2.8 (VCC), U3.1 (VBAT), U3.9 (VDDA), U3.24 (VDD), U3.36 (VDD), U3.48 (VDD), U4.2 (VO), U5.1 (VDD1)
+5V: C19.1, C20.1, C33.1, C34.1, R28.1, R29.1, U5.8 (VDD2), U6.1 (OUT), U7.1 (VDD)
+24V: C17.1, C18.1, C35.1, C36.1, C37.1, C38.1, D11.2, D12.2, D13.2, D14.2, FB1.2, U6.3 (IN), U8.8 (V+), U9.8 (V+), U10.8 (V+), U11.8 (V+)
BUS+: J2.4, J3.9, J4.9
BUS-: J2.3, J3.10, J4.10
CAN_RD: U1.4 (R), U3.45 (PB8)
CAN_TD: U1.1 (D), U3.46 (PB9)
CC1: D7.2 (A), K1.8, Q1.3 (C)
CC1_Lo: R18.2, R19.2, U3.15 (PA5)
CC2: D8.2 (A), K2.8, Q2.3 (C)
CC2_Lo: R20.2, R21.2, U3.16 (PA6)
CC3: D9.2 (A), K3.8, Q3.3 (C)
CC3_Lo: R22.2, R23.2, U3.17 (PA7)
CC4: D10.2 (A), K4.8, Q4.3 (C)
CC4_Lo: R24.2, R25.2, U3.29 (PA8)
DIR: U2.2 (~RE), U2.3 (DE), U3.25 (PB12)
GND: C1.2, C2.2, C3.1, C4.2, C5.2, C6.2, C7.2, C8.2, C9.2, C10.2, C11.2, C12.2, C13.2, C14.2, C15.2, C16.2, D1.1 (K), D2.1 (K), D3.1 (K), D4.1 (K), J1.4, J3.5, J3.6, J3.7, J3.8, J4.5, J4.6, J4.7, J4.8, Q1.2 (E), Q2.2 (E), Q3.2 (E), Q4.2 (E), R3.2, R4.2, R19.1, R21.1, R23.1, R25.1, SW1.6, SW1.7, SW1.8, SW1.9, SW1.10, U1.2 (GND), U2.5 (GND), U3.8 (VSSA), U3.23 (VSS), U3.35 (VSS), U3.47 (VSS), U4.1 (GND), U5.4 (GND1)
GND2: C17.2, C18.2, C19.2, C20.2, C21.2, C22.2, C23.2, C24.2, C33.2, C34.2, C35.2, C36.2, C37.2, C38.2, D6.2 (A2), D11.1, D12.1, D13.1, D14.1, J5.3, J5.4, J6.3, J6.4, J7.3, J7.4, J8.3, J8.4, J9.3, J9.4, R38.2, R39.2, R40.2, R41.2, R46.2, R47.2, R48.2, R49.2, U5.5 (GND2), U6.2 (GND), U7.4 (~LDAC), U7.10 (VSS), U8.4 (V-), U9.4 (V-), U10.4 (V-), U11.4 (V-)
unnamed: C3.2, R2.2, U3.5 (PD0), Y1.1
unnamed: C4.1, R2.1, U3.6 (PD1), Y1.2
unnamed: C6.1, R1.1, U3.7 (NRST)
unnamed: C21.1, R30.1, U8.3 (+)
unnamed: C22.1, R31.1, U9.3 (+)
unnamed: C23.1, R32.1, U10.3 (+)
unnamed: C24.1, R33.1, U11.3 (+)
unnamed: C25.1, R34.2, R38.1, U8.2 (-)
unnamed: C25.2, R58.1, R66.2, U8.1
unnamed: C26.1, R35.2, R39.1, U9.2 (-)
unnamed: C26.2, R60.1, R68.2, U9.1
unnamed: C27.1, R36.2, R40.1, U10.2 (-)
unnamed: C27.2, R62.1, R70.2, U10.1
unnamed: C28.1, R37.2, R41.1, U11.2 (-)
unnamed: C28.2, R64.1, R72.2, U11.1
unnamed: C29.1, K1.5, R42.2, U8.7
unnamed: C29.2, R42.1, R51.2, U8.6 (-)
unnamed: C30.1, K2.5, R43.2, U9.7
unnamed: C30.2, R43.1, R53.2, U9.6 (-)
unnamed: C31.1, K3.5, R44.2, U10.7
unnamed: C31.2, R44.1, R55.2, U10.6 (-)
unnamed: C32.1, K4.5, R45.2, U11.7
unnamed: C32.2, R45.1, R57.2, U11.6 (-)
unnamed: D1.2 (A), R13.1
unnamed: D2.2 (A), R14.1
unnamed: D3.2 (A), R15.1
unnamed: D4.2 (A), R16.1
unnamed: D5.1 (K), FB1.1
unnamed: D5.2 (A), F1.2
unnamed: D6.1 (A1), F1.1, J5.1, J5.2
unnamed: J2.2, R8.1, U1.7 (CANH)
unnamed: J2.6, R6.1, U2.7 (B)
unnamed: J10.1, R6.2
unnamed: J2.5, J10.2, U2.6 (A)
unnamed: J11.1, R8.2
unnamed: J2.1, J11.2, U1.6 (CANL)
unnamed: K1.6, R34.1
unnamed: K2.6, R35.1
unnamed: K3.6, R36.1
unnamed: K4.6, R37.1
unnamed: Q1.1 (B), R18.1
unnamed: Q2.1 (B), R20.1
unnamed: Q3.1 (B), R22.1
unnamed: Q4.1 (B), R24.1
unnamed: R3.1, U3.44 (BOOT0)
unnamed: R4.1, U3.20 (PB2)
unnamed: R9.1, SW1.1, U3.10 (PA0)
unnamed: R10.1, SW1.2, U3.11 (PA1)
unnamed: R11.1, SW1.3, U3.12 (PA2)
unnamed: R12.1, SW1.4, U3.13 (PA3)
unnamed: R13.2, U3.30 (PA9)
unnamed: R14.2, U3.31 (PA10)
unnamed: R15.2, U3.32 (PA11)
unnamed: R16.2, U3.33 (PA12)
unnamed: R17.1, SW1.5, U3.14 (PA4)
unnamed: R28.2, U5.6 (VOB), U7.3 (SDA)
unnamed: R29.2, U5.7 (VOA), U7.2 (SCL)
unnamed: R30.2, U7.6 (VOUTA)
unnamed: R31.2, U7.7 (VOUTB)
unnamed: R32.2, U7.8 (VOUTC)
unnamed: R33.2, U7.9 (VOUTD)
unnamed: R46.1, R50.2, U8.5 (+)
unnamed: R47.1, R52.2, U9.5 (+)
unnamed: R48.1, R54.2, U10.5 (+)
unnamed: R49.1, R56.2, U11.5 (+)
unnamed: R50.1, R58.2
unnamed: R51.1, R59.2
unnamed: R52.1, R60.2
unnamed: R53.1, R61.2
unnamed: R54.1, R62.2
unnamed: R55.1, R63.2
unnamed: R56.1, R64.2
unnamed: R57.1, R65.2
unnamed: R59.1, R66.1, R67.2
unnamed: R61.1, R68.1, R69.2
unnamed: R63.1, R70.1, R71.2
unnamed: R65.1, R72.1, R73.2
OUT1: D11.3, J6.1, J6.2, K1.7, R67.1
OUT2: D12.3, J7.1, J7.2, K2.7, R69.1
OUT3: D13.3, J8.1, J8.2, K3.7, R71.1
OUT4: D14.3, J9.1, J9.2, K4.7, R73.1
RXD: U2.1 (RO), U3.22 (PB11)
SCL: R27.1, U3.42 (PB6), U5.2 (VIA)
SDA: R26.1, U3.43 (PB7), U5.3 (VIB)
SWCLK: J1.3, U3.37 (PA14)
SWIO: J1.2, U3.34 (PA13)
TXD: U2.4 (DI), U3.21 (PB10)
VCC: C12.1, C14.1, D7.1 (K), D8.1 (K), D9.1 (K), D10.1 (K), J3.1, J3.2, J3.3, J3.4, J4.1, J4.2, J4.3, J4.4, K1.1, K2.1, K3.1, K4.1, U4.3 (VI)

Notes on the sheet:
Address Select
Galvanische Trennung 750VAC Luft- und Kriechstrecke min. 1,5mm
Kanal 1 aktiv Kanal 2 aktiv Kanal 3 aktiv Kanal 4 aktiv

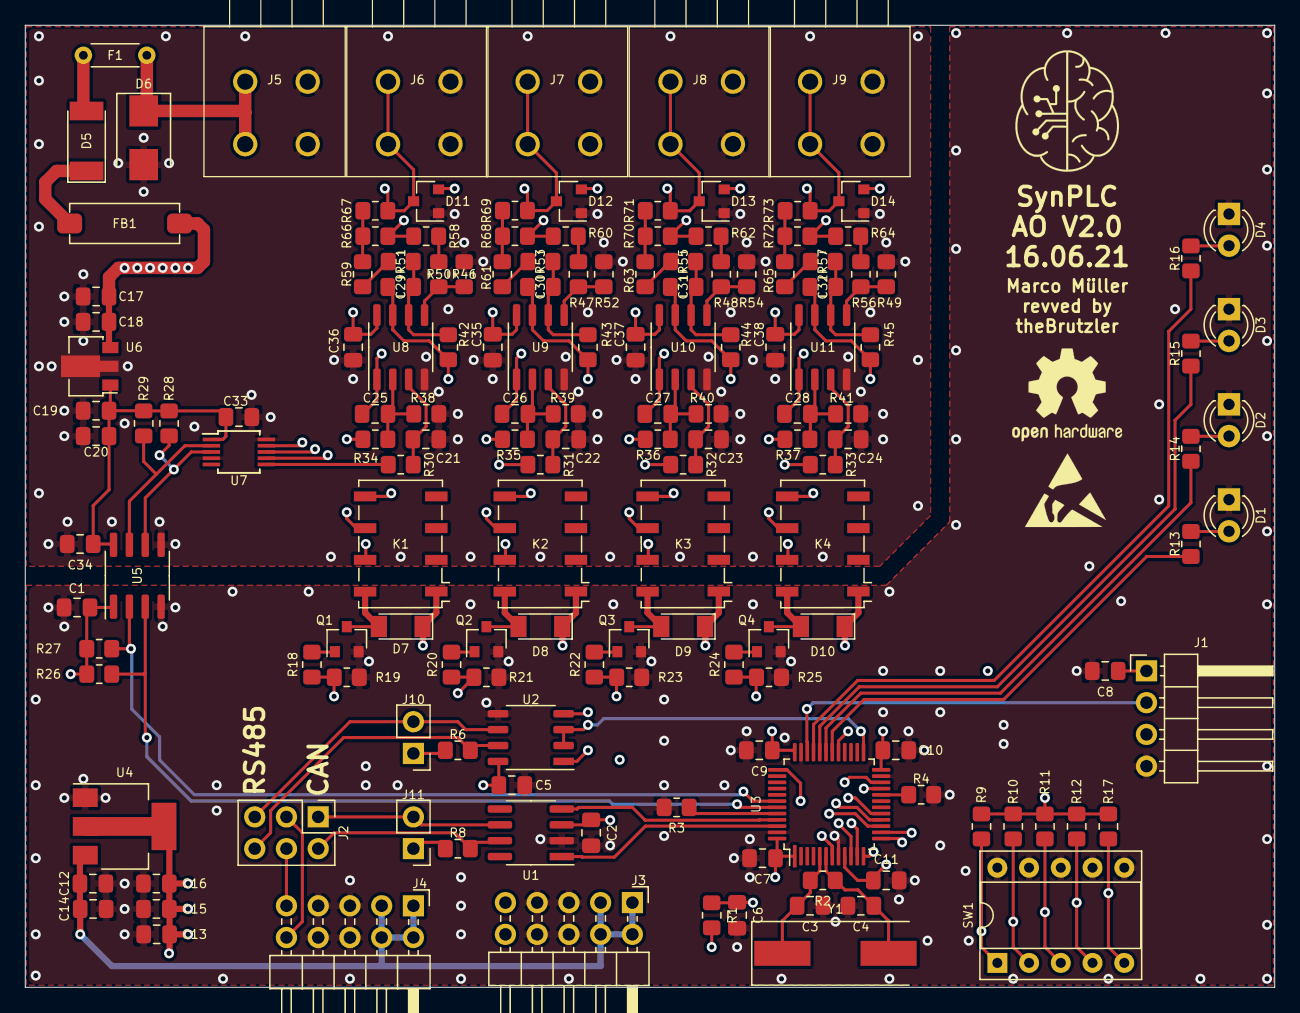
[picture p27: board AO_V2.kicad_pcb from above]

Board: 4 copper layers, 100.0 x 77.0 mm, 157 parts (0 on the bottom side), 106 nets.

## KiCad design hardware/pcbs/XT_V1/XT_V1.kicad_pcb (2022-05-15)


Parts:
C1, C4, C6, C7, C8, C9, C10, C11, C12, C14: 100n; C_0805_2012Metric_Pad1.18x1.45mm_HandSolder
C2, C3: 20p; C_0805_2012Metric_Pad1.18x1.45mm_HandSolder
C5, C13: 1µ; C_0805_2012Metric_Pad1.18x1.45mm_HandSolder
C15, C16, C17, C18: 10n; C_0805_2012Metric_Pad1.18x1.45mm_HandSolder
D1, D2: SM4007; D_MELF
J1: Conn_01x04; PinHeader_1x04_P2.54mm_Horizontal
J2, J3: Conn_01x02; PinHeader_1x02_P2.54mm_Vertical
J4: Conn_02x03_Odd_Even; PinHeader_2x03_P2.54mm_Vertical
J5, J6: Conn_02x05_Odd_Even; PinHeader_2x05_P2.54mm_Horizontal
J7, J8, J9, J10: TBL009-500-02GY-2GY; TBL00950002GY2GY; Manufacturer_Part_Number TBL009-500-02GY-2GY; Mouser Part Number 490-TBL00950002GY2GY
Q1, Q2, Q3, Q4, Q5, Q7: BC846; SOT-23
Q6, Q8, Q9, Q10: BT136-500; TO-220-3_Vertical
R1, R3, R4, R7, R8, R9, R10, R11, R12, R13, R14, R15, R17, R18, R23, R24: 1k; R_0805_2012Metric_Pad1.20x1.40mm_HandSolder
R2: 1M; R_0805_2012Metric_Pad1.20x1.40mm_HandSolder
R5: 120; R_0805_2012Metric_Pad1.20x1.40mm_HandSolder
R6: 150; R_0805_2012Metric_Pad1.20x1.40mm_HandSolder
R16, R19, R20, R22: max 360; R_0805_2012Metric_Pad1.20x1.40mm_HandSolder
R21, R26, R27, R28: 360; R_0805_2012Metric_Pad1.20x1.40mm_HandSolder
R25, R30, R31, R32: 330; R_0805_2012Metric_Pad1.20x1.40mm_HandSolder
R29, R35, R36, R37: 68; R_0805_2012Metric_Pad1.20x1.40mm_HandSolder
R33, R34: 56k; R_MELF_MMB-0207
SW1: SW_DIP_x05; SW_DIP_SPSTx05_Slide_6.7x14.26mm_W7.62mm_P2.54mm_LowProfile
U1: SN65HVD232; SOIC-8_3.9x4.9mm_P1.27mm
U2: MAX485E; SOIC-8_3.9x4.9mm_P1.27mm
U3: STM32F103C8Tx; LQFP-48_7x7mm_P0.5mm
U4: AP1117-33; SOT-223-3_TabPin2
U5, U7, U9, U10: MOC3043M; DIP-6_W8.89mm_SMDSocket_LongPads
U6, U8: TLP291; SOIC-4_4.55x2.6mm_P1.27mm
Y1: 8MHz; Crystal_SMD_HC49-SD

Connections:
+3V3: C1.1, C6.1, C8.1, C9.1, C10.1, C11.1, C12.1, C13.1, C14.1, J1.1, R1.1, R7.2, R8.2, R9.2, R10.2, R11.2, R13.1, R14.1, U1.3 (VCC), U2.8 (VCC), U3.1 (VBAT), U3.9 (VDDA), U3.24 (VDD), U3.36 (VDD), U3.48 (VDD), U4.2 (VO)
BUS+: J4.4, J5.9, J6.9
BUS-: J4.3, J5.10, J6.10
CAN_RD: U1.4 (R), U3.45 (PB8)
CAN_TD: U1.1 (D), U3.46 (PB9)
CH1: R12.2, U3.29 (PA8)
CH2: R15.2, U3.30 (PA9)
CH3: R17.2, U3.10 (PA0)
CH4: R18.2, U3.11 (PA1)
DIR: U2.2 (~RE), U2.3 (DE), U3.25 (PB12)
GND: C1.2, C2.2, C3.2, C4.2, C5.2, C6.2, C7.2, C8.2, C9.2, C10.2, C11.2, C12.2, C13.2, C14.2, J1.4, J5.5, J5.6, J5.7, J5.8, J6.5, J6.6, J6.7, J6.8, Q1.2 (E), Q2.2 (E), Q3.2 (E), Q4.2 (E), Q5.2 (E), Q7.2 (E), R3.2, R4.2, SW1.6, SW1.7, SW1.8, SW1.9, SW1.10, U1.2 (GND), U2.5 (GND), U3.8 (VSSA), U3.23 (VSS), U3.35 (VSS), U3.47 (VSS), U4.1 (GND)
unnamed: C2.1, R2.1, U3.5 (PD0), Y1.1
unnamed: C3.1, R2.2, U3.6 (PD1), Y1.2
unnamed: C4.1, R1.2, U3.7 (NRST)
unnamed: C15.1, R35.2
unnamed: C15.2, J8.3, J8.4, Q8.1 (A1), R30.1
unnamed: C16.1, R29.2
unnamed: C16.2, J8.1, J8.2, Q6.1 (A1), R25.1
unnamed: C17.1, R36.2
unnamed: C17.2, J10.1, J10.2, Q9.1 (A1), R31.1
unnamed: C18.1, R37.2
unnamed: C18.2, J10.3, J10.4, Q10.1 (A1), R32.1
unnamed: D1.1 (K), R33.2, U6.1
unnamed: D1.2 (A), J7.1, J7.2, Q6.2 (A2), Q8.2 (A2), R21.1, R26.1, R29.1, R35.1, U6.2
unnamed: D2.1 (K), R34.2, U8.1
unnamed: D2.2 (A), J9.1, J9.2, Q9.2 (A2), Q10.2 (A2), R27.1, R28.1, R36.1, R37.1, U8.2
unnamed: J2.1, R5.1
unnamed: J2.2, J4.1, U1.6 (CANL)
unnamed: J3.1, R6.1
unnamed: J3.2, J4.5, U2.6 (A)
unnamed: J4.2, R5.2, U1.7 (CANH)
unnamed: J4.6, R6.2, U2.7 (B)
unnamed: J7.3, J7.4, R33.1
unnamed: J9.3, J9.4, R34.1
unnamed: Q1.1 (B), R12.1
unnamed: Q1.3 (C), U5.2
unnamed: Q2.1 (B), R23.2
unnamed: Q3.1 (B), R24.2
unnamed: Q4.1 (B), R15.1
unnamed: Q4.3 (C), U7.2
unnamed: Q5.1 (B), R17.1
unnamed: Q5.3 (C), U9.2
unnamed: Q6.3 (G), R25.2, U5.4
unnamed: Q7.1 (B), R18.1
unnamed: Q7.3 (C), U10.2
unnamed: Q8.3 (G), R30.2, U7.4
unnamed: Q9.3 (G), R31.2, U9.4
unnamed: Q10.3 (G), R32.2, U10.4
unnamed: R3.1, U3.44 (BOOT0)
unnamed: R4.1, U3.20 (PB2)
unnamed: R7.1, SW1.1, U3.12 (PA2)
unnamed: R8.1, SW1.2, U3.13 (PA3)
unnamed: R9.1, SW1.3, U3.14 (PA4)
unnamed: R10.1, SW1.4, U3.15 (PA5)
unnamed: R11.1, SW1.5, U3.16 (PA6)
unnamed: R16.1, U5.1
unnamed: R19.1, U7.1
unnamed: R20.1, U9.1
unnamed: R21.2, U5.6
unnamed: R22.1, U10.1
unnamed: R23.1, U6.3
unnamed: R24.1, U8.3
unnamed: R26.2, U7.6
unnamed: R27.2, U9.6
unnamed: R28.2, U10.6
RXD: U2.1 (RO), U3.22 (PB11)
SWCLK: J1.3, U3.37 (PA14)
SWIO: J1.2, U3.34 (PA13)
TXD: U2.4 (DI), U3.21 (PB10)
VCC: C5.1, C7.1, J5.1, J5.2, J5.3, J5.4, J6.1, J6.2, J6.3, J6.4, R16.2, R19.2, R20.2, R22.2, U4.3 (VI), U6.4, U8.4
ZC1: Q2.3 (C), R13.2, U3.33 (PA12)
ZC2: Q3.3 (C), R14.2, U3.38 (PA15)

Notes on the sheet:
AC 1
Galvanische Trennung mind. 1,5mm
Tim2_Ch2
Tim1_Ch1
Tim2_Ch1
Tim1_Ch2
Caps: C0805C103JARACTU (M) 56k: VIT ZC207 56K (R)

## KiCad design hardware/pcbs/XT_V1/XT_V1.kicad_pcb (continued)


Board: 4 copper layers, 100.0 x 77.0 mm, 89 parts (0 on the bottom side), 72 nets.

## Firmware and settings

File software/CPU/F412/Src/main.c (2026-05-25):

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
/* Includes ------------------------------------------------------------------*/
#include "main.h"
#include "can.h"
#include "fatfs.h"
#include "i2c.h"
#include "rtc.h"
#include "sdio.h"
#include "spi.h"
#include "tim.h"
#include "usart.h"
#include "usb_device.h"
#include "gpio.h"

/* USER CODE BEGIN Includes */
#include "synplc_cpu.h"
/* USER CODE END Includes */


void SystemClock_Config(void);
void PeriphCommonClock_Config(void);
/* USER CODE BEGIN PFP */
void Init_LEDs(void);
void timer_init(void);
void delay_us (uint16_t us);
void send_485(uint8_t *data, uint8_t bytes);
/* USER CODE END PFP */

/**
  * @brief  The application entry point.
  * @retval int
  */
int main(void)
{
  /* MCU Configuration--------------------------------------------------------*/

  /* Reset of all peripherals, Initializes the Flash interface and the Systick. */
  HAL_Init();

  /* Configure the system clock */
  SystemClock_Config();

/* Configure the peripherals common clocks */
  PeriphCommonClock_Config();

  /* Initialize all configured peripherals */
  MX_GPIO_Init();
  MX_CAN1_Init();
  //MX_RTC_Init();
  //MX_SDIO_SD_Init();
  MX_TIM1_Init();
  MX_TIM2_Init();
  MX_TIM3_Init();
  MX_TIM4_Init();
  MX_TIM5_Init();
  MX_TIM8_Init();
  MX_TIM9_Init();
  MX_TIM12_Init();
  MX_USART1_UART_Init();
  MX_USART2_UART_Init();
  //MX_FATFS_Init();
  MX_USB_DEVICE_Init();
  MX_I2C1_Init();
  MX_SPI2_Init();
  /* USER CODE BEGIN 2 */
  Init_LEDs();
  
  // Turn on LED_BOOT during initialization
  HAL_GPIO_WritePin(LED_BOOT_GPIO_Port, LED_BOOT_Pin, 1);
  
  timer_init();

  HAL_GPIO_WritePin(RS485_DIR_GPIO_Port, RS485_DIR_Pin, 0);

  HAL_Delay(500);


  uint8_t count = 0x0;

  uint8_t data1[5] = {0X5A, 0x21, 0x21, 0, 0};
  uint8_t data2[5] = {0X5A, 0x03, 0x10, 0, 0};
  uint8_t data3[5] = {0X5A, 0x22, 0x21, 0, 0};
  uint8_t data4[5] = {0X5A, 0x04, 0x10, 0, 0};
  uint8_t rec[5] = {0,0,0,0,0};
  uint8_t data_ao[6] = {0x5A, 0x60, 0, 0, 0, 0};
  uint16_t ao_val = 0;
  
  // Turn off LED_BOOT after initialization
  HAL_GPIO_WritePin(LED_BOOT_GPIO_Port, LED_BOOT_Pin, 0);
  
  // Initialize heartbeat timing
  uint32_t last_heartbeat_toggle = HAL_GetTick();
  
  // Initialize error state
  uint8_t error_flag = 0;
  uint32_t last_error_toggle = HAL_GetTick();
  uint8_t error_blink_count = 0;

  // Initialize SynPLC CPU library
  synplc_cpu_init();
  /* USER CODE END 2 */

  /* Infinite loop */
  /* USER CODE BEGIN WHILE */
  
  // Turn on LED_RUN to indicate PLC is running
  HAL_GPIO_WritePin(LED_RUN_GPIO_Port, LED_RUN_Pin, 1);
  
  while (1)
  {
    /* USER CODE END WHILE */

    /* USER CODE BEGIN 3 */
/*
//read DI
    data2[3] = data2[0] ^ data2[1] ^ data2[2] ^ 0xC5;
    send_485(data2, 4);

    delay_us(50);

    data4[3] = data4[0] ^ data4[1] ^ data4[2] ^ 0xC5;
    send_485(data4, 4);

    delay_us(50);
*/
//write DO
/*
    count = rand();
    data1[3] = count;
    data1[4] = data1[0] ^ data1[1] ^ data1[2] ^ data1[3] ^ 0xC5;
    send_485(data1, 5);
    HAL_UART_Receive(&huart1, rec, 2, 10);

    HAL_Delay(500);
    */

//    count = rand();
//    data3[3] = count;
//    data3[4] = data3[0] ^ data3[1] ^ data3[2] ^ data3[3] ^ 0xC5;
//    send_485(data3, 5);
//    HAL_UART_Receive(&huart1, rec, 2, 10);

//    HAL_Delay(50);

//write AO

    for(int i = 0; i < 4; i++)
    {
      // Use the new SynPLC library to write analog output
      uint8_t error = synplc_write_analog_output(0, i, ao_val);
      if (error != SYNPLC_ERR_NONE) {
        error_flag = 1;  // Set error flag on communication failure
      }
      HAL_Delay(10);
    }

    // Example usage of other library functions:
    // uint8_t di_data;
    // synplc_read_digital_input(1, &di_data);
    // synplc_write_digital_output(2, 0xFF);
    // uint16_t ai_value;
    // synplc_read_analog_input(3, 0, &ai_value);
    ao_val += 100;
    if(ao_val > 10000)
    {
      ao_val = 0;
    }
      
    HAL_Delay(10);
    
    // Heartbeat LED at 1Hz (toggle every 500ms)
    uint32_t current_time = HAL_GetTick();
    if (current_time - last_heartbeat_toggle >= 500) {
      HAL_GPIO_TogglePin(LED_HEARTBEAT_GPIO_Port, LED_HEARTBEAT_Pin);
      last_heartbeat_toggle = current_time;
    }
    
    // Error LED blinking (2Hz when error_flag is set)
    if (error_flag) {
      if (current_time - last_error_toggle >= 250) {  // 250ms for 2Hz blinking
        HAL_GPIO_TogglePin(LED_ERROR_GPIO_Port, LED_ERROR_Pin);
        last_error_toggle = current_time;
        error_blink_count++;
        if (error_blink_count >= 10) {  // Blink for 5 seconds (10 * 250ms * 2)
          error_flag = 0;
          error_blink_count = 0;
          HAL_GPIO_WritePin(LED_ERROR_GPIO_Port, LED_ERROR_Pin, 0);  // Ensure LED is off
        }
      }
    }
  }
  /* USER CODE END 3 */
}

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
/* USER CODE BEGIN 4 */

void send_485(uint8_t *data, uint8_t bytes)
{
  HAL_GPIO_WritePin(RS485_DIR_GPIO_Port, RS485_DIR_Pin, 1);
  HAL_GPIO_WritePin(LED_FLASH_GPIO_Port, LED_FLASH_Pin, 1);  // Turn on during transmission
  delay_us(1);
  HAL_UART_Transmit(&huart1, data, bytes, 1);
  delay_us(1);
  HAL_GPIO_WritePin(RS485_DIR_GPIO_Port, RS485_DIR_Pin, 0);
  HAL_GPIO_WritePin(LED_FLASH_GPIO_Port, LED_FLASH_Pin, 0);  // Turn off after transmission
}

void timer_init(void)
{
    HAL_TIM_Base_Start(&htim1);
}

void delay_us (uint16_t us)
{
	__HAL_TIM_SET_COUNTER(&htim1,0);  // set the counter value a 0
	while (__HAL_TIM_GET_COUNTER(&htim1) < us);  // wait for the counter to reach the us input in the parameter
}

void Init_LEDs(void)
{
  HAL_GPIO_WritePin(LED_BOOT_GPIO_Port, LED_BOOT_Pin, 0);           // LED 1
  HAL_GPIO_WritePin(LED_RUN_GPIO_Port, LED_RUN_Pin, 0);             // LED 2
  HAL_GPIO_WritePin(LED_FLASH_GPIO_Port, LED_FLASH_Pin, 0);         // LED 3
  HAL_GPIO_WritePin(LED_HEARTBEAT_GPIO_Port, LED_HEARTBEAT_Pin, 0); // LED 4
  HAL_GPIO_WritePin(LED_ERROR_GPIO_Port, LED_ERROR_Pin, 0);         // LED 5
}

/* USER CODE END 4 */
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


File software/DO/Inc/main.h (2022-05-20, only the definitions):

#define ADR0_Pin GPIO_PIN_0
#define ADR0_GPIO_Port GPIOA
#define ADR1_Pin GPIO_PIN_1
#define ADR1_GPIO_Port GPIOA
#define ADR2_Pin GPIO_PIN_2
#define ADR2_GPIO_Port GPIOA
#define ADR3_Pin GPIO_PIN_3
#define ADR3_GPIO_Port GPIOA
#define ADR4_Pin GPIO_PIN_4
#define ADR4_GPIO_Port GPIOA
#define CH1_Pin GPIO_PIN_5
#define CH1_GPIO_Port GPIOA
#define CH2_Pin GPIO_PIN_6
#define CH2_GPIO_Port GPIOA
#define CH3_Pin GPIO_PIN_7
#define CH3_GPIO_Port GPIOA
#define FB1_Pin GPIO_PIN_0
#define FB1_GPIO_Port GPIOB
#define FB2_Pin GPIO_PIN_1
#define FB2_GPIO_Port GPIOB
#define FB3_Pin GPIO_PIN_2
#define FB3_GPIO_Port GPIOB
#define DIR_Pin GPIO_PIN_12
#define DIR_GPIO_Port GPIOB
#define CH4_Pin GPIO_PIN_8
#define CH4_GPIO_Port GPIOA
#define CH5_Pin GPIO_PIN_9
#define CH5_GPIO_Port GPIOA
#define CH6_Pin GPIO_PIN_10
#define CH6_GPIO_Port GPIOA
#define CH7_Pin GPIO_PIN_11
#define CH7_GPIO_Port GPIOA
#define CH8_Pin GPIO_PIN_12
#define CH8_GPIO_Port GPIOA
#define FB4_Pin GPIO_PIN_3
#define FB4_GPIO_Port GPIOB
#define FB5_Pin GPIO_PIN_4
#define FB5_GPIO_Port GPIOB
#define FB6_Pin GPIO_PIN_5
#define FB6_GPIO_Port GPIOB
#define FB7_Pin GPIO_PIN_6
#define FB7_GPIO_Port GPIOB
#define FB8_Pin GPIO_PIN_7
#define FB8_GPIO_Port GPIOB

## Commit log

2022-05-15 backup commit
    [AI_V1-B_Cu.gbr, AI_V1-B_Mask.gbr, AI_V1-B_Paste.gbr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]
2023-04-30 CPU Update Finish CPU V2 Design and finish CPU PiggyBack Board
    [CPU.brd, CPU_PiggyBack.kicad_pcb, CPU_PiggyBack.kicad_sch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]
2023-04-30 Overhaul Repo Cleanup Case for new CPU PiggyBack Update
    [AI_V1.kicad_pcb, AI_V1.sch, AO_V2.kicad_pcb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]
2023-04-30 case design for new CPU with piggyback
    [CPU_Case_PiggyBack-Case_CPU_PiggyBack.3mf, CPU_Case_PiggyBack-FrontCover.3mf, CPU_Case_PiggyBack-cover_logo.3mf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]
2023-05-02 CPU V2 Review
    [CPU_PiggyBack.kicad_pcb, CPU_PiggyBack.kicad_sch, CPU_V2.kicad_pcb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]
2023-06-11 GPN Update: Rewrote RS485 protocol with interrupts

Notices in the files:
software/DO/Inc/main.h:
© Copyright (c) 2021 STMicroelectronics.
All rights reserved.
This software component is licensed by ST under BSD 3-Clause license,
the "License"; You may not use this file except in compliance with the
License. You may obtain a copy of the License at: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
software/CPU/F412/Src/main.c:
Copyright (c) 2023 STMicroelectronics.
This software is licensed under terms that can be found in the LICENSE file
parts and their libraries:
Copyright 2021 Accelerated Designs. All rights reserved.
